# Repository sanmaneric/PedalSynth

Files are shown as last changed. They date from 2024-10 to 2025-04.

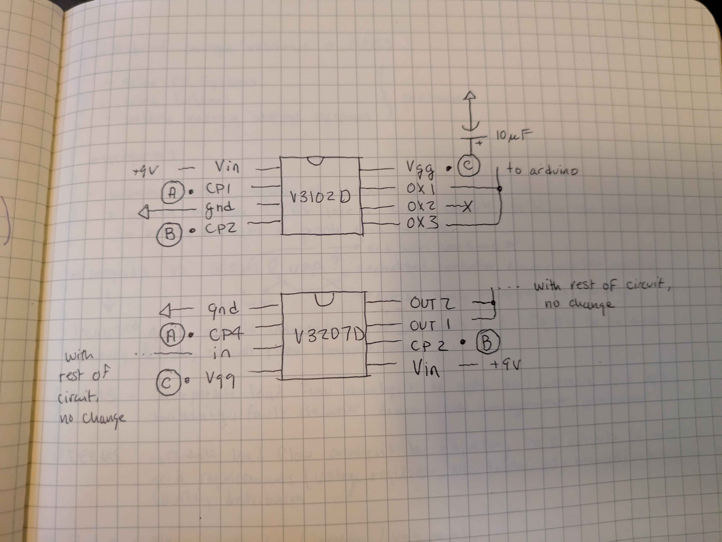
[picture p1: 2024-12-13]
Test Plan/chorus test plan.jpg

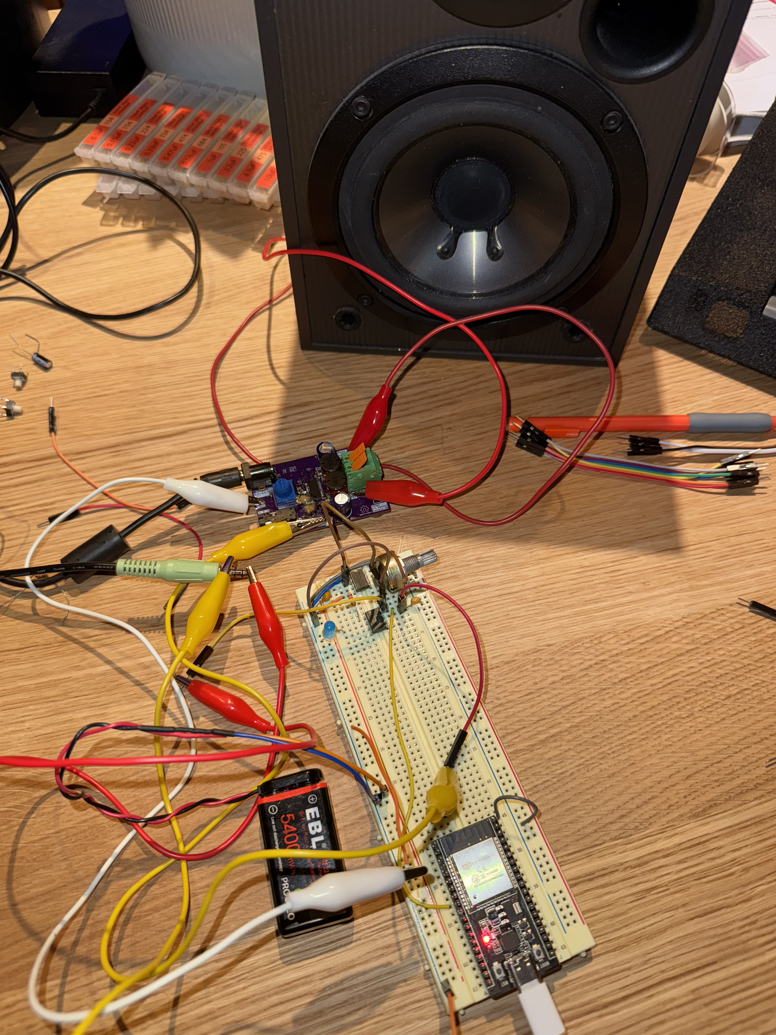
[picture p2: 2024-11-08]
Weekly Progress Reports/Progresss Photos/tremolo-mcu-amp-7Nov.jpg

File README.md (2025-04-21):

<h1 align="center">
  :notes: SynthBuddy :notes:
</h1>

<h2 align="center">
  A combination digital and analog synthesizer with integrated speaker amplifier.
</h2>

<div align="center">

  <a href="https://github.com/lifeparticle/Markdown-Cheatsheet/actions/workflows/readme-checker.yml">
    
  </a>

</div>

# PCB Designs
We have two KiCad projects in this repo. One for the Class-D Amp Dev Board (ordered week 2), and one for our project design. The naming of the KiCad project of the Dev Board is a misnomer.
 - [Amplifier Dev Board](https://github.com/sanmaneric/PedalSynth/tree/main/Electrical%20Design/PedalSynth)
 - [SynthBuddy Board](https://github.com/sanmaneric/PedalSynth/tree/main/Electrical%20Design/Modules/ECE%20411%20Project)

# Authors
PedalSynth is developed by Eric Sanman, Sierra Buckley, Chris Crider, and Chuong Vo as part of ECE411 at <a href="https://pdx.edu/engineering" style="color: green; text-decoration: underline;text-decoration-style: dotted;">Portland State University</a>
.

# License
SynthBuddy is licensed under a GNU/GPL v3 license.

# View Key Deliverables
Things Andrew would want to look at:
 - :white_check_mark: [View PDS](https://github.com/sanmaneric/PedalSynth/blob/main/Product%20Development/ProductDescriptionSpecification-Team8.rev1.2.pdf)
 - :date: [Browse Weekly Progress Reports](https://github.com/sanmaneric/PedalSynth/blob/main/Weekly%20Progress%20Reports/Weekly%20Progress%20Report.md)
  - :camera: [Progress Photos & Videos](https://github.com/sanmaneric/PedalSynth/tree/main/Weekly%20Progress%20Reports/Progresss%20Photos)
  - :date: [View Gantt Chart](https://github.com/sanmaneric/PedalSynth/blob/main/Gantt%20Chart/ECE%20411%20PWM%20Hybrid%20Synth%20Pedal.pdf)
 - :technologist: [View Code](https://github.com/sanmaneric/PedalSynth/tree/main/Programming)
 - :white_check_mark: [View KiCad PDF Exports](https://github.com/sanmaneric/PedalSynth/tree/main/Electrical%20Design/Docs)

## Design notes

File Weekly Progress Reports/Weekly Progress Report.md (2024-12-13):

# SynthBuddy Weekly Progress Report
## Report date: 2024-10-17

## Last Week (time in hours)
	- **Team Review**
		- We began to generate potential project ideas and discuss the best way to set up a collaboration site. A definitive project has already been chosen but generating additonal projects to "pick" is a bit more tricky then expected.
	- **Eric Sanman**
		- Began to set up collaboration site and look into using KiCad (3)
	- **Chuong Vo**
		- Began researching the best processor to use for the project and the differences between arduino microcontrollers and Atmel microcontrollers (2)
	- **Sierra Buckley **
		- watching kicad videos and becoming familiar with it (2)
		- researching effects pedals for our design (2)
	- **Chris Crider**
		- Began researching ideas for projects including effects for possible synth project (2)
		- learning kicad and git for use on the project (1)
	
##Next Week
	- **Team Plan**
		- Set up the collaboration site and finalize the proposal for three different projects and choose one.
		- Begin to brainstorm ideas and write the Product Design Specification
	- **Eric Sanman**
		- Become more familiar with Kicad and Markdown (3)
		- Begin to create a preliminary Class-D amplifier design in KiCad (4)
	- **Chuong Vo**
		- Finalize research of microcontrollers and report findings to team (2)
		- Choose a microcontrollers and begin research on potential libraries that could be used to for the synthesizer (2)
	- **Sierra Buckley**
		- choose filters to design, model in LTspice (4)
	- **Chris Crider**
		- Familiarized myself with the sites were using (.5)
		- began modeling effects circuits (2)
	
##Blocked
	- **Eric Sanman**
		- none
	- **Chuong Vo**
		- Nothing blocked
	- **Sierra Buckley**
		- none
	- **Chris Crider**

# PWM Hybrid Synth Weekly Progress Report
## Report date: 2024-10-24

## Last Week (time in hours)
	- **Team Review**
		- The collaboration site was officially launched and the three projects, pick one assignment was submitted
		- Work began on the Product Design Specification after a group meeting on 10-17-24 with good progress being made but it is still being written up.
	- **Eric Sanman**
		- Created collaboration site (1)
        - Gave team a basic introduction and overview of Git (1)
        - Continued to work on Class-D amplifier design in KiCad (finalize layout, ground stiching, etc.) (4)
        - Select and order parts for amplifier from DigiKey (2)
        - Ordered Class-D amplifier from OSH Park (.5)
	- **Chuong Vo**
		- Finalized microcontroller research and chose the best option to use for the Synth project (an ESP32 WRoom using Arduino) (2)
		- Began to looking into Arduino libaries for PWM and signal generation(1)
	- **Sierra Buckley**
		- chose filters to design, modeled in LTspice (4)
		- git tutorial from Eric :) (1)
		- also sick (?)
	- **Chris Crider**
		- Began designing schematics that would be put into final schematic (4)
		- researching libraries for esp32 to create pwm output (.5)
 		- worked on PDS (1)
	
##Next Week
	- **Team Plan**
		- Set up the collaboration site and finalize the proposal for three different projects and choose one.
		- Begin to brainstorm ideas and write the Product Design Specification
		- Begin assembling Breadboard Prototype
	- **Eric Sanman**
		- Receive board from OSH Park and parts from DigiKey (0)
        - Begin built & test of Class-D amplifier (4)
        - Work with the team on integrating other modules in KiCad (2)
	- **Chuong Vo**
		- Finalize research of Arduino libaries for PWM/Signal Generation (2)
		- Begin to watch tutorials to understand KiCad usage (2)
		- Begin making a basic schematic for the ESP32 (1)
	- **Sierra Buckley**
		- Redo work on PDS, block diagrams (2)
		- get healthy (?)
	- **Chris Crider**
		- Helped edit PDS (1)
		- began building prototype for tremolo and fuzz effects (3)
		- reviewing kicad to send over finalized effect schematics (2)
	
##Blocked
	- **Eric Sanman**
		- Wait for amplifier board to arrive
        - Wait for parts to arrive
	- **Chuong Vo**
		- Nothing blocked
	- **Sierra Buckley**
		- none
	- **Chris Crider**
		- none
	
# PWM Hybrid Synth Weekly Progress Report
## Report date: 2024-10-31

## Last Week (time in hours)
	- **Team Review**
		- The product design Specification was completed and added to both Canvas and Git
		- Work Began on a Design Matrix and AHP Methodologies to officially pick a project
		- Design work began on Kikad for the priliminary schematic of the synthesizer.
		- Began Testing individual circuit modules to ensure design works
		
	Eric Sanman
		- Received boards from OSH Park (0)
        - Received parts from DigiKey (0)
        - Try to build one amplifier (4)
        - Amplifier works great, but the input rolls-off low freq. too qucikly. Making adjustments to component values on board (1)
        - Update KiCad design based off of flaws (DC input, inductors wrong footprints), update schematic values (1)
		
	Chuong Vo
		- Finished watching Kikad tutorial Video (2)
		- Began to model seperate schematics on Kikad based on the chosen effects that the synthesizer can perform (1.5)
		- Began to write Arduino code for the PWM function (1)
		
	Sierra Buckley
		- redid PDS and block diagrams (2)
		- started breadboarding effects (2)
		- kicad adjustments (2)
		- team effort on BOM (2)
		
	Chris Crider
		- continued breadboard work on effects (3)
		- BOM (2)
		- Overall build rework (order of effects was off) (2)
	
##Next Week
	Team Plan
		- Finalize the Preliminary Schematic and have all team members check off schematic
		- Finalize Testing of individual modules and begin to combine into a singular circuit for testing
		- Begin to clean up Preliminary schematic and transition it into a Final Schematic
		- Begin creating a PCB layout based off of schematic
		
	Eric Sanman
		- Work with other team members on integrating parts into the schematic (2)
        - Clean up and add descriptions to modules in KiCad (.5)
        - Check titleblocks (.25)
        - Find footprints for all parts (3)
		
	Chuong Vo
		- Finish modeling the Effect schematics for the synthesizer and connect them all together before sending them over to Eric for quality assurance(2)
		- Continue to write Arduino code (1)
		- Create and fill out a Gantt Chart for the Project schedule (3)
		
	Sierra Buckley
		- continue kicad adjustments with new additions with team (2)
		- team effort on BOM (2)
		- continue breadboarding effects (2)
		
	Chris Crider
		- continued testing effects and refining schematics (2)
		- continued to take stock of parts needed (1)
	
##Blocked
	Team Blocks
		- Deciding how in fleshed out each of the effects for the Synth should be and the cost/return of doing more or less complex effects.
		
	Eric Sanman
		- Nothing
		
	Chuong Vo
		- Nothing blocked
		
	Sierra Buckley
		- effects are hard
		
	Chris Crider
		- nothing

# PWM Hybrid Synth Weekly Progress Report
#Report date: 2024-11-7

## Last Week (time in hours)
	Team Review
		- Finalized Schematic with Team Member sign off and added to both Git and Canvas
		- Combined all modules into one circuit and tested the combined circuit, uploading the Breadboard Prototype onto Git and Canvas 
		- Completed and signed off on ongoing project scheadule via Gantt Chart which was uploaded to both Git and Canvas
		- Began looking into surface mount components to be used on PCB
		
	Eric Sanman
        - Worked on adding fancier formatting to the schematics (1)
        - Generating priliminary board layout design for whole system (3)
        - Helped debug circuits (2)
	Chuong Vo
		- Create and fill out a Gantt Chart for the Project schedule (3)
		- Create ESP32 circuit and begin Testing Code (2)
	Sierra Buckley
		- circuit debugging and testing (8)
	Chris Crider
		- Helped with gannt chart layout (2)
		- matching kicad schematics to hand drawn and LTspice schematics locating errors and moving things where needed (3)

##Next Week
	Team Plan
		- Begin work on compiling together components onto a Bill of Materials
		- Finalize the circuit connections and compose a L0 and L1 Functional Decomposition
		- Begin to clean up CAD layout and add component traces
	Eric Sanman
        - Work on enhancing the layout in KiCad, adding (6):
            - Mounting holes
            - Cleaner amp routing
            - Add LEDs to board
            - Update schematic based on testing changes
            - Fix pin header, power jack, and inductor footprints
	Chuong Vo
		- Compile Bill of Materials and match components to Schmatic/PCB Layout (3)
		- Finalize and Test ESP32 Code (3)
		
	Sierra Buckley
		- functional decomposition (4)
		- continue debugging and testing (4)
		- finalize kicad changes (2)
	
	Chris Crider
		- began searching for needed parts for each effect, some are very specific to each tone (1)
		- refined button layout for final prototype to streamline usage (2)
	
##Blocked
	Team Blocks
		- Chorus module update for PCB
	Eric Sanman
		- Finaliztion of PCB depends on sucessful test of chorus module
	Chuong Vo
		- Finding components that are in stock and ship quickly
	Sierra Buckley
		- chorus is difficult to get working
		- components needed for testing (EPL)
	Chris Crider
		- helped debug chorus circuit (4)
	
# PWM Hybrid Synth Weekly Progress Report
#Report date: 2024-11-14 

## Last Week (time in hours)
	Team Review
		- The Functional Decomposition and Bill of Materials were finalized and added to both Canvas and Git.
		- The initial CAD was updated with components being put into place and traces were put into place. 
		
	Eric Sanman
        - Generated ESP32 pin tracking sheet for assisiting programming (1)
        - Tested and Debugged ESP32 Code and circuit (4)
        - Added bypass jumper/switch for the chrous module in case it ends up not working, updated PCB layout with change (2)
		
	Chuong Vo
		- Compile Bill of Materials and match components to Schmatic/PCB Layout (4)
		- Finalize and Test ESP32 Code with respective circuit (3)
	
	Sierra Buckley
		- functional decomposition complete (4)
		- tested and debugged code and circuit (4)
	Chris Crider
		- helped with functional decomp (1)
		- Debugging code for PWM (1)
		- Testing functionality (3)
	
##Next Week
	Team Plan
		- Finalize the CAD Schematic by adding finishing touches to the traces and ensure the correct components are used
		- Get Designed Reviewed by two other teams and review the designs of the two teams
		- Place PCB order at OSH Park
        - Place part order from DigiKey/Tayda Electronics
		- Wait in Anticipation

	Eric Sanman
        - Add mounting holes to PCB (1)
        - Optimize board layout to minimize board area (3)
        - Final footprint check, update (2)
        - Worked with Sierra to add test points to the board for debugging of the chorus module (1)
        - Finishing touches to PCB (2)
	Chuong Vo
		- Provide Design review comments for other groups and get Schematic and PCB design reviewed (2.5)
		- Verify Final Schematic and PCB design and sign off on completion (2)
	Sierra Buckley
		- test points with Eric (1)
		- finalize changes from debugging (2)
		- helping with week 8 assignments to turn in (2)
	Chris Crider
		- Design review for other groups (2)
		- continued debugging chorus (3)
		- opted for test points on final project because the debugging was complicated (1)

##Blocked
	Team Blocks
		- Waiting on parts for testing
	Eric Sanman
		- Nothing blocked
	Chuong Vo
		- Nothing blocked	
	Sierra Buckley
		- none
	Chris Crider
		- none

# PWM Hybrid Synth Weekly Progress Report
# Report date: 2024-11-21 

## Last Week (time in hours)
	Team Review
		- Finalized CAD Schematic and PCB Layout
		- Design Reviewed and got reviewed by Team 9 and Team 12
		- Sent Finzlized PCB over to OSH Park to be fabricated.
		
	Eric Sanman
		- Worked with the team to implement final circuit changes to the PCB (3)
		- Export files for fabrication (.25)
		- Order PCB!!! (.5)
	Chuong Vo
		- Design Reviewed Teams 9 and 12 (3)
		- Quality check and Finalized PCB (2)
	
	Sierra Buckley
		- design review with 2 teams (3)
		- PCB finalization with team (2)

	Chris Crider
		- worked through final amount of debugging and rearranging parts for effects (2)
		- began testing OLED and PWM functions in unison with effects (2)

##Next Week
	Team Plan
		- Coordinate and pick a time to do presentation
		- Begin to plan what to do/say in presentation.
		- Wait for PCB to arrive for build and test

	Eric Sanman
		- Wait for PCB to arrive (time n/a)
		- Wait for parts to arrive (time n/a)
		- (taking break from project for a mideterm & thanksgiving during this time)
	Chuong Vo
		- Sign up for Demo time (1)
		- Wait in anticipation for PCB and parts to arrive 
	Sierra Buckley
		- thanksgiving week, sign up for demo time (1)
	
	Chris Crider
		- Thanksgiving no meetings
	
##Blocked
	Team Blocks
		-Finding time that works for all times to coordinate design reviews.
	Eric Sanman
		- Wait for parts
	Chuong Vo
		- Nothing blocked
		
	Sierra Buckley
		- none

	Chris Crider

# PWM Hybrid Synth Weekly Progress Report
# Report date: 2024-11-28

## Last Week (time in hours)
	Team Review
		- Received PCB back from OSH Park and began to build
		- No real Progress or meetings due to thanksgiving
		
	Eric Sanman
		- No work on break (0)
		
	Chuong Vo
		- Thanksgiving break, the team did not meet
	
	Sierra Buckley
		- thanksgiving week!

	Chris Crider
		- Thanksgiving, didn't meet

##Next Week
	Team Plan
		- Begin to discuss and build PCB housing
		- Continue to assemble/Solder PCB
		- Begin Testing PCB to ensure that each component and module works as intended.

	Eric Sanman
		- Work with the team to come up with the test plan. (2)
		- Teach team how to SMD solder with spare amp boards, assemble and help team assemble the board (6)
	Chuong Vo
		- Create Test Plan for finalized project (3)
		- Began to solder surface mounted components onto PCB. (2)

	Sierra Buckley
		- test plan working with team (3)
	
	Chris Crider
		- Began soldering components such as potentiometers to attach to board (3)
		- began researching best method of housing (1)
		- overseeing IC placement on board (3)

##Blocked
	Team Blocks
		- Waiting on Components and PCB to arrive. 
	Eric Sanman
	
	Chuong Vo
		-Nothing Blocked
	
	Sierra Buckley
		- none

	Chris Crider

# PWM Hybrid Synth Weekly Progress Report
# Report date: 2024-12-05

## Last Week (time in hours)
	Team Review
		- Completed Test plan for when the board is fully assembled
		- Finalized the soldering of all the surface mounted components
		- Began doing quality checks and testing of surface mounted components
		
	Eric Sanman
		- Testing board in capstone lab with Chris, mostly worked the first time (4)
		- Placed second DigiKey order with part changes from bodging w/ two-day shipping (1)
		
	Chuong Vo
		- Creating a test plan that ensures the modules are properly tested for their intended effects (3)
		- Soldering components onto PCB (2)
		- Began to Test PCB by sending a function generated signal through and reading outputs using (2)
	
	Sierra Buckley
		- test plan working with team (3)

	Chris Crider
		- Began presentation editing (2) 
		- Testing working prototype in capstone lab (lots of noise) (3)
		- finalized ideas for button and pot layout (1)

##Next Week
	Team Plan
		-Complete the Assembly of the PCB
		-Complete all testing for the PCB
		-Create Case for PCB
		-Create Presentation Slideshow

	Eric Sanman
		- Swap parts with parts from second Digi-Key order (2)
		- Final assembly changes (1)
		- Pass board off to Sierra for debug (0)
		- Give dimensions to Sierra for plexiglass enclosure (.5)
	Chuong Vo
		- Finalize the assembly of the PCB (3)
		- Thouroughly Test every module of the project and debug where necessary (6)
		- Complete the Presentation Slides (4)
		- Complete Catme Survey (1) 
		
	Sierra Buckley
		- testing with everything (8)
		- build case (4)
		- debug (4)
		- complete presentation slides (8)
		- catme survey (1)
	
	Chris Crider
		- Final testing of unified design (3)
		- Survey (2)
		- Presentation (3)
		- Final build (2) 

##Blocked
	Team Blocks
		- none
		
	Eric Sanman
		- none
		
	Chuong Vo
		-Nothing Blocked
	
	Sierra Buckley
		- none

	Chris Crider
		- none
		
# PWM Hybrid Synth Weekly Progress Report
# Report date: 2024-12-12

## Last Week (time in hours)
	Team Review
	 - last progress report!
		- Completed the Assembly of the PCB
		- Completed all testing for the PCB
		- Created Case for PCB
		- Created and in the process of finalizing the Presentation Slideshow
		
	Eric Sanman
		- Final assembly of project (8)
		- Helping team with odds and ends of project (documentation, etc.) (4)
		
	Chuong Vo
		- Began to Test PCB by sending a function generated signal through and reading outputs using Oscilloscope (2)
		- Finalize PCB assembly (4)
		- Thouroughly Test every module of the project and debug where necessary (6)
		- Complete the Presentation Slides (4)
		- Complete Catme Survey (1)
	
	Sierra Buckley
		- testing with everything (8)
		- build case (4)
		- debug (4)
		- complete presentation slides (8)
		- catme survey (1)

	Chris Crider
		- More final assembly (1)
		- Soldering and testing (2)
		- Paperwork (1)
	
##Next Week
	Team Plan
		- Practice for Demo Presentation
		- Demo Presentation

	Eric Sanman
		- Practice part of presentation for Friday
		- Make sure everything is ready to go 
		
	Chuong Vo

	Sierra Buckley
		- practice presentation for Friday
		- end of term
	
	Chris Crider
		- Practice presentation

##Blocked
	Team Blocks
		- none
		
	Eric Sanman
		- none
		
	Chuong Vo
		- Nothing Blocked
		
	Sierra Buckley
		- none

	Chris Crider
		- none

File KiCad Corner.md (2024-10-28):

<h1 align="center">
  :sparkles: KiCad Corner :) :sparkles:
</h1>

<h2 align="center">
  Welcome to KiCad Corner! This document is full of KiCad tips and tricks! Add to this document as you find useful keyboard shortcuts, etc.
</h2>

<div align="center">

  <a href="https://github.com/lifeparticle/Markdown-Cheatsheet/actions/workflows/readme-checker.yml">
    
  </a>

</div>

# :round_pushpin: Start Here: Videos
## Watch these videos to learn how to use KiCad in this order:
 1. [PcbCupid - Beginner: Learn KiCad in 2 hours](https://www.youtube.com/watch?v=KgmsvopC9Qk)
 2. [Phil's Lab - A bit more advnanced: STM32 PCB Design Example](https://www.youtube.com/watch?v=aVUqaB0IMh4)
 
## Other Useful KiCad Videos:
-  [ElectrArc240 - Making Neat Schematics & Working with Multiple Sheets](https://www.youtube.com/watch?v=_iz7rFTQ4Ec)

# Schematic Editor
## Keyboard Shortcuts:
|Key| What Do |
|---|---|
|V  |Change part info|
|W  |Lay down wire|
|E  |Open properties panel where mouse is|
|Q  |Put no connect where mouse is|
|Insert|Keep filling no connects (or the last used thing) down a package|
</td></tr> </table>

# PCB Editor
## Keyboard Shortcuts:
|Key| What Do |
|---|---|
|D  |Moves tracks and vias around|
|U  |Select entire track|
|B  |Fill all copper zones|
|D  |(D)rag a trace or part|
|H  |Hide or darken the inavtice layer|

# General PCB Tips:
## Standard SMD Sizes (Hand Solder Doable)
 - 0402 (smallest)
 - 0602 (medium)

## Larger SMD Sizes (Use for larger values C/L, ferrite beads, etc.)
 - 0805
 
 ## Good Standard Via Size
  - Size: 0.7mm
  - Hole: 0.3mm

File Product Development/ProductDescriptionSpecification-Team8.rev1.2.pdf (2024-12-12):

Team 8 - Voltage Vanguard
14 November 2024
Sierra Buckley
Chuong Vo
Eric Sanman
Chris Crider

### Practicum Product Design Specification (PDS) Outline Rev 1.2

Short Descriptive Name: PWM Hybrid Analog/Digital Synthesizer & Audio Amplifier with Built-In Display

Executive Summary with Concept of Operations (2 pts)

The PWM synthesizer is a hybrid analog and digital audio processing device in the form factor of a guitar pedal. It functions as a synthesizer with one octave(11 manual inputs). These inputs modulate the synthesizer's analog and digital effects. This device will create the ability for a musician to interact with effects typically found in guitar pedals in a unique way. The synthesizer will connect to a standard 9V power supply that is standard on a pedal board.

An example of how this product would be used: One person can be manipulating the synth, pressing each button/switch to change the frequency that the microcontroller sends to the effects. Either with relays or switches, the microcontroller would be able to control none, one or a combination of effects that turn on, and this output goes to a speaker. The OLED display may show the effects that are turned on, the buttons that are switched on, or any other information that the user would find relevant.

Brief “Market” Analysis (2 pts)
The intended customer demographic for the PWM synth would be entry level music enthusiasts or those looking to get into music production. The competition is a multitude of audio effects companies. Our product is different because it’s locally designed and crafted, and creates a combination of effects that are typically uncommon and often do not come on a singular device. Market price for similar products can start at around $100 upwards. To market this product and stay competitive, we could start the price of the synthesizer at $75 for the base model and increase the price as more components are added.

Requirements (4 pts)
Must:
- Must be powered using 9V
- Must be in a nice-looking form factor
- Must have amplifiers to amplify input signals
- Must have adjustable potentiometers and buttons/switches to change effects
- Must have at least 2 analog effects
- Must have a audio output that a speaker can be connected to
- Must have digital control using a microcontroller, at least one waveform
- Must have a display, OLED or LED
Should:
- Should use a MIDI keyboard to control the synth
- Should have a high quality metal case
- Should have the microcontroller produce multiple waveforms or additional digital effects May:
- May be battery powered
- May have more than 2 analog effects
- May be cat themed
- May cost less than $75

System Architecture (4 pts)

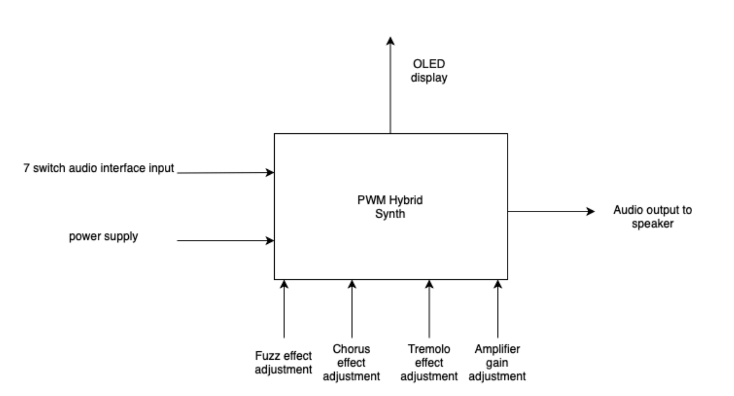
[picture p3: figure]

Figure 1: Level 0 block diagram

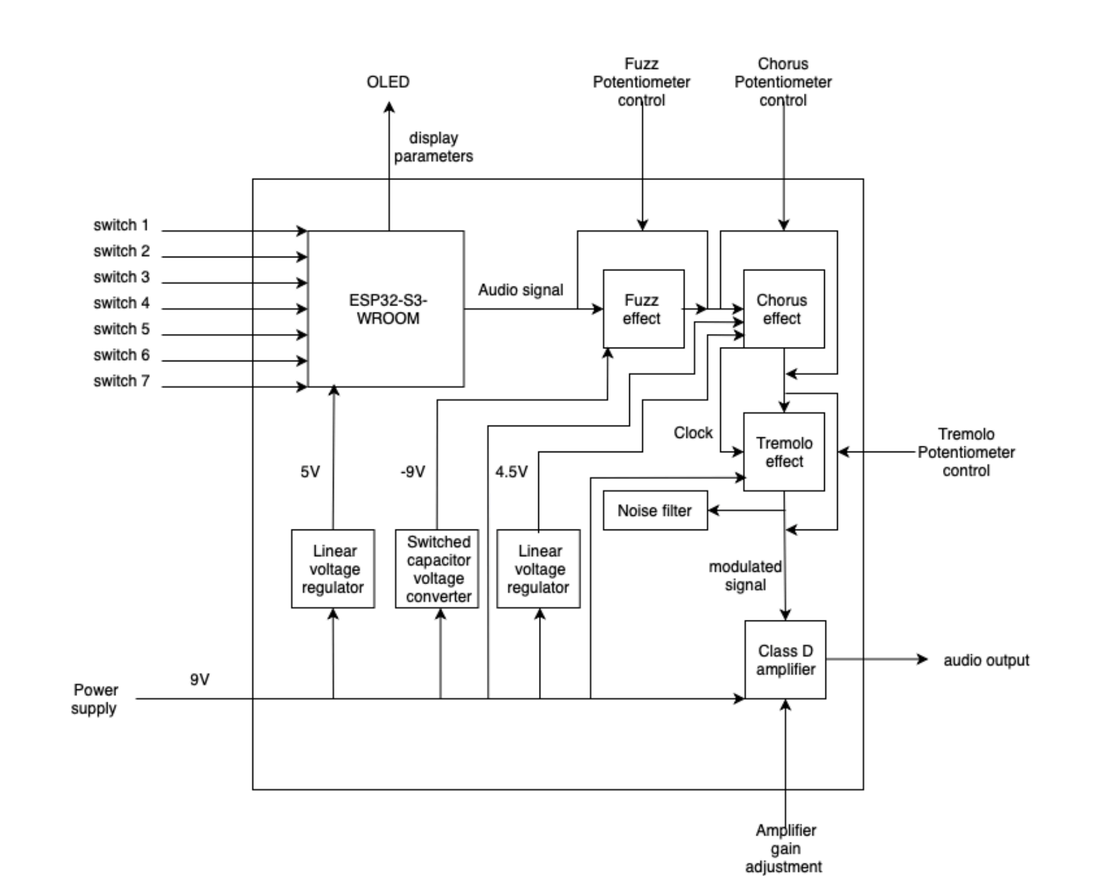
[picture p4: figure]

Figure 2: Level 1 block diagram

Design Specification (4 pts)
- Actuators
- Outputs (speaker amp and line-level audio)
- Displays
- OLED or LED (ex: 9x9 Matrix)
- Sensors
- Human input
- Potentiometer
- Buttons
- Toggle Switches
- Controllers
- ESP32-S3-WROOM (tentative)
- Analog discrete logic
- OP amps (filter, feedback, etc)

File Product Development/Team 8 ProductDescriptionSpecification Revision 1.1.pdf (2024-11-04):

Team 8 - Voltage Vanguard
31 October 2024
Sierra Buckley
Chuong Vo
Eric Sanman
Chris Crider

### Practicum Product Design Specification (PDS) Outline Rev 1.1

Short Descriptive Name: PWM Hybrid Analog/Digital Synthesizer with built in display

Executive Summary with Concept of Operations (2 pts)

The PWM synthesizer is a hybrid analog and digital audio processing device in the form factor of a guitar pedal. It functions as a synthesizer with one octave(11 manual inputs). These inputs modulate the synthesizer's analog and digital effects. This device will create the ability for a musician to interact with effects typically found in guitar pedals in a unique way. The synthesizer will connect to a standard 9V power supply that is standard on a pedal board.

An example of how this product would be used: One person can be manipulating the synth, pressing each button/switch to change the frequency that the microcontroller sends to the effects. Either with relays or switches, the microcontroller would be able to control none, one or a combination of effects that turn on, and this output goes to a speaker. The OLED display may show the effects that are turned on, the buttons that are switched on, or any other information that the user would find relevant.

Brief “Market” Analysis (2 pts)
The intended customer demographic for the PWM synth would be entry level music enthusiasts or those looking to get into music production. The competition is a multitude of audio effects companies. Our product is different because it’s locally designed and crafted, and creates a combination of effects that are typically uncommon and often do not come on a singular device. Market price for similar products can start at around $100 upwards. To market this product and stay competitive, we could start the price of the synthesizer at $75 for the base model and increase the price as more components are added.

Requirements (4 pts)
Must:
- Must be powered using 9V
- Must have a Guitar pedal form factor
- Must have amplifiers to amplify input signals
- Must have adjustable potentiometers and buttons/switches to change effects
- Must have at least 2 analog effects
- Must have a audio output that a speaker can be connected to
- Must have digital control using a microcontroller, at least one waveform
- Must have a display, OLED or LED
Should:
- Should use a MIDI keyboard to control the synth
- Should have a high quality metal case
- Should have the microcontroller produce multiple waveforms or additional digital effects May:
- May be battery powered
- May have more than 2 analog effects
- May be cat themed
- May cost less than $75

System Architecture (4 pts)

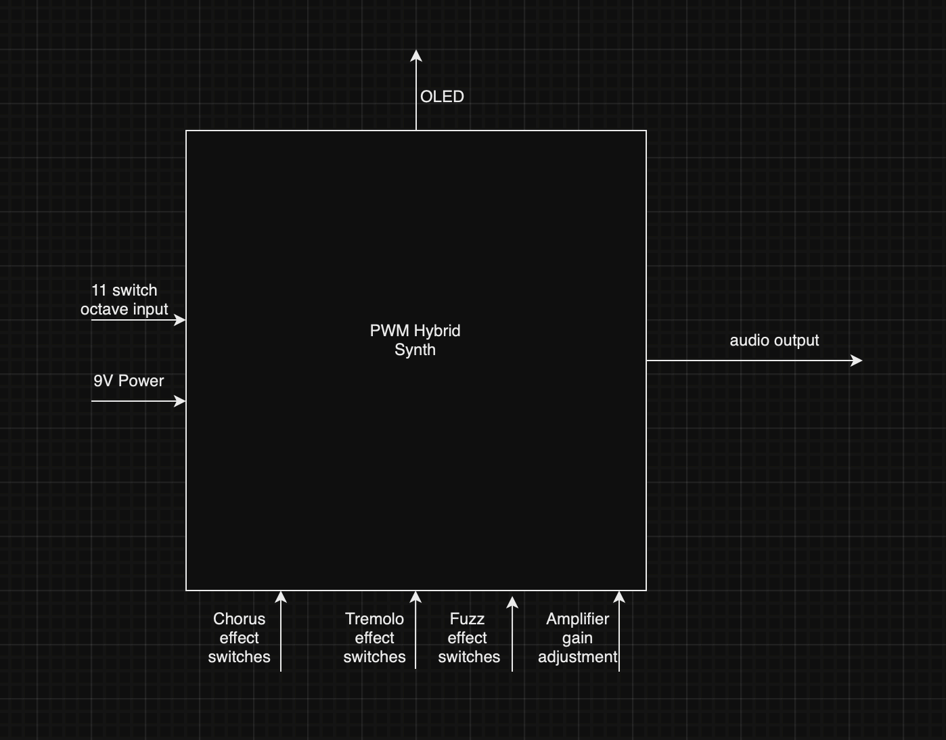
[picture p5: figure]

Figure 1: Level 0 block diagram

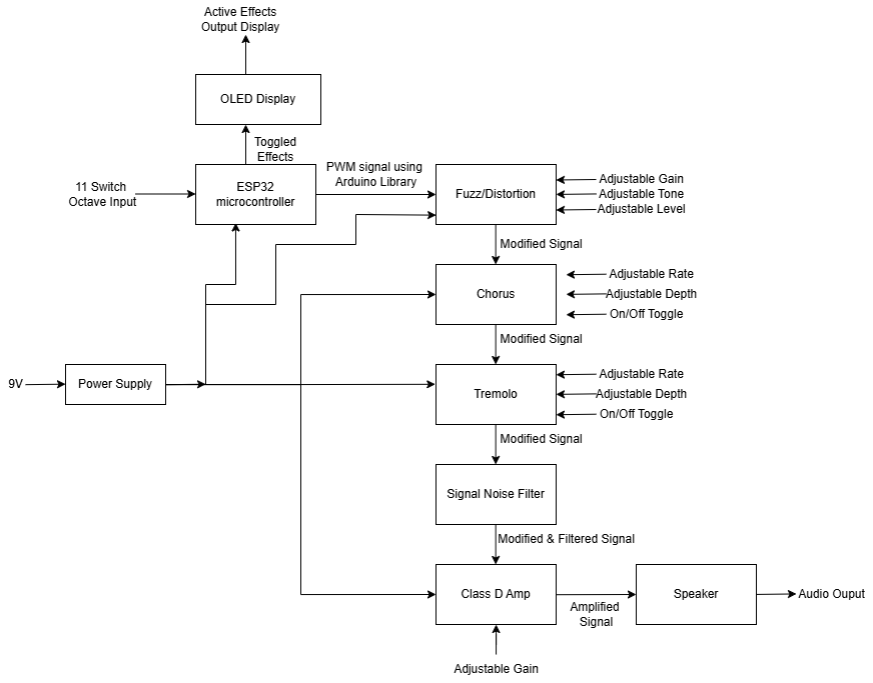
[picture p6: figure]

Figure 2: Level 1 block diagram

Design Specification (4 pts)
- Actuators
- Outputs (speaker amp and line-level audio)
- Displays
- OLED or LED (ex: 9x9 Matrix)
- Sensors
- Human input
- Potentiometer
- Buttons
- Toggle Switches
- Controllers
- ESP32-S3-WROOM (tentative)
- Analog discrete logic
- OP amps (filter, feedback, etc)

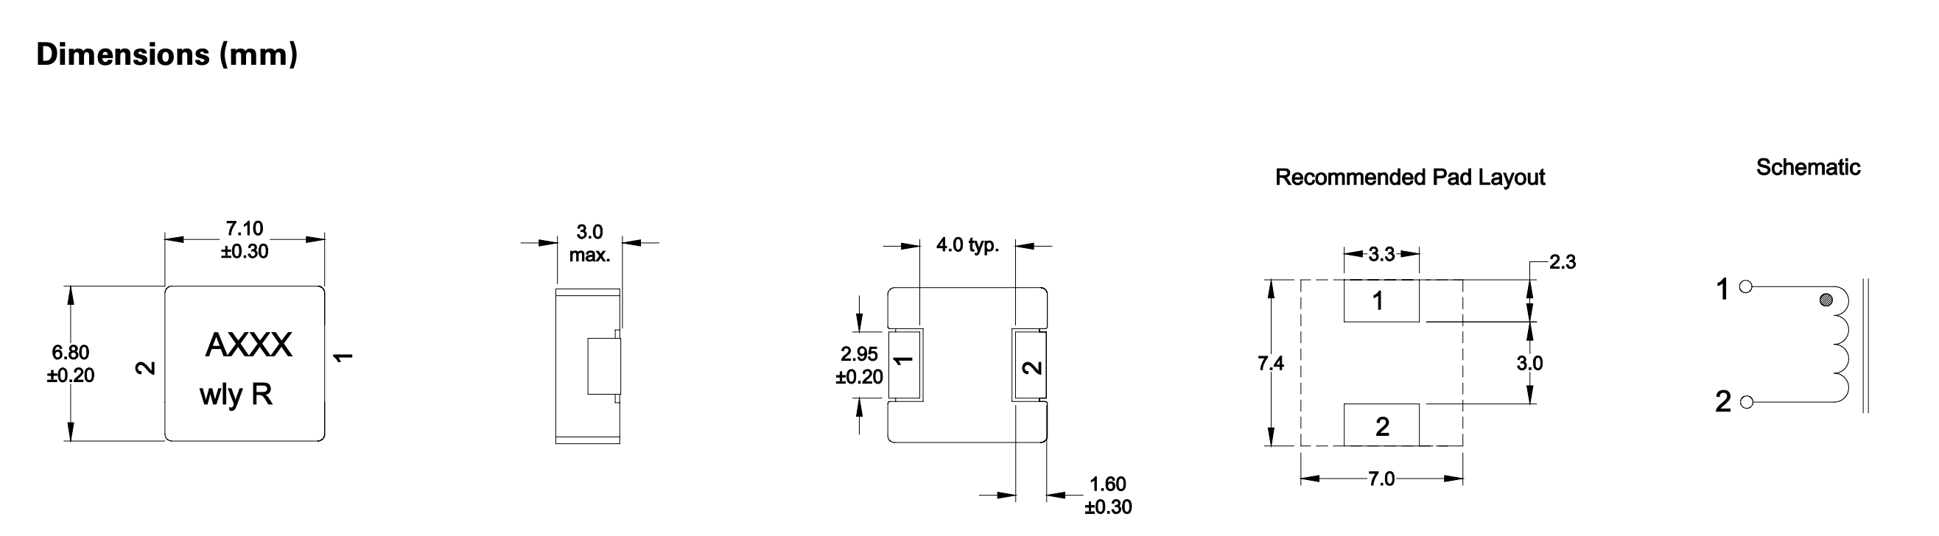
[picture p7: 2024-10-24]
Electrical Design/Datasheets/hc9-330-r.png

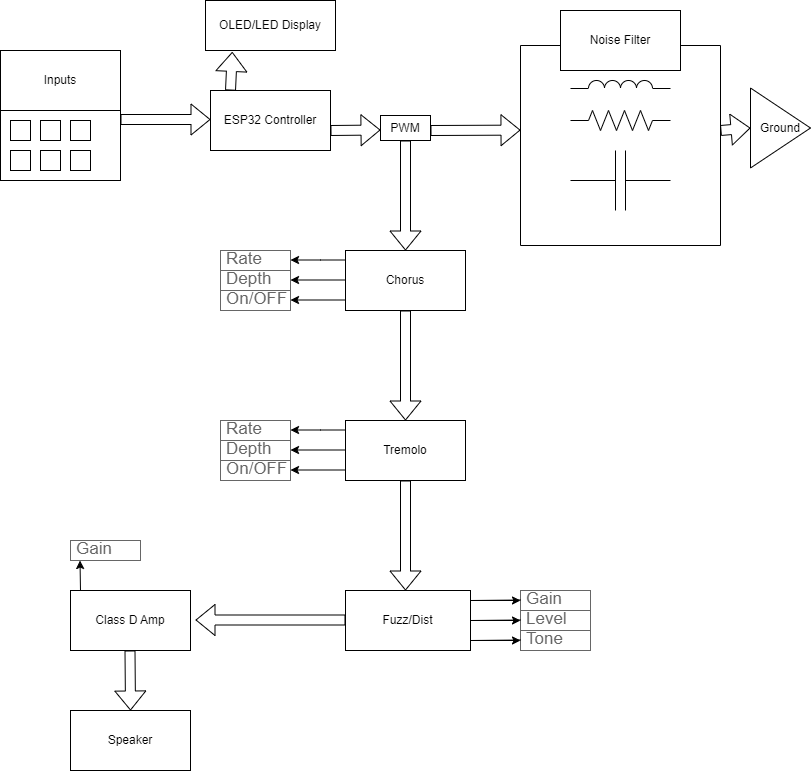
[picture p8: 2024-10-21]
Diagrams/Level 1 Decomp.png

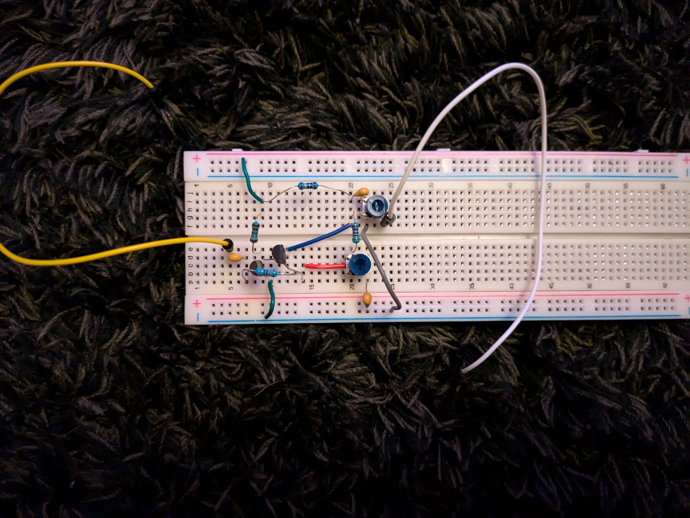
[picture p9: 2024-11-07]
Diagrams/fuzzbreadboard.rev0.jpg

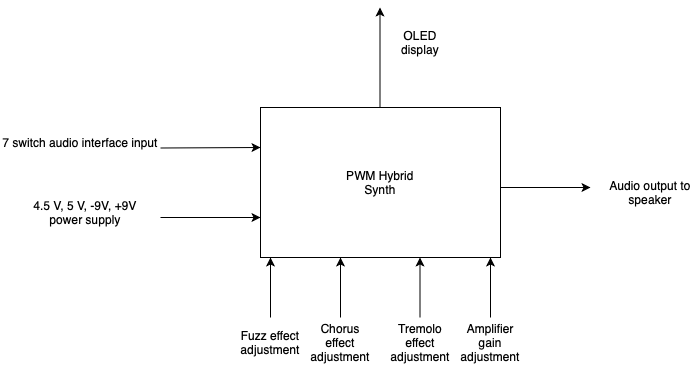
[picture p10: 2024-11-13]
Diagrams/Level 0 Diagram - Rev 2.drawio.png

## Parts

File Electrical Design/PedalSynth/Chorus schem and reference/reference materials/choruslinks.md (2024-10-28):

https://modwiggler.com/forum/viewtopic.php?t=135819
(BDD schematic)
https://anasounds.com/working-analog-chorus-effect-boss-ce2/
(How a chorus effect works)
https://www.electrosmash.com/mn3007-bucket-brigade-devices
(How a BDD works)

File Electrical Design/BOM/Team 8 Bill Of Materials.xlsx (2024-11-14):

Bill Of Materials for: Team 8 (Voltage Vanguards)
Last modified: 13 November 2024
PCB version: 2
BOM revision: 2 |  | P/NP | = Place/Not Place (components marked NP are not stuffed on the board)
Cnt | Part References | P/NP | Mfg | Mfg PN | Description | Dist | Dist Part Number | Cost Ea. | Cost Total
2 | C8, C22 | P | Nichicon | UVR2C100MPD | 10 µF 160 V Aluminum Electrolytic Capacitors Radial, Can 2000 Hrs @ 85°C | Digi-Key | 493-1161-ND | $0.33 | $0.66
1 | C5 | P | Nichicon | UVK2A470MPD | 47 µF 100 V Aluminum Electrolytic Capacitors Radial, Can 2000 Hrs @ 85°C | Digi-Key | 493-6068-ND | $0.32 | $0.32
1 | C11 | P | KYOCERA AVX | KGM21NR71H683KT | 0.068 µF ±10% 50V Ceramic Capacitor X7R 0805 (2012 Metric) | Digi-Key | 478-KGM21NR71H683KTCT-ND | $0.10 | $0.10
1 | C2 | P | Samsung Electro-Mechanics | CL31B475KAHNNNE | 4.7 µF ±10% 25V Ceramic Capacitor X7R 1206 (3216 Metric) | Digi-Key | 1276-1055-2-ND | $0.17 | $0.17
2 | C4,C6 | P | Samsung Electro-Mechanics | CL21B106KOQNNNG | 10 µF ±10% 25V Ceramic Capacitor X7R 1206 (3216 Metric) | Digi-Key | 1276-1055-1-ND | $0.17 | $0.34
2 | C1, C10 | P | Samsung Electro-Mechanics | CL21B473KBCNNNC | 0.047 µF ±10% 50V Ceramic Capacitor X7R 0805 (2012 Metric) | Digi-Key | 1276-1250-2-ND | $0.10 | $0.20
1 | C12 | P | Samsung Electro-Mechanics | CL21B334KBFNNNE | 0.33 µF ±10% 50V Ceramic Capacitor X7R 0805 (2012 Metric) | Digi-Key | 1276-1250-1-ND | $0.10 | $0.10
3 | C7,C26,C27 | P | Samsung Electro-Mechanics | CL21B104KCFNNNE | 0.1 µF ±10% 100V Ceramic Capacitor X7R 0805 (2012 Metric) | Digikey | 1276-6840-1-ND | $0.10 | $0.30
1 | C20 | P | KEMET | C0805C682J1GEC7210 | 6800 pF ±5% 100V Ceramic Capacitor C0G, NP0 0805 (2012 Metric) | Digi-Key | 399-C0805C682J1GEC7210CT-ND | $0.27 | $0.27
2 | C15,C18 | P | KEMET | C0805C471K5RAC7800 | 470 pF ±10% 50V Ceramic Capacitor X7R 0805 (2012 Metric) | Digi-Key | 399-C0805C471K5RAC7800TR-ND | $0.10 | $0.20
2 | C16,C19 | P | KEMET | C0805C333K1RECAUTO | 0.033 µF ±10% 100V Ceramic Capacitor X7R 0805 (2012 Metric) | Digi-Key | 399-C0805C471K5RAC7800CT-ND | $0.10 | $0.20
2 | C13,C41 | P | KEMET | C0805C332K1RECAUTO | 3300 pF ±10% 100V Ceramic Capacitor X7R 0805 (2012 Metric) | Digi-Key | 399-C0805C332K1RECAUTOCT-ND | $0.26 | $0.52
2 | C14,C17 | P | KEMET | C0402C822K1RACAUTO | 8200 pF ±10% 100V Ceramic Capacitor X7R 0402 (1005 Metric) | Digi-Key | 399-C0402C822K1RACAUTOCT-ND | $0.21 | $0.42
2 | C34,C35 | P | Samsung Electro-Mechanics | CL21B474KAFNNNE | 0.47 µF ±10% 25V Ceramic Capacitor X7R 0805 (2012 Metric) | Digi-Key | 1276-1074-2-ND | $0.10 | $0.20
7 | C21,C23,C28,C32,C36,C37,C43 | P | Samsung Electro-Mechanics | CL21B105KAFNNNE | 1 µF ±10% 25V Ceramic Capacitor X7R 0805 (2012 Metric) | Digi-Key | 1276-1066-1-ND | $0.10 | $0.70
3 | C42,C24,C25 | P | Nichicon | UVR1H101MPD1TD | 100 µF 50 V Aluminum Electrolytic Capacitors Radial, Can 2000 Hrs @ 85°C | Digi-Key | 493-5916-1-ND | $0.34 | $1.02
1 | C40 | P | Cal-Chip Electronics, Inc. | GMC31X7R226M10NT | CAP1206 X7R 22UF 20% 10V | Digi-Key | 4713-GMC31X7R226M10NTCT-ND | $0.27 | $0.27
1 | C39 | P | KEMET | C0805C103K5RACTU | 10000 pF ±10% 50V Ceramic Capacitor X7R 0805 (2012 Metric) | Digi-Key | 399-C0805C103K5RACTUCT-ND | $0.10 | $0.10
1 | C38 | P | Samsung Electro-Mechanics | CL21B225KPFNNNE | 2.2 µF ±10% 10V Ceramic Capacitor X7R 0805 (2012 Metric) | Digi-Key | 1276-1188-1-ND | $0.10 | $0.10
2 | C33,C31 | P | YAGEO | CC0805KRX7R9BB104 | 0.1 µF ±10% 50V Ceramic Capacitor X7R 0805 (2012 Metric) | Digi-Key | 311-1140-1-ND | $0.10 | $0.20
2 | C29,C30 | P | Samsung Electro-Mechanics | CL21B102KCANNNC | 1000 pF ±10% 100V Ceramic Capacitor X7R 0805 (2012 Metric) | Digi-Key | 1276-1169-1-ND | $0.10 | $0.20
3 | V3207D1,V3207D2,U3 | P | Coolaudio | V3207D - BBD IC | V3207D - BBD IC | stompboxparts | IC-400-1033 | $3.70 | $11.10
1 | U11 | P | Espressif | ESP32-WROOM | ESP-WROOM-32 ESP32 ESP-32S Development Board 2.4GHz Dual-Mode WiFi + Bluetooth Dual Cores Microcontroller Processor Integrated with Antenna RF AMP Filter AP STA Compatible with Arduino IDE | Amazon | Amazon | $3.00 | $3.00
1 | U9 | P | TI | TPA3136D2PWPR | IC AMP CLASS D STER 10W 28HTSSOP | Digi-Key | 296-44601-1-ND | $1.31 | $1.31
1 | U5 | P | Lite-on Inc. | LTV-827 | OPTOISOLATOR 5KV 2CH TRANS 8-DIP | Digi-Key | 160-1368-5-ND | $0.64 | $0.64
1 | U4 | P | TI | NE555D | 555 Type, Timer/Oscillator (Single) IC 100kHz 8-SOIC | Digi-Key | 296-16792-ND | $0.89 | $0.89
1 | U2 | P | TI | LT1054IDW | Charge Pump Switching Regulator IC Positive or Negative Adjustable (Fixed) 3.5V (-Vin, 2Vin) 1 Output 100mA 16-SOIC (0.295", 7.50mm Width) | Digi-Key | 296-9592-5-ND | $2.81 | $2.81
1 | U1 | P | UMW | HT7333-A | Linear Voltage Regulator IC Positive Fixed 1 Output 150mA SOT-89-3 | Digi-Key | 4518-HT7333-ACT-ND | $0.65 | $0.65
9 | SW1,SW2,SW3,SW4,SW5,SW6,SW7,SW8, J2 | P | Adam Tech | PH1-02-UA | CONN HEADER VERT 2POS 2.54MM | Digi-Key | 2057-PH1-02-UA-ND | $0.10 | $0.90
6 | RV1,RV2,RV3,RV4,RV5,RV6 | P | Adam Tech | PH1-03-UA | CONN HEADER VERT 3POS 2.54MM | Digi-Key | 2057-PH1-03-UA-ND | $0.10 | $0.60
1 | R47 | P | YAGEO | RC0805JR-078K2L | 8.2 kOhms ±5% 0.125W, 1/8W Chip Resistor 0805 (2012 Metric) Moisture Resistant Thick Film | Digi-Key | 311-8.2KARCT-ND | $0.10 | $0.10
1 | R45 | P | Stackpole Electronics Inc | RMCF0805JT33K0 | 33 kOhms ±5% 0.125W, 1/8W Chip Resistor 0805 (2012 Metric) Automotive AEC-Q200 Thick Film | Digi-Key | RMCF0805JT33K0CT-ND | $0.10 | $0.10
1 | R39 | P | YAGEO | RC0805FR-071KL | 1 kOhms ±1% 0.125W, 1/8W Chip Resistor 0805 (2012 Metric) Moisture Resistant Thick Film | Digi-Key | 311-1.00KCRCT-ND | $0.10 | $0.10
2 | R36,R48 | P | TE Connectivity Passive Product | CRGCQ0805J470R | 470 Ohms ±5% 0.125W, 1/8W Chip Resistor 0805 (2012 Metric) Automotive AEC-Q200, Moisture Resistant Thick Film | Digi-Key | A130132CT-ND | $0.10 | $0.20
1 | R28 | P | Panasonic Electronic Components | ERJ-6GEYJ334V | 330 kOhms ±5% 0.125W, 1/8W Chip Resistor 0805 (2012 Metric) Automotive AEC-Q200 Thick Film | Digi-Key | P330KACT-ND | $0.10 | $0.10
1 | R27 | P | Vishay Dale | CRCW08054K70FKEAC | 4.7 kOhms ±1% 0.125W, 1/8W Chip Resistor 0805 (2012 Metric) Thick Film | Digi-Key | 541-4131-1-ND | $0.10 | $0.10
5 | R22,R37,R40,R43,R46 | P | YAGEO | RC0805FR-07100KL | 100 kOhms ±1% 0.125W, 1/8W Chip Resistor 0805 (2012 Metric) Moisture Resistant Thick Film | Digi-Key | 311-100KCRCT-ND | $0.10 | $0.50
1 | R16 | P | YAGEO | RC0805JR-071ML | 1 MOhms ±5% 0.125W, 1/8W Chip Resistor 0805 (2012 Metric) Moisture Resistant Thick Film | Digi-Key | 311-1.0MARCT-ND | $0.10 | $0.10
1 | R8 | P | KOA Speer Electronics, Inc. | RK73B2ATTD563J | 56 kOhms ±5% 0.25W, 1/4W Chip Resistor 0805 (2012 Metric) Automotive AEC-Q200 Thick Film | Digi-Key | 2019-RK73B2ATTD563JCT-ND | $0.10 | $0.10
15 | R4,R5,R6,R10,R17,R19,R20,R23,R24,R25,R26,R30,R31,R32,R35 | P | Stackpole Electronics Inc | RMCF0805FT10K0 | 10 kOhms ±1% 0.125W, 1/8W Chip Resistor 0805 (2012 Metric) Automotive AEC-Q200 Thick Film | Digi-Key | RMCF0805FT10K0CT-ND | $0.10 | $1.50
5 | R3,R7,R18,R21,R34 | P | Stackpole Electronics Inc | RMCF0805JT47K0 | 47 kOhms ±5% 0.125W, 1/8W Chip Resistor 0805 (2012 Metric) Automotive AEC-Q200 Thick Film | Digi-Key | RMCF0805JT47K0CT-ND | $0.10 | $0.50
2 | R1,R2 | P | TE Connectivity Passive Product | CRG0805F1K2 | 1.2 kOhms ±1% 0.125W, 1/8W Chip Resistor 0805 (2012 Metric) Thick Film | Digi-Key | A126346CT-ND | $0.10 | $0.20
1 | Q5,Q6 | P | PMMCON | AC128 | Pcs of 2 New, AC128 PNP Transistor | Amazon | Amazon | $12.15 | $12.15
3 | Q2,Q3,Q4 | P | Diotec Semiconductor | 2N3904 | Bipolar (BJT) Transistor NPN 40 V 200 mA 300MHz 625 mW Through Hole TO-92 | Digi-Key | 4878-2N3904CT-ND | $0.10 | $0.30
1 | OLED-Header | P | Adam Tech | PH1-04-UA | CONN HEADER VERT 4POS 2.54MM | Digi-Key | 2057-PH1-04-UA-ND | $0.10 | $0.10
1 | OLED1 | NP | iPistBit | SSD1306 | 5 Pcs 0.96 Inch OLED Display Module, 128x64 Pixel I2C SSD1306 Luminous OLED Screen Board Compatible with Arduino Raspberry Pi ESP32(Blue and Yellow) | Amazon | Amazon | $11.99 | $11.99
2 | L1,L2 | P | Bourns Inc. | RL110-330K-RC | 33 µH Unshielded Drum Core, Wirewound Inductor 2.9 A 55mOhm Max Radial, Vertical Cylinder, 4 Leads (Open) | Digi-Key | RL110-330K-RC-ND | $1.70 | $3.40
1 | J3 | P | Phoenix Contact | 1190297 | 2 Position Wire to Board Terminal Block Horizontal with Board 0.197" (5.00mm) Through Hole | Digi-Key | 277-1190297-ND | $1.41 | $1.41
1 | J1 | P | Würth Elektronik | 694106301002 | Power Barrel Connector Jack 2.10mm ID (0.083"), 5.50mm OD (0.217") Through Hole, Right Angle | Digi-Key | 732-5930-ND | $1.02 | $1.02
8 | GND1,SPK+,SPK-,CHO-TRE,FUZ-CHO,GND,OUT_{LINE},V+ | NP | Keystone Electronics | 5021 | PC Test Point, Low Profile Phosphor Bronze Silver Plating Through Hole Mounting Type | Digi-Key | 36-5021-ND | $0.27 | $2.16
1 | D3 | P | MCIGICM | 5mm LED Light Diodes | MCIGICM 5mm LED Light Diodes, LED Circuit Assorted Kit for Science Project Experiment | Amazon | Amazon | $0.05 | $0.05
1 | D2 | P | onsemi | 1N4744A | Zener Diode 15 V 1 W ±5% Through Hole DO-41 | Digi-Key | 1N4744A-ND | $0.24 | $0.24
1 | D1 | P | STMicroelectronics | 1N5817 | Diode 20 V 1A Through Hole DO-41 | Digi-Key | 497-4547-1-ND | $0.35 | $0.35
 |  |  |  |  |  |  |  | TOTAL: | $65.26
VERSION INFO
Rev | Date | Notes
1 | 2024-11-13 | Initial Compiliation of the BOM
2 | 2024-11-13 | Modifications based on QA

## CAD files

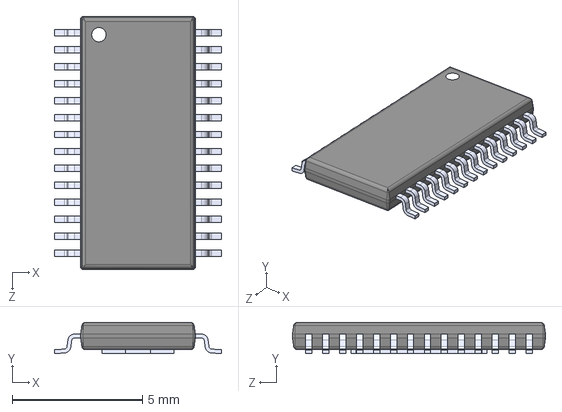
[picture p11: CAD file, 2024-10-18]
Electrical Design/PedalSynth/SymbolFootprint/TPA3136D2PWPR/TPA3136D2PWPR.step
6.40 x 1.20 x 9.70 mm

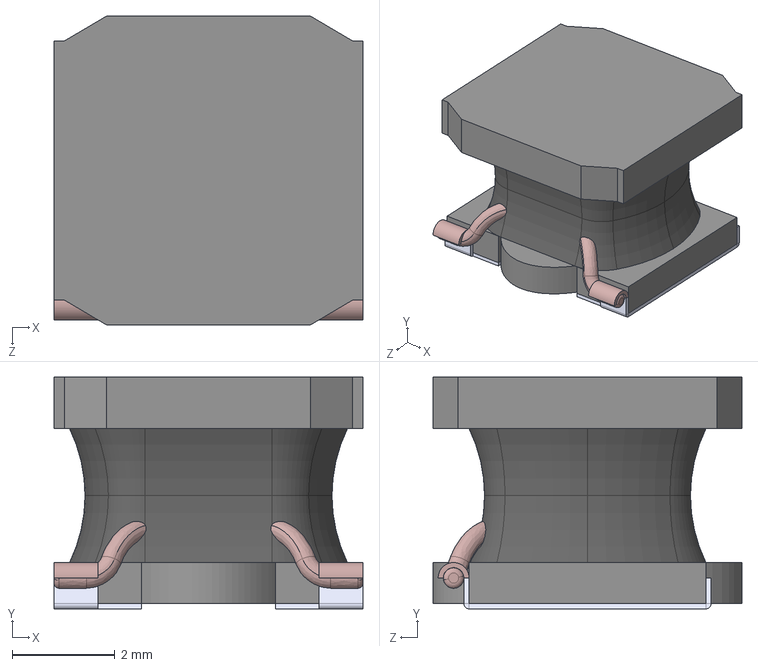
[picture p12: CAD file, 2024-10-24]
Electrical Design/PedalSynth/SymbolFootprint/VLS6045AF_330M/VLS6045AF-330M.step
6.00 x 4.50 x 6.00 mm

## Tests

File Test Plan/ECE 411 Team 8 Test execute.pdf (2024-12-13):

Team 8
ECE 411
12/5/2024
SynthBuddy Test Plan
Part 1
Unit Test
- Test power supply to verify it provides both -9V, 9V, and 4.5V (probe (VGND, V9, V4.5, pin 5 of U2 for -9V or negative leg of C22)
- Test 5V regulator circuit to ensure 5V output to OLED (probe OLED1 pin 2)
- Test buttons to verify a signal is sent to ESP32 (check serial output)
- Test ESP32 to verify a data signal is sent to OLED display (probe at pin header)
- Test ESP32 to verify PWM Signal is sent to Fuzz (probe TP GENOUT1)
- Test to see signal goes from Fuzz to Chorus (probe TP FUZ-CHO1)
- Test to see signal goes from chorus to Tremolo (probe TP CHO-TRE1)
- Test to see signal goes from Tremolo to amplifier (probe TP LINEOUT1)
- Test to see signal goes from amplifier to output speaker (probe TP SPK+/SPK-)
- Test output signal after amplifier to see if the amplitude is in an acceptable range Verification Test
- Input buttons select a predesignated signal frequency
- PWM synth signal dry
- Does the output signal produce sound
- Is the pitch the note specified
- Does the frequency change when input changes
- Is the dry signal a sin wave clear of any distortion or other artefacts
- Signal with Fuzz
- Does the signal route through the fuzz effect and produce output
- Does the bypass potentiometer completely cut off the effect without adding distortion
- Does setting the potentiometer to different values produce unique sounds

- Signal with Chorus
- Does the signal route through the chorus effect and produce output
- Is the chorus able to be bypassed with bypass switch
- Does the chorus need additional hardware added to the test point to produce output
- Signal with Tremolo (“Tre-Mellow” ™)
- Does the signal route through the tremolo effect and produce output
- Does the bypass potentiometer completely cut off the effect
- Is the rate potentiometer able to affect the rate of cut off of the signal with the tremolo
- Signal with all effects
- Text is written out to the OLED display
- Buttons activate different frequency output from the ESP32 function generator
Validation Tests
- Speaker outputs an amplified sound
- Effect Potentiometers/buttons impact the sound/quality of sound generated.
- OLED displays selected signal frequency based on selected input button
- Selecting an input button generates a sound from the speaker.

Test Case
Test Author: Team 8
Test Case Name: | PWM Signal Generation Test | Test ID #: | 1
Description: | Checks the response of the esp32 to the input buttons as well as testing the output of the signal for integrity and proper tuning | Type: | □ white box ☑ black box □ ________

Tester Information
| Name of Tester: | Team 8 The Voltage Vanguard | Date: | 12/04/24
| HW/SW Version: | Synth Buddy r1.6 | Time: | 12:00 pm
| Setup: | The circuit should be powered attached to a wall outlet, the output should be attached to a speaker and monitored by an oscilloscope, a guitar tuner app can be placed near the speaker to determine the note being played, buttons connected to the GPIO pins will float freely for now,
S T E P | Action | Expected Result | P A S S | F A I L | N / A | Comments
1 | Connect synth buddy to power | Relevant LEDs, OLED, and microcontroller are all powered on | X | | | All components receiving power, and acting as intended, rate and waveform LED show as planned
2 | Connect synth buddy to speaker | No connection issues, dry signal able to be heard. | X | | | Amp works well, input through aux outputs with no issues
3 | Connect synth buddy to oscilloscope | Sine wave output from dry signal | X | | | Scope reads almost exactly the same as input sine wave from ipad
4 | Press each input button | Guitar tuner app will indicate correct frequency (note) being pressed | X | | | All notes exactly where intended, some minor tweaks needed to be made, presumably an issue with the original PWM library

5
| Overall test result: | | | | | Amp and ESP32 work flawlessly

Matrix Test (for varying parameters)

Test Author: Team 8

Test Case Name: | Tremolo Integration Test | Test ID #: | 2
Description: | Checks that the tremolo effect causes a varying scale of change on the generated PWM signal based on the tuning of the potentiometer. | Type: | ☑ white box □ black box □ _____________

Tester Information

| Name of Tester: | Team 8 | Date: | 12/04/2024
| HW/SW Version: | Synth Buddy r1.6 | Time: | 12:00 pm
| Setup: | With the generated PWM signal turned on, the tremolo effect will be tested with the rate potentiometer starting at 0% (off) as a bypass, slowly incrementing to 100%. The tremolo effect will be tested at each point of input testing.
T E S T | INPUTS | EXPECTED OUTPUTS | P A S S | F A I L | N / A | Comments
1 | Rate Potentiometer turned/set to 0. | Output should be plain and steady sine wave, signal is unaffected | X | | | Some minor artifacts from the effect remain but the signal is mostly dry
2 | Rate Potentiometer turned/set to 20%. | The tremolo effect will be subtly applied to the signal as it should oscillate at ±20% of its original amplitude. | X | | | A very slow pulsing signal achieved, as intended

3 | Rate Potentiometer turned/set to 40% | The tremolo effect will be more noticeable as the signal should oscillate at ±40% of its original amplitude. | X | Seemed to accelerate rather quickly at this point compared to the 20% but still working well
4 | Rate Potentiometer turned/set to 60% | The tremolo effect will cause noticeable volume changes as the signal should oscillate at ±60% of its original amplitude. | X | Picked up some more speed, led still in sync, sound is clear
5 | Rate Potentiometer turned/set to 80% | The tremolo effect causes the sound to wildly vary with moments of high highs and near silence as the signal should oscillate at ±80% of its original amplitude | X | Quick stutter, almost unnoticeable at this speed but affects the sound in an interesting way
6 | Rate Potentiometer turned/set to 100% | Tremolo rate should be at its fastest setting, the signal should oscillate at ±100% of its original amplitude | ? | This one is a bit unclear as it oscillates so quickly that it almost sounds like distortion but seems to be working as intended
| Overall test result: | | X | Very few issues after assembly, most aspects worked on initial effort, some minor tweaks were needed on a few values

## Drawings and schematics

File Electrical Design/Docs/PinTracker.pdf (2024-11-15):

SynthBuddy Pin Tracker | | IO (Input/Output)

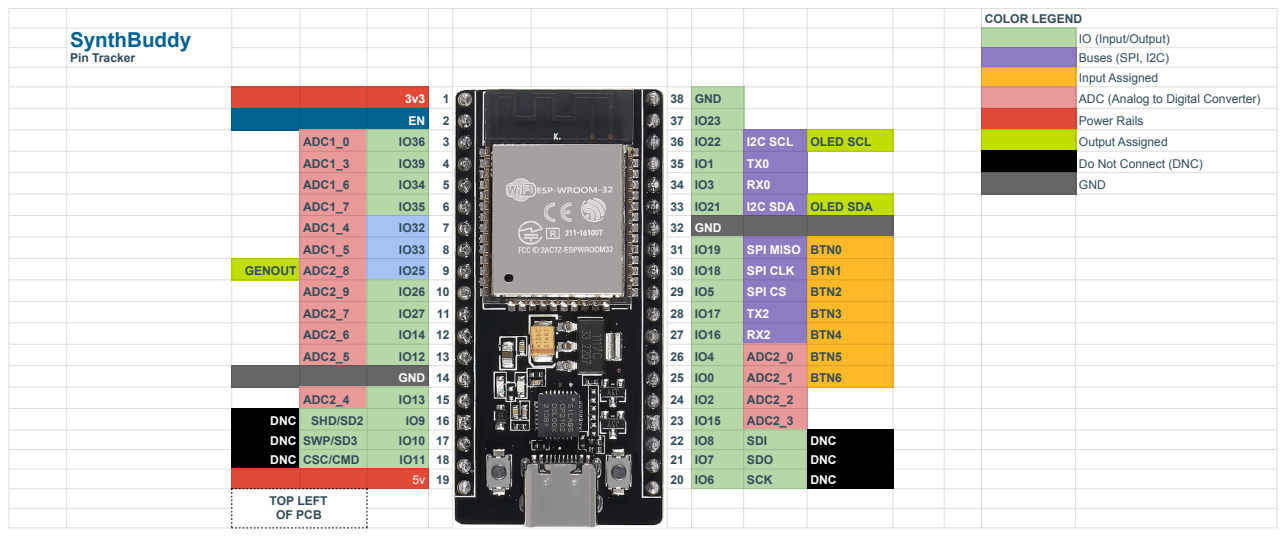
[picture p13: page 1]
COLOR LEGEND; ADC1_0; I2C SCL; OLED SCL; Output Assigned; ADC1_7; I2C SDA; OLED SDA

Buses (SPI, I2C)
Input Assigned

3v3 | 1 38 | GND | | | ADC (Analog to Digital Converter)

EN | 2 37 | IO23 | | | Power Rails

ADC1_3 ADC1_6 ADC1_4 ADC1_5 | IO39 IO34 | 4 35 5 34 | IO1 IO3 | TX0 RX0

Do Not Connect (DNC)

GND

IO32 IO33 | 7 32 8 31 | GND

IO19 | SPI MISO | BTN0

GENOUT | ADC2_8 | IO25 | 9 30 | IO18 | SPI CLK | BTN1

ADC2_9 ADC2_7 ADC2_6 ADC2_5 | IO26 IO27 IO14 IO12 | 10 29 11 28 12 27 13 26 | IO5 IO17 IO16 IO4 | SPI CS TX2 RX2 | BTN2 BTN3 BTN4

ADC2_0 | BTN5

GND | | | 14 25 | IO0 | ADC2_1 | BTN6

ADC2_4 | IO13 | 15 24 | IO2 | ADC2_2

DNC DNC DNC | SHD/SD2 IO9 SWP/SD3 IO10 CSC/CMD IO11 | | 16 23 17 22 18 21 | IO15 IO8 IO7 | ADC2_3
SDI SDO | DNC

5v | | | 19 20 | IO6 SCK | | DNC

TOP LEFT OF PCB

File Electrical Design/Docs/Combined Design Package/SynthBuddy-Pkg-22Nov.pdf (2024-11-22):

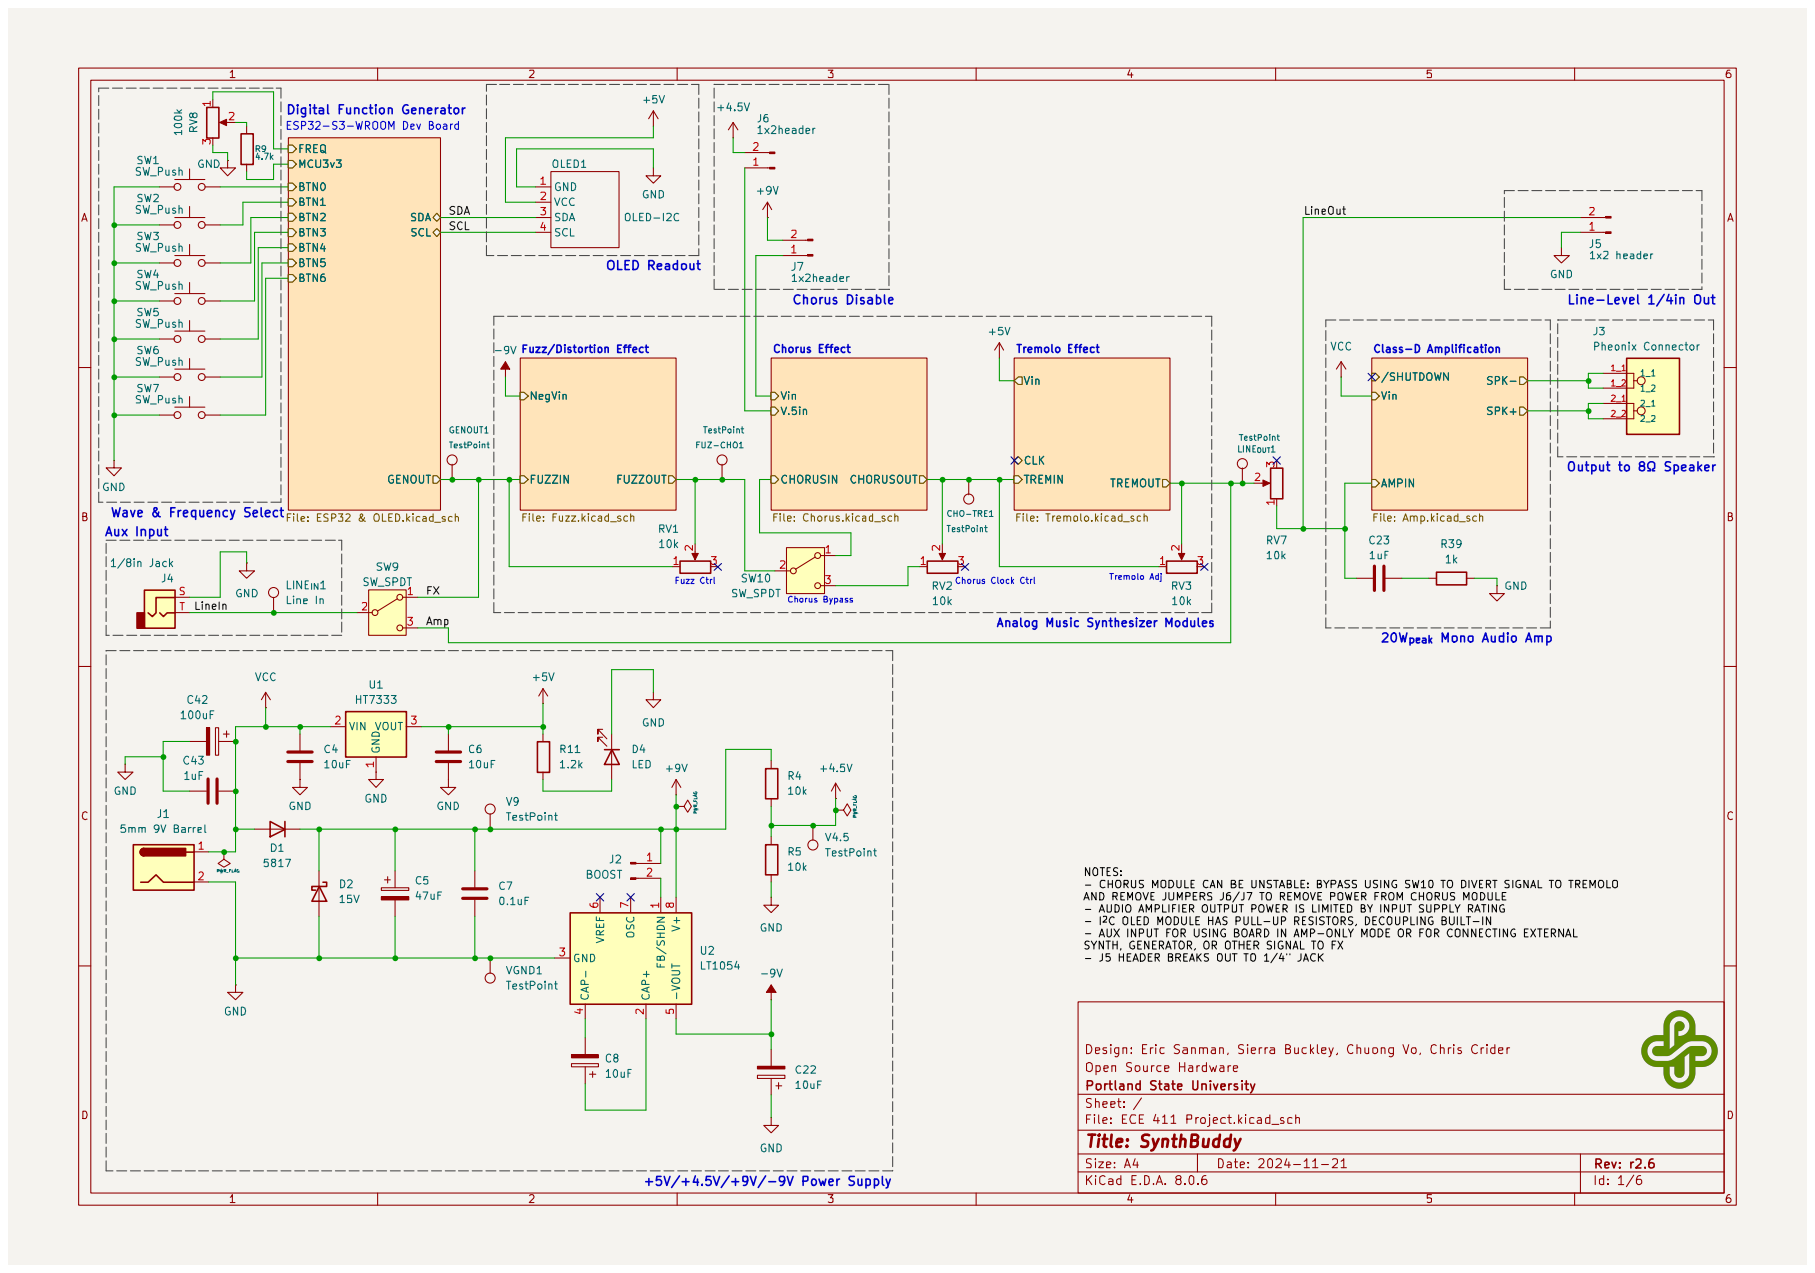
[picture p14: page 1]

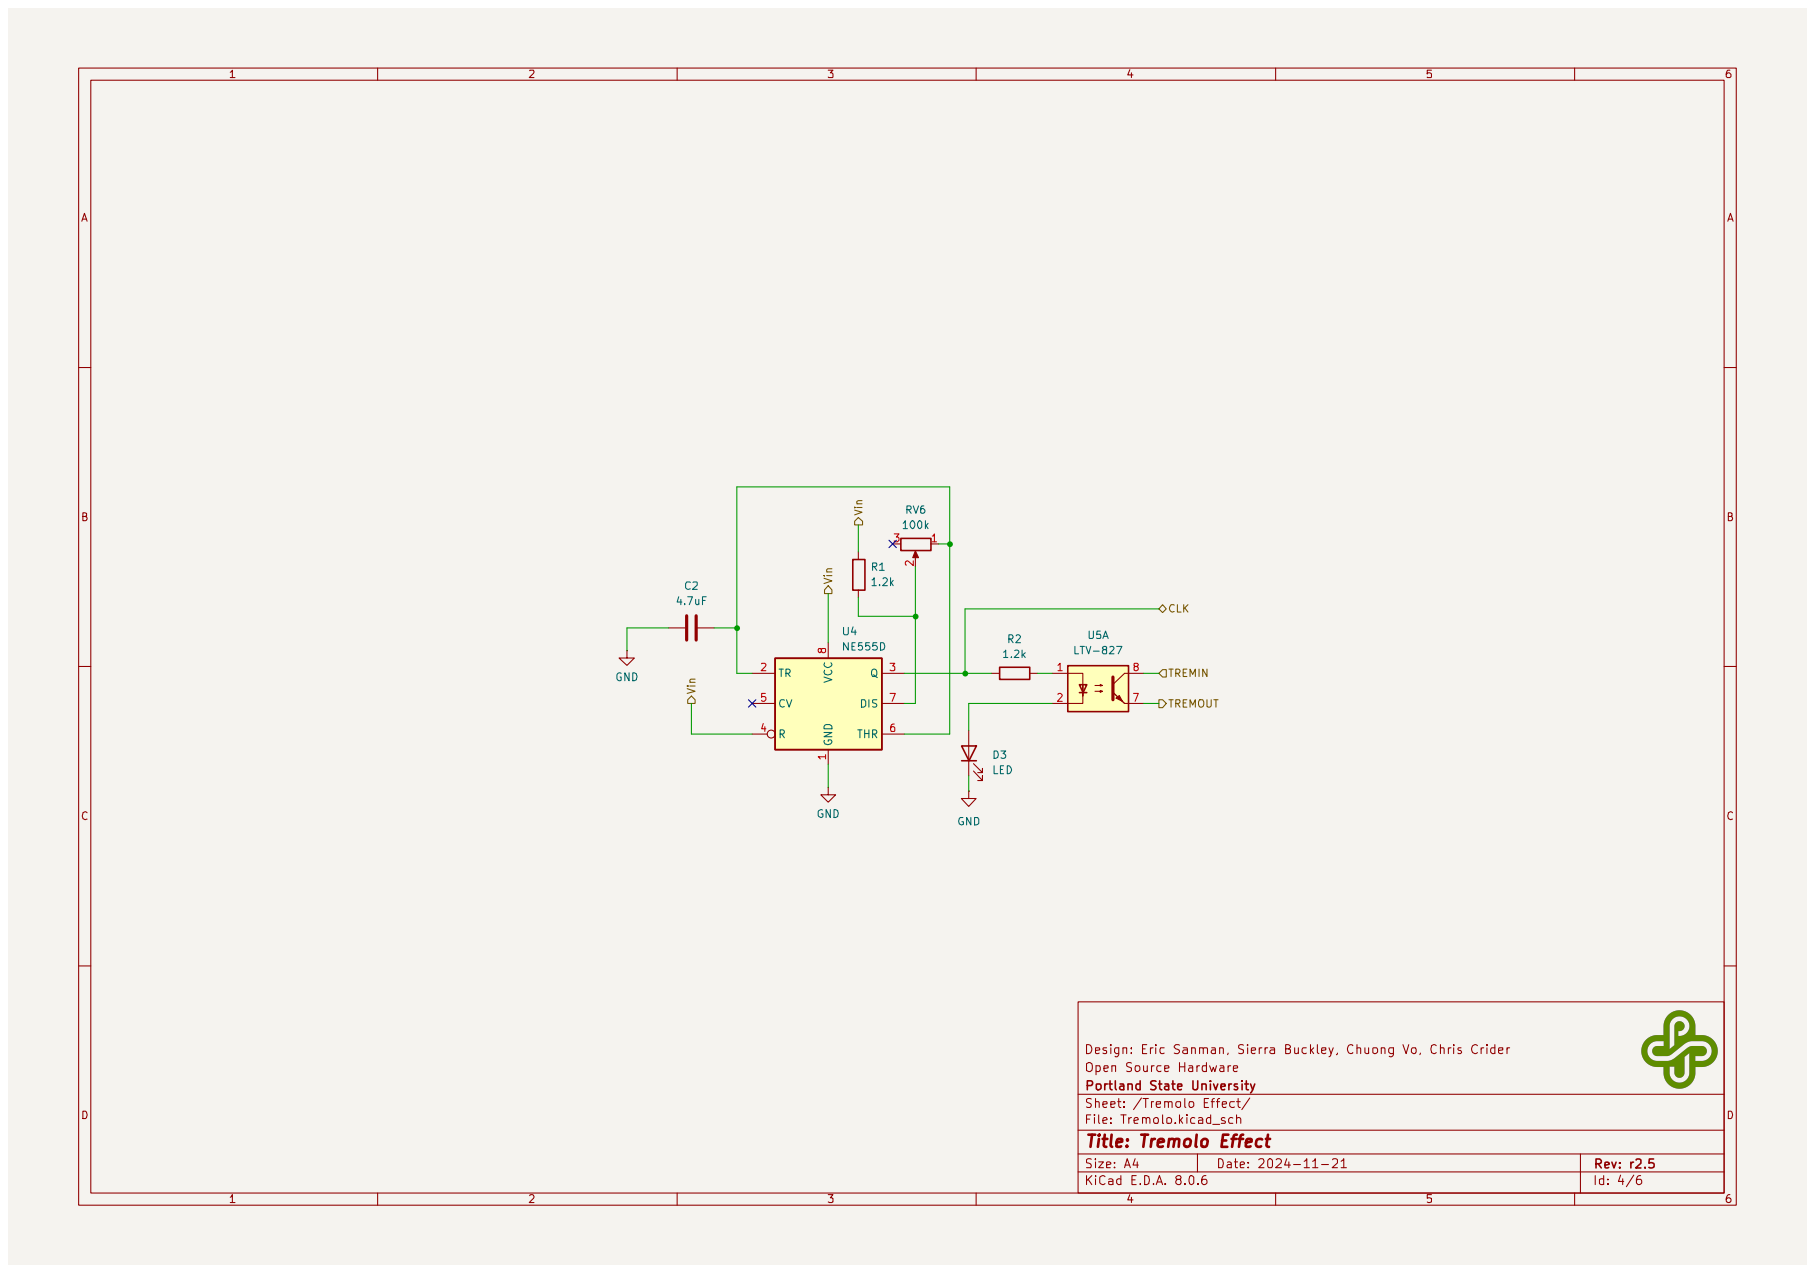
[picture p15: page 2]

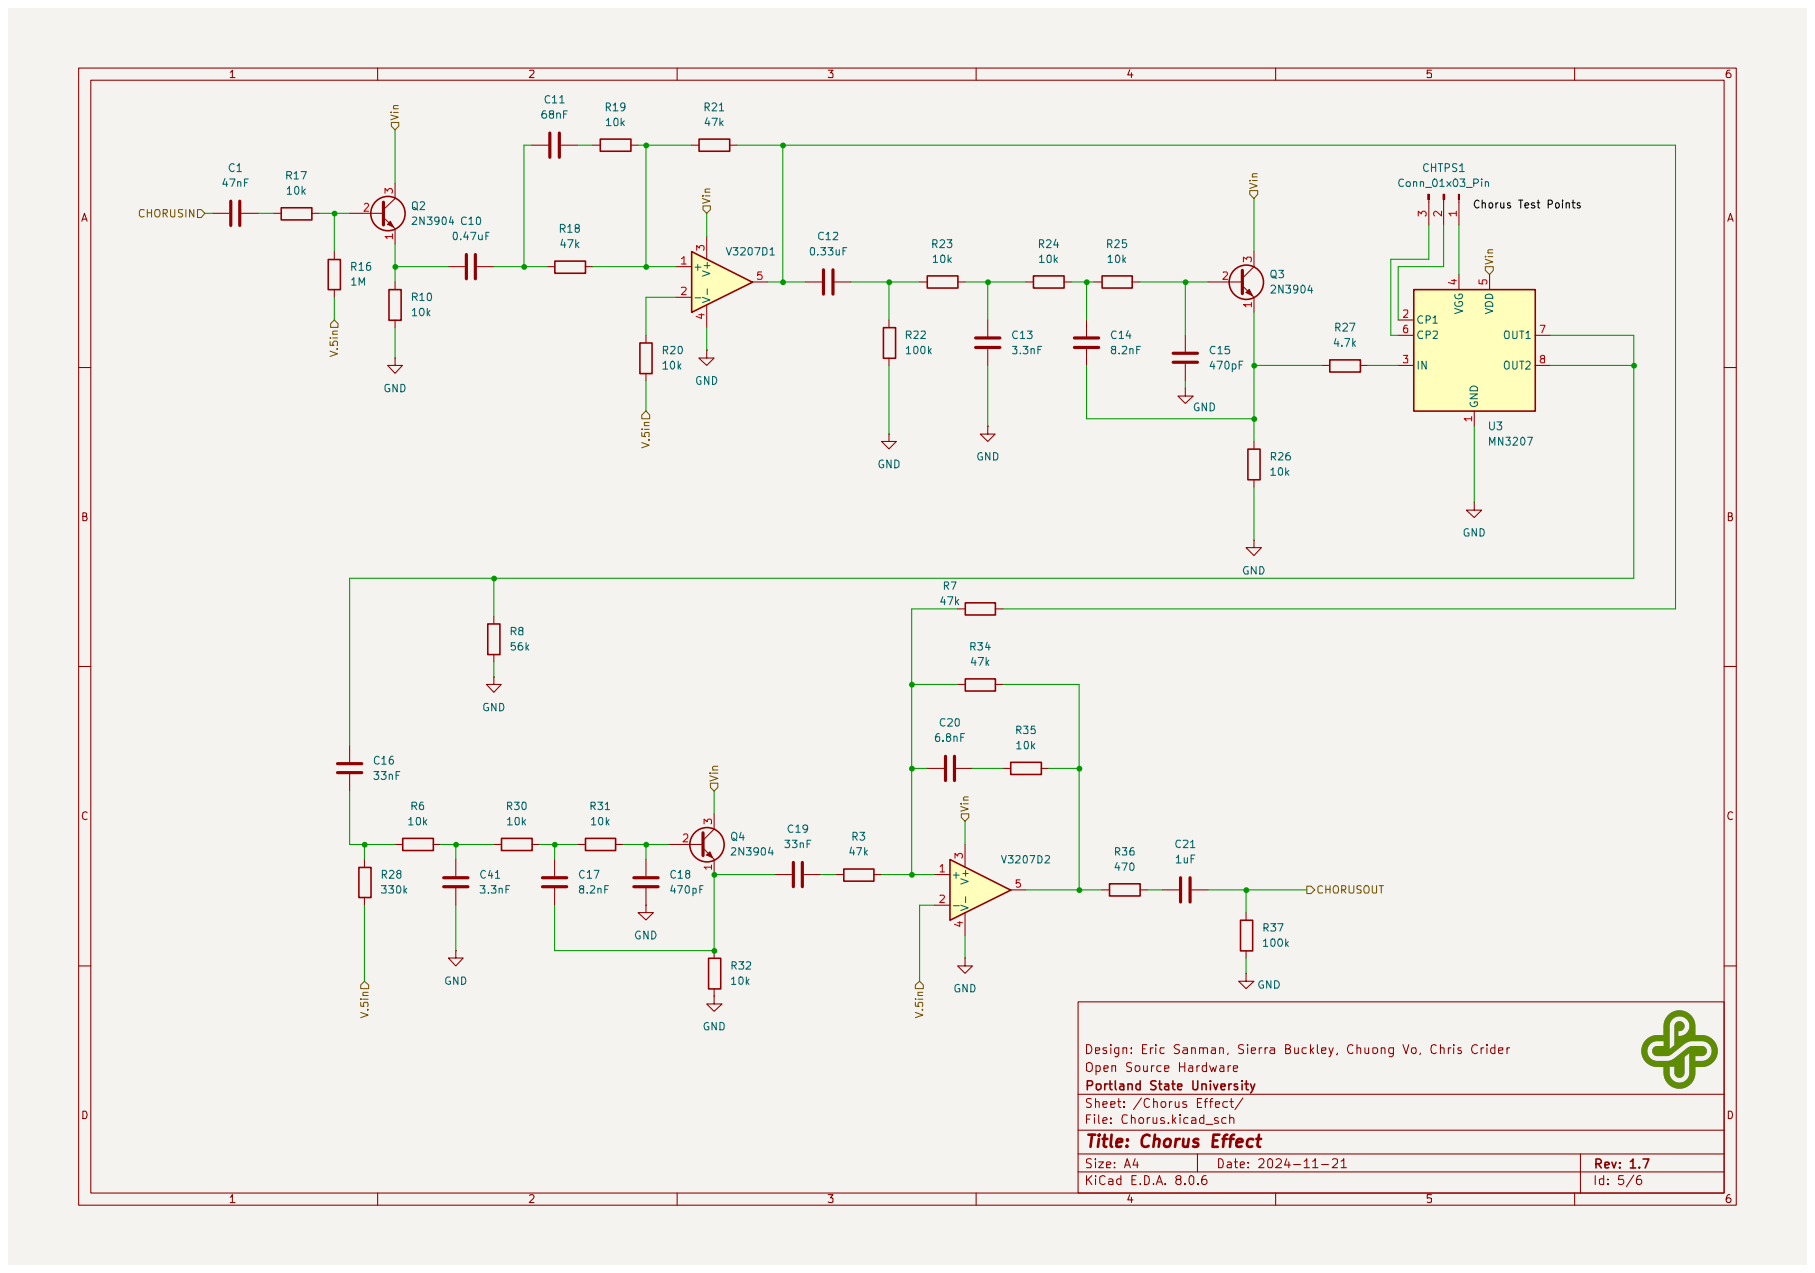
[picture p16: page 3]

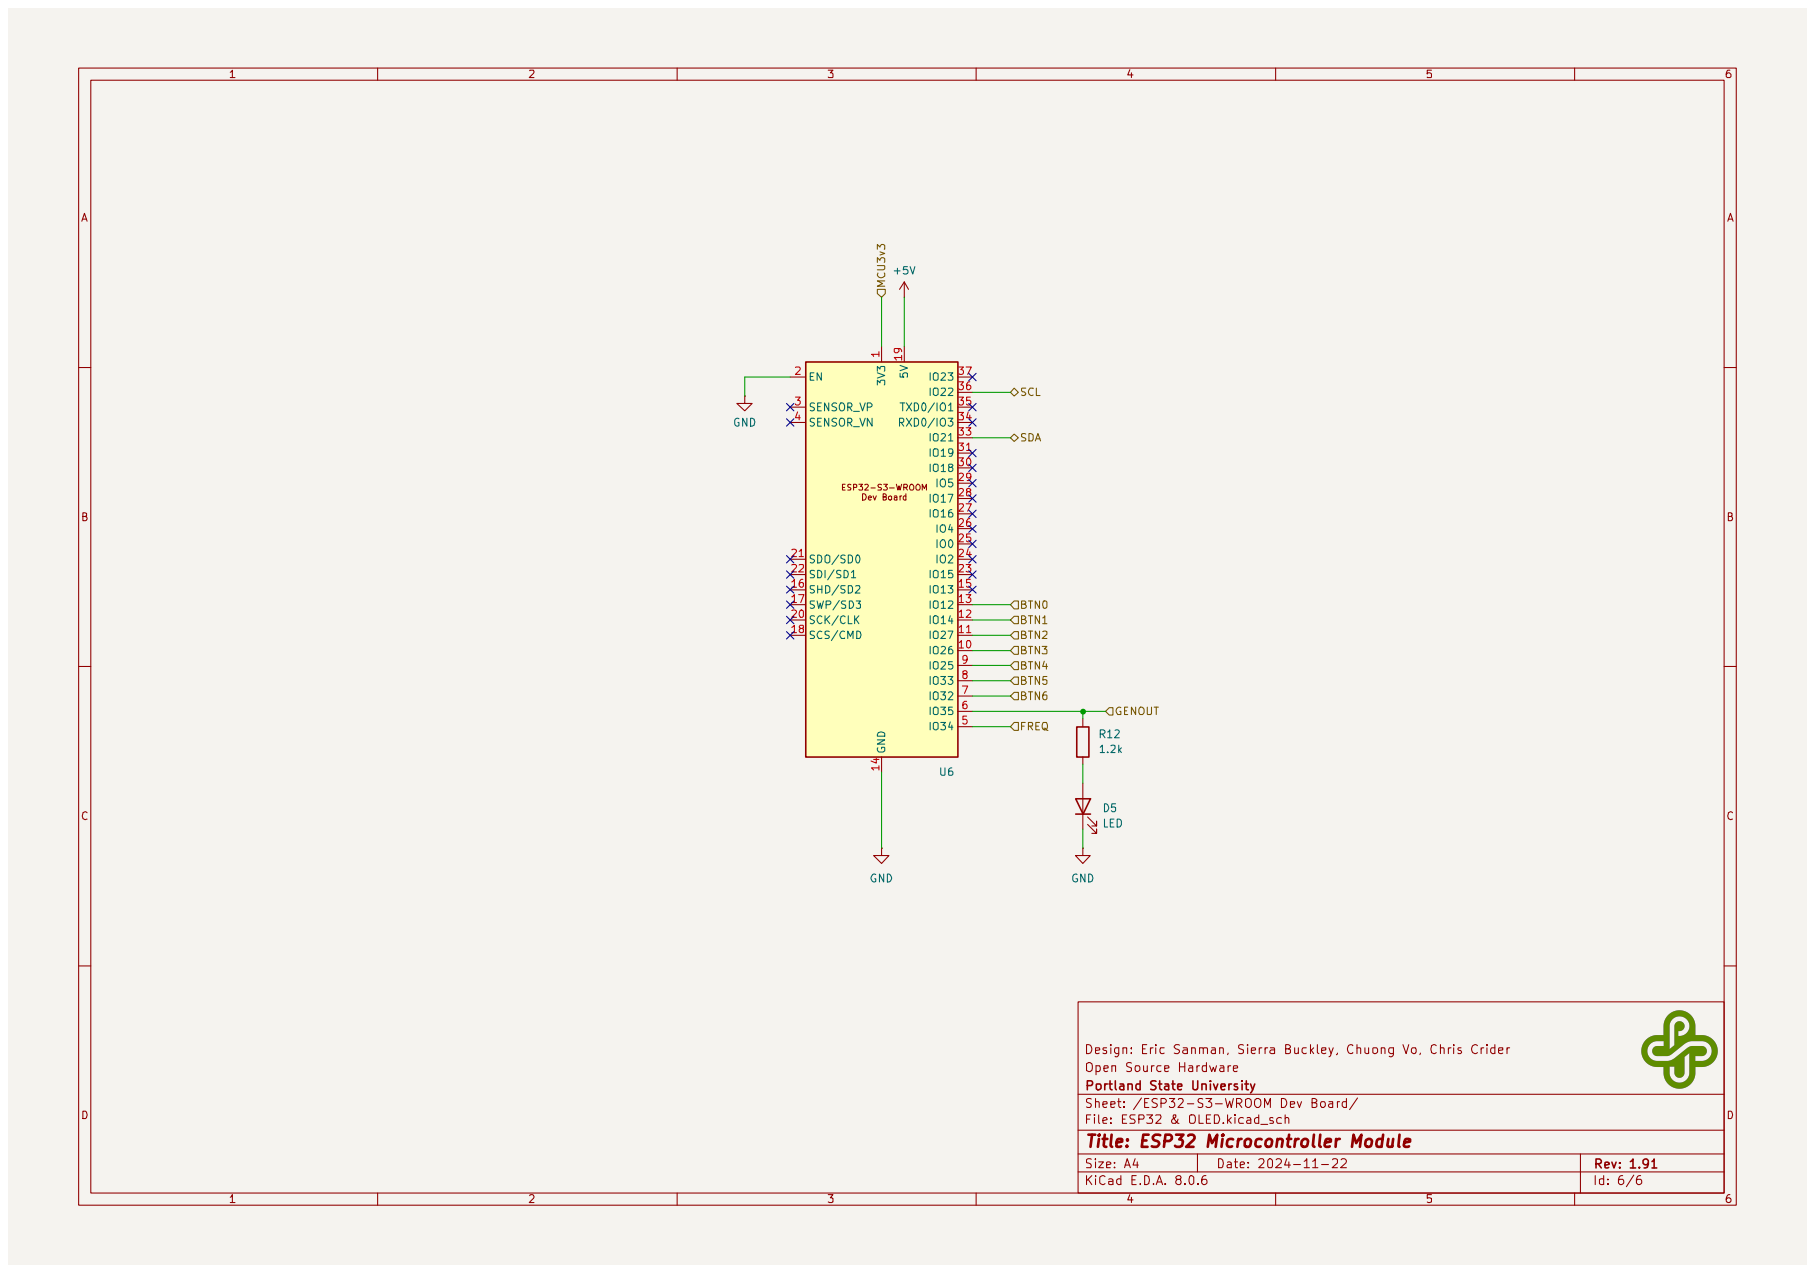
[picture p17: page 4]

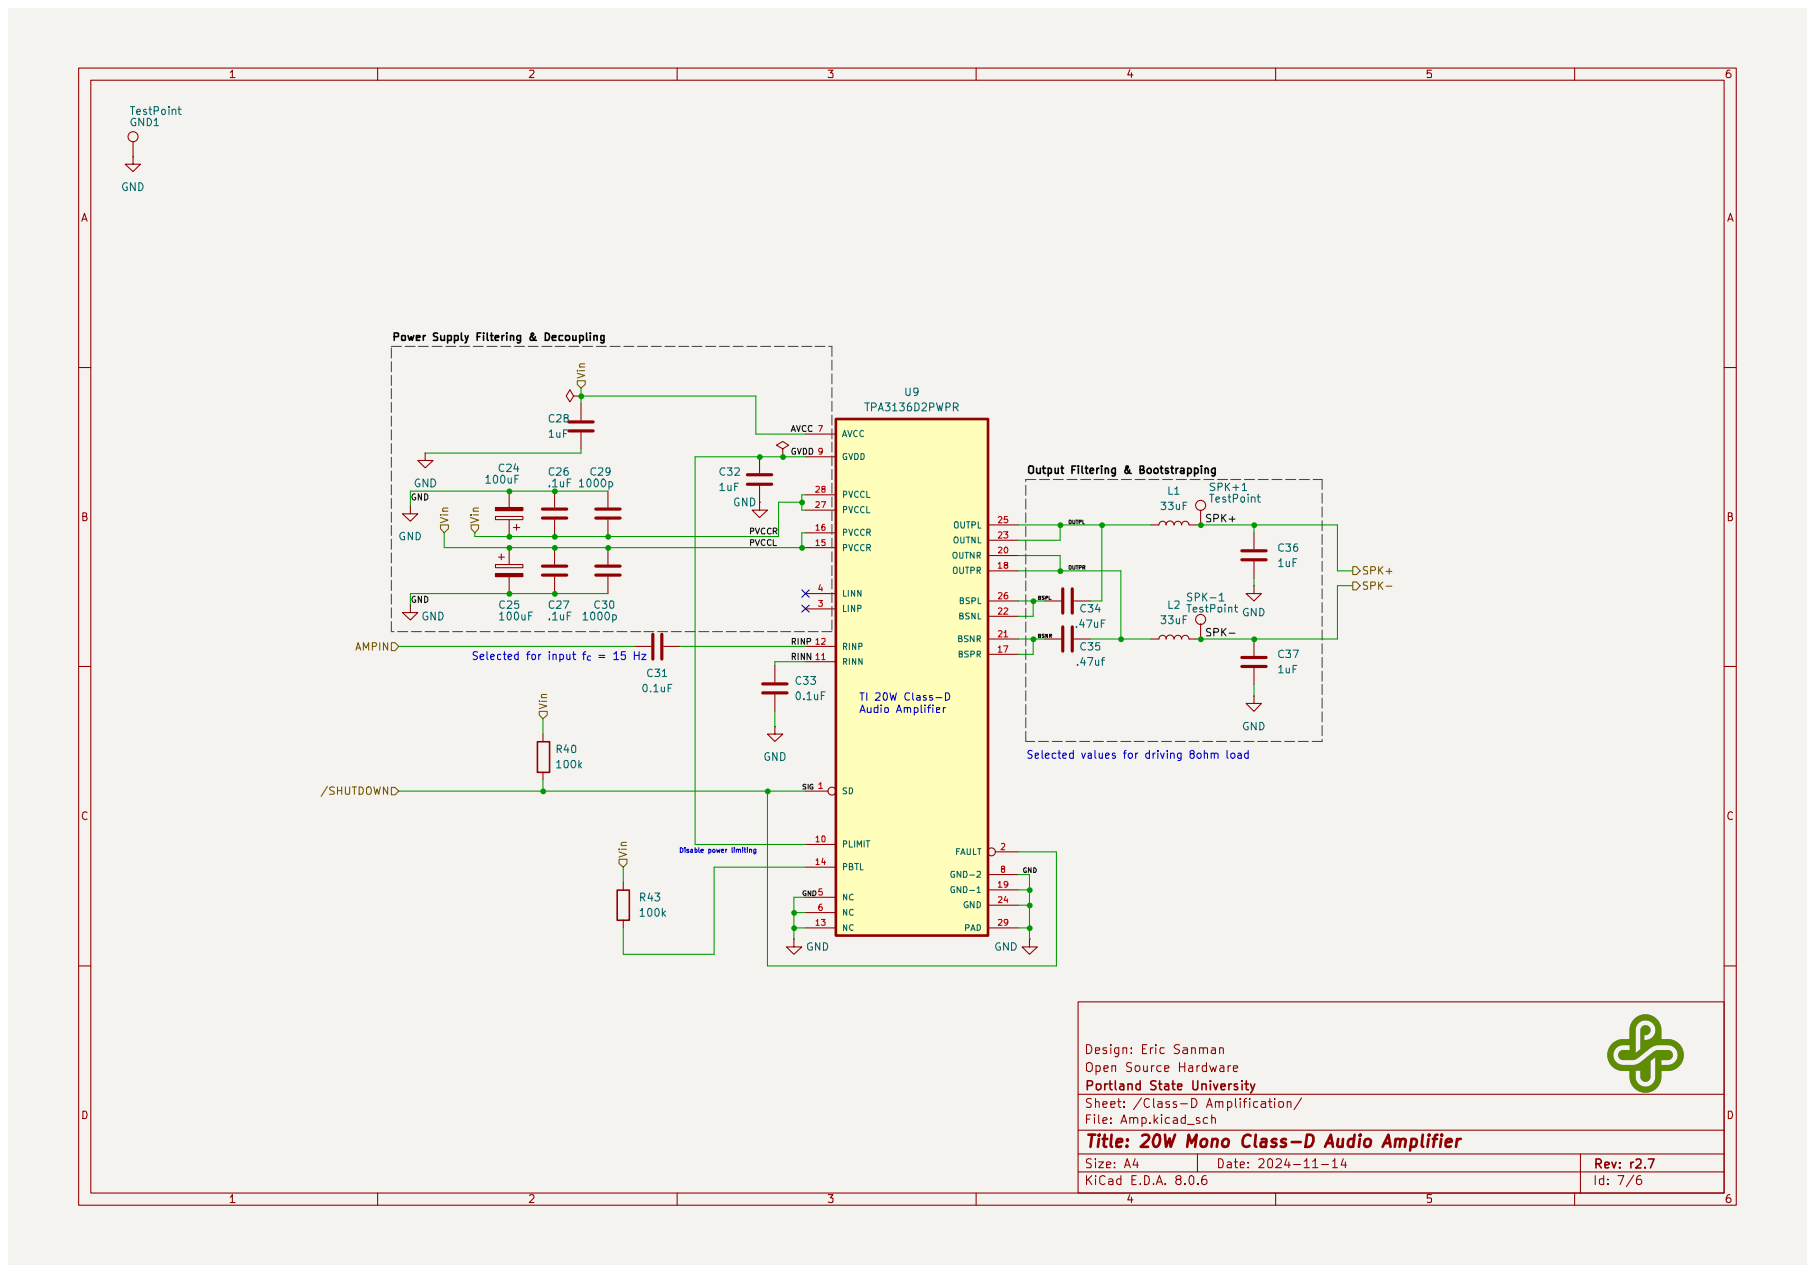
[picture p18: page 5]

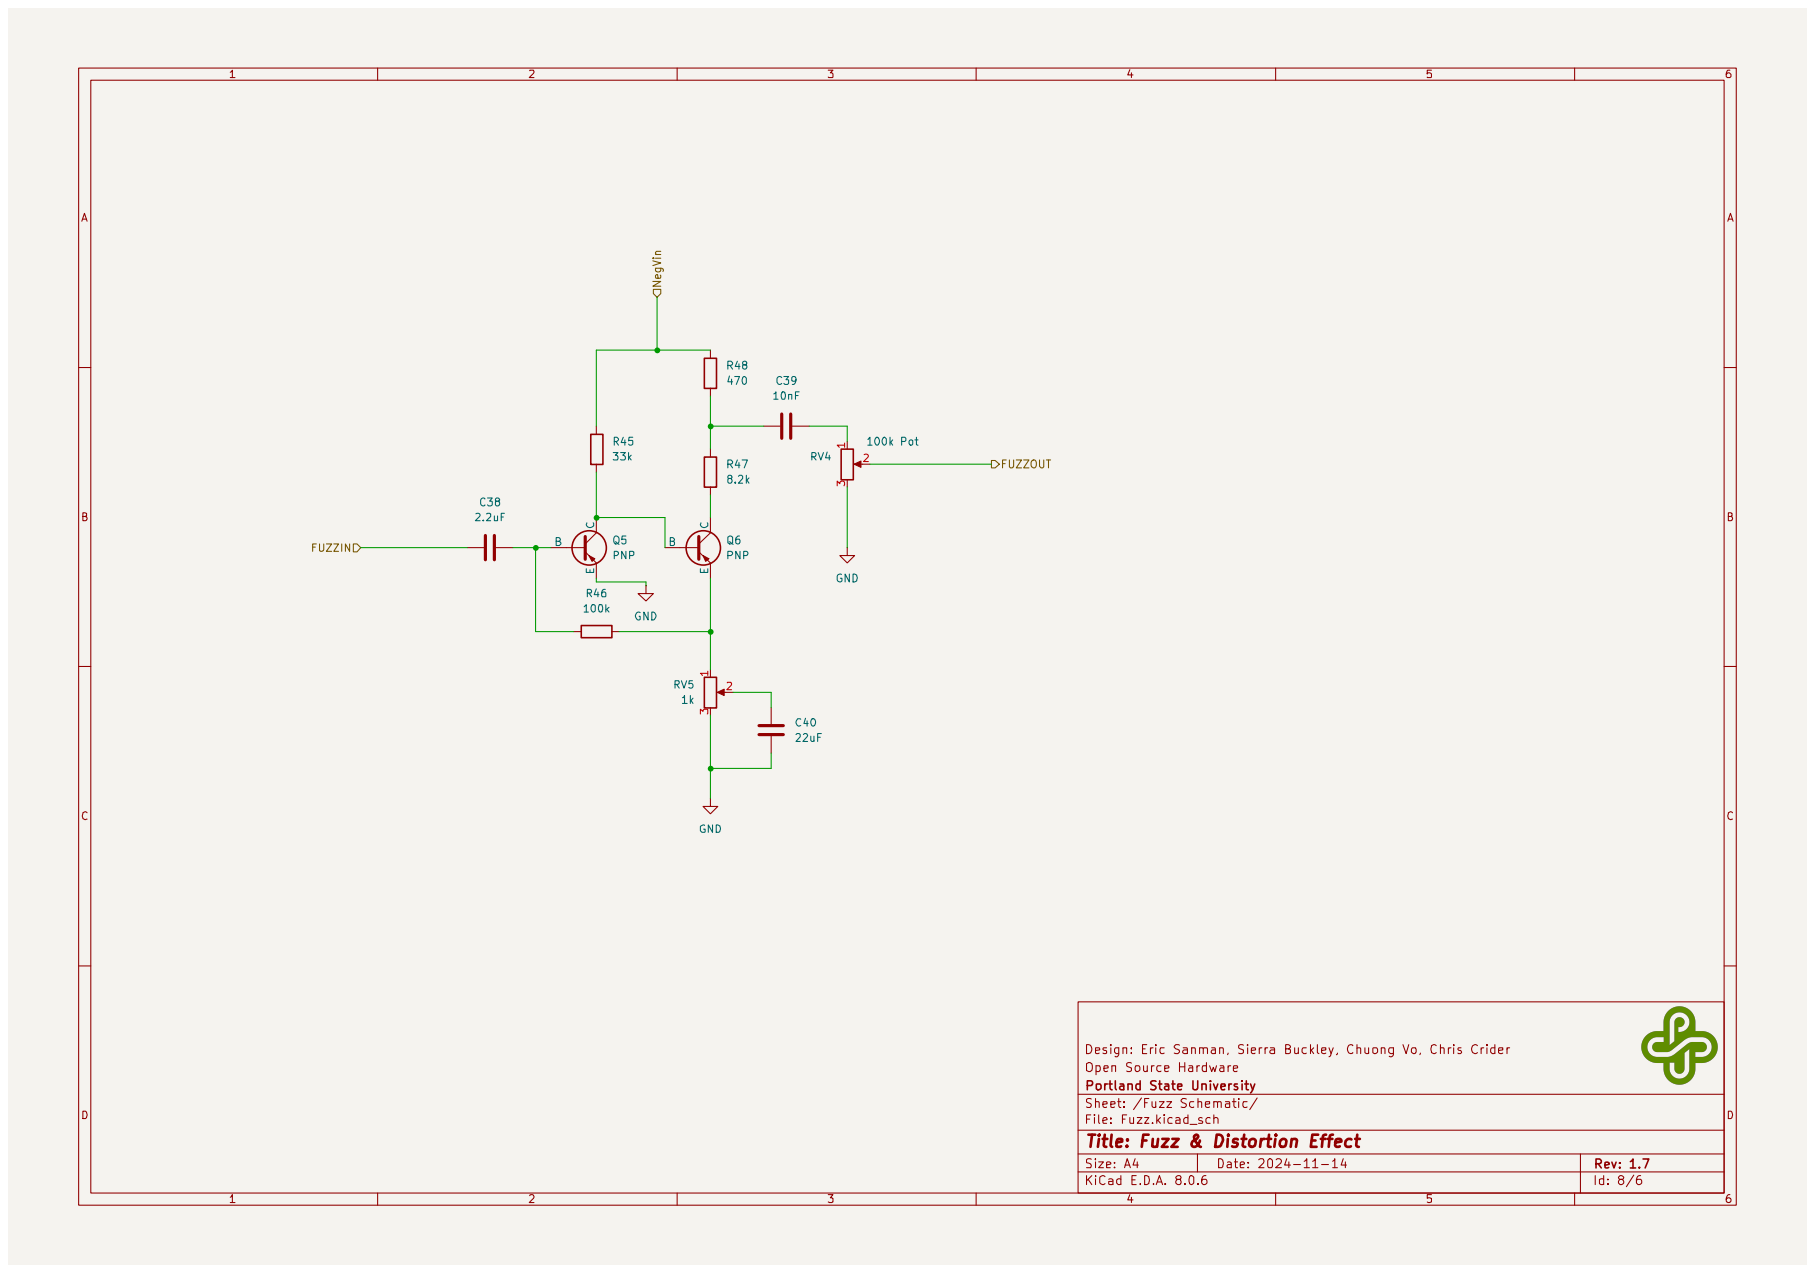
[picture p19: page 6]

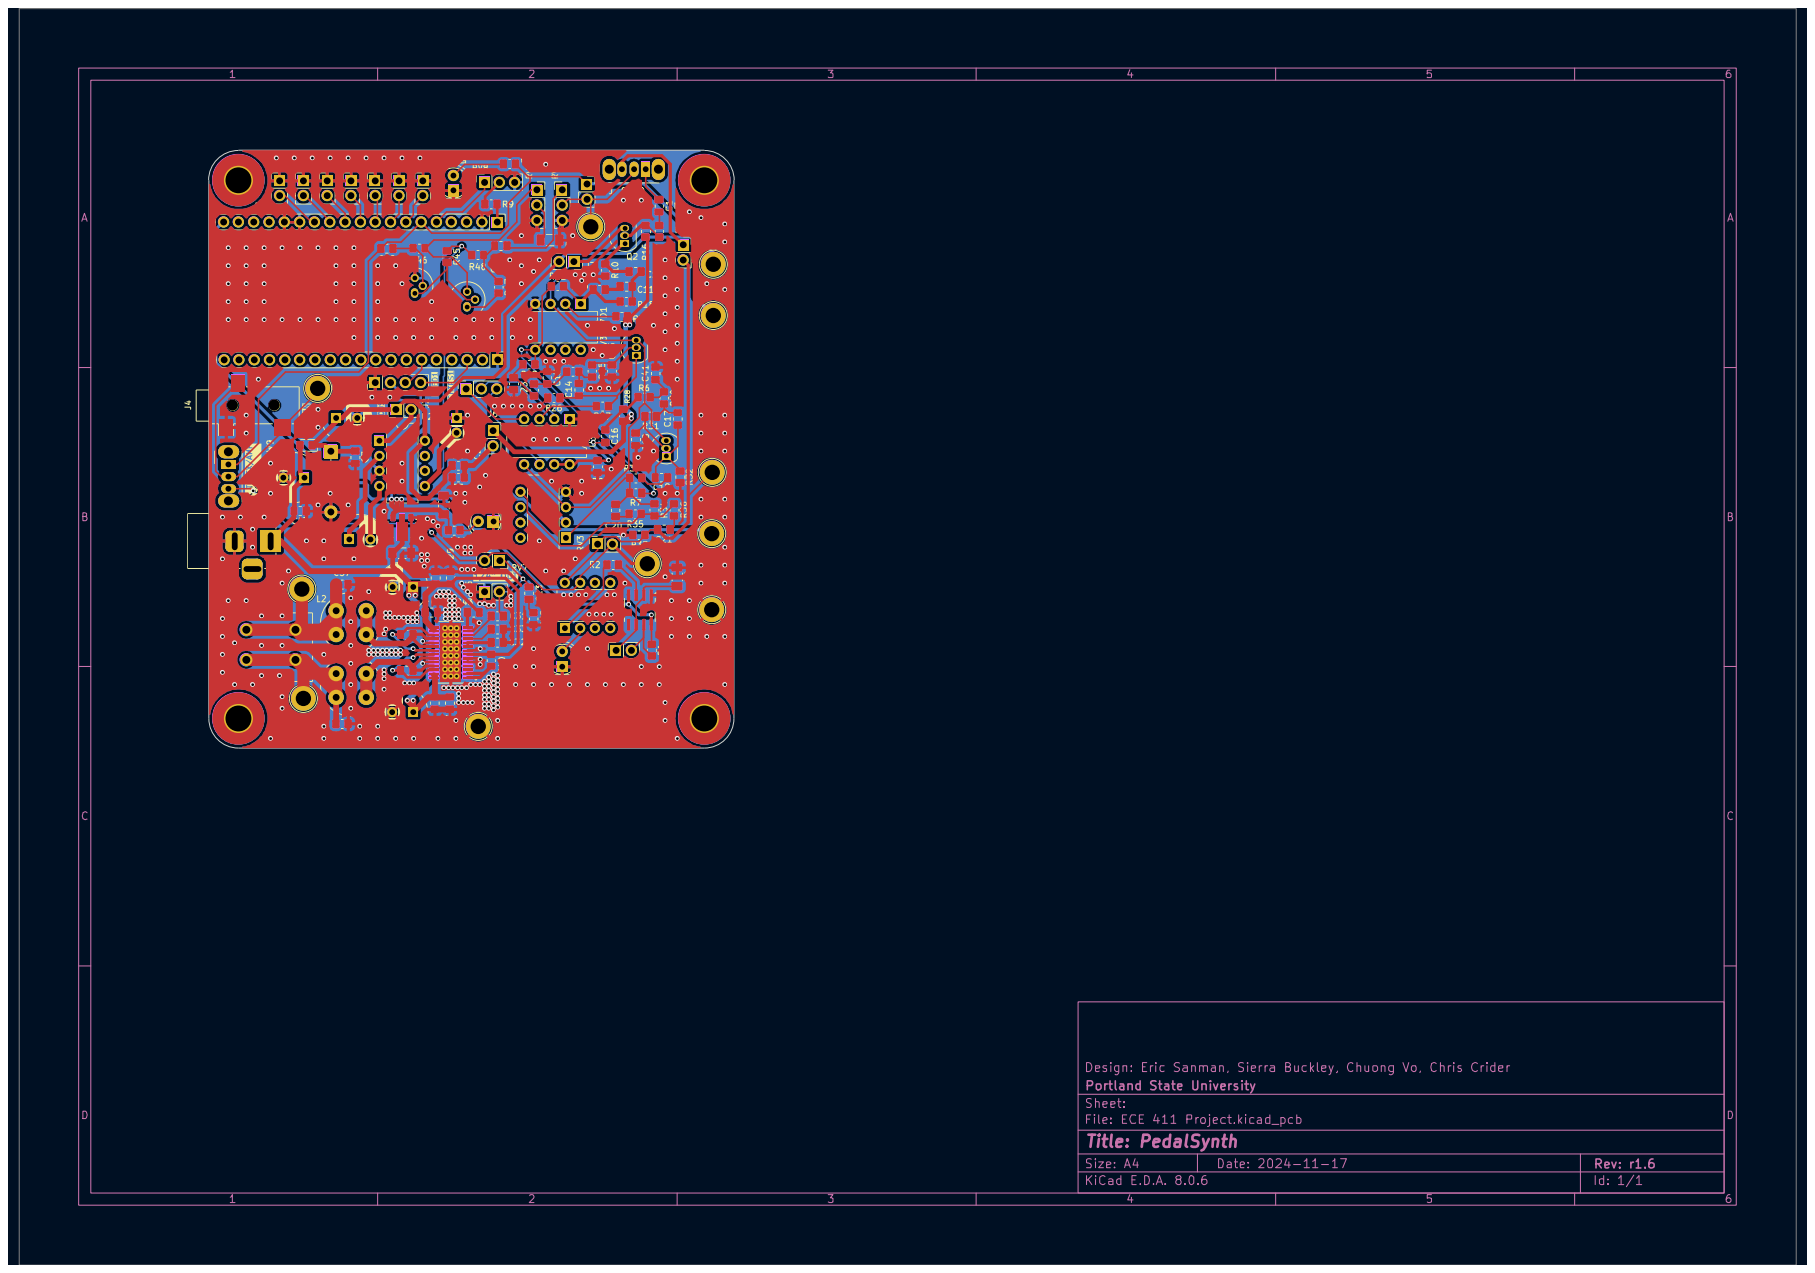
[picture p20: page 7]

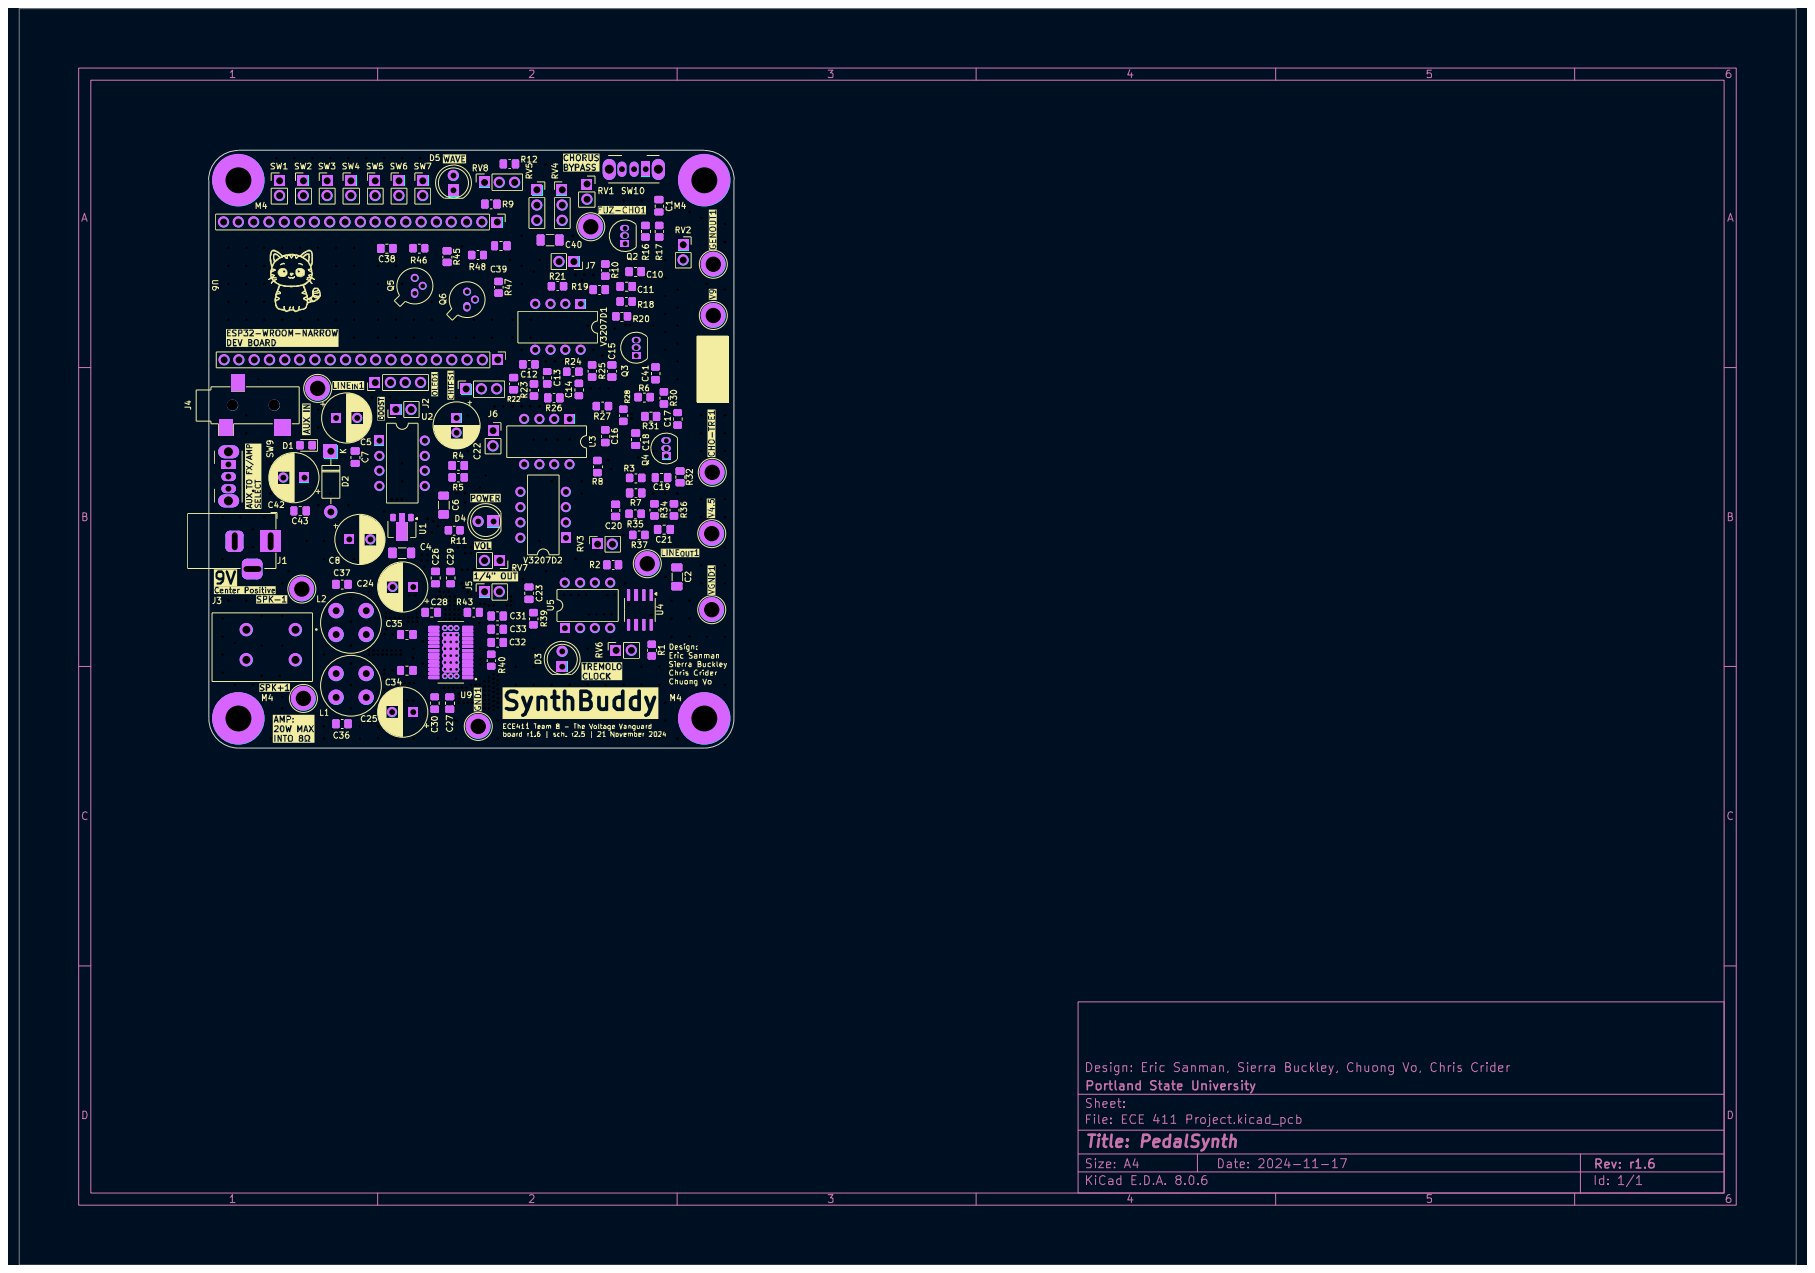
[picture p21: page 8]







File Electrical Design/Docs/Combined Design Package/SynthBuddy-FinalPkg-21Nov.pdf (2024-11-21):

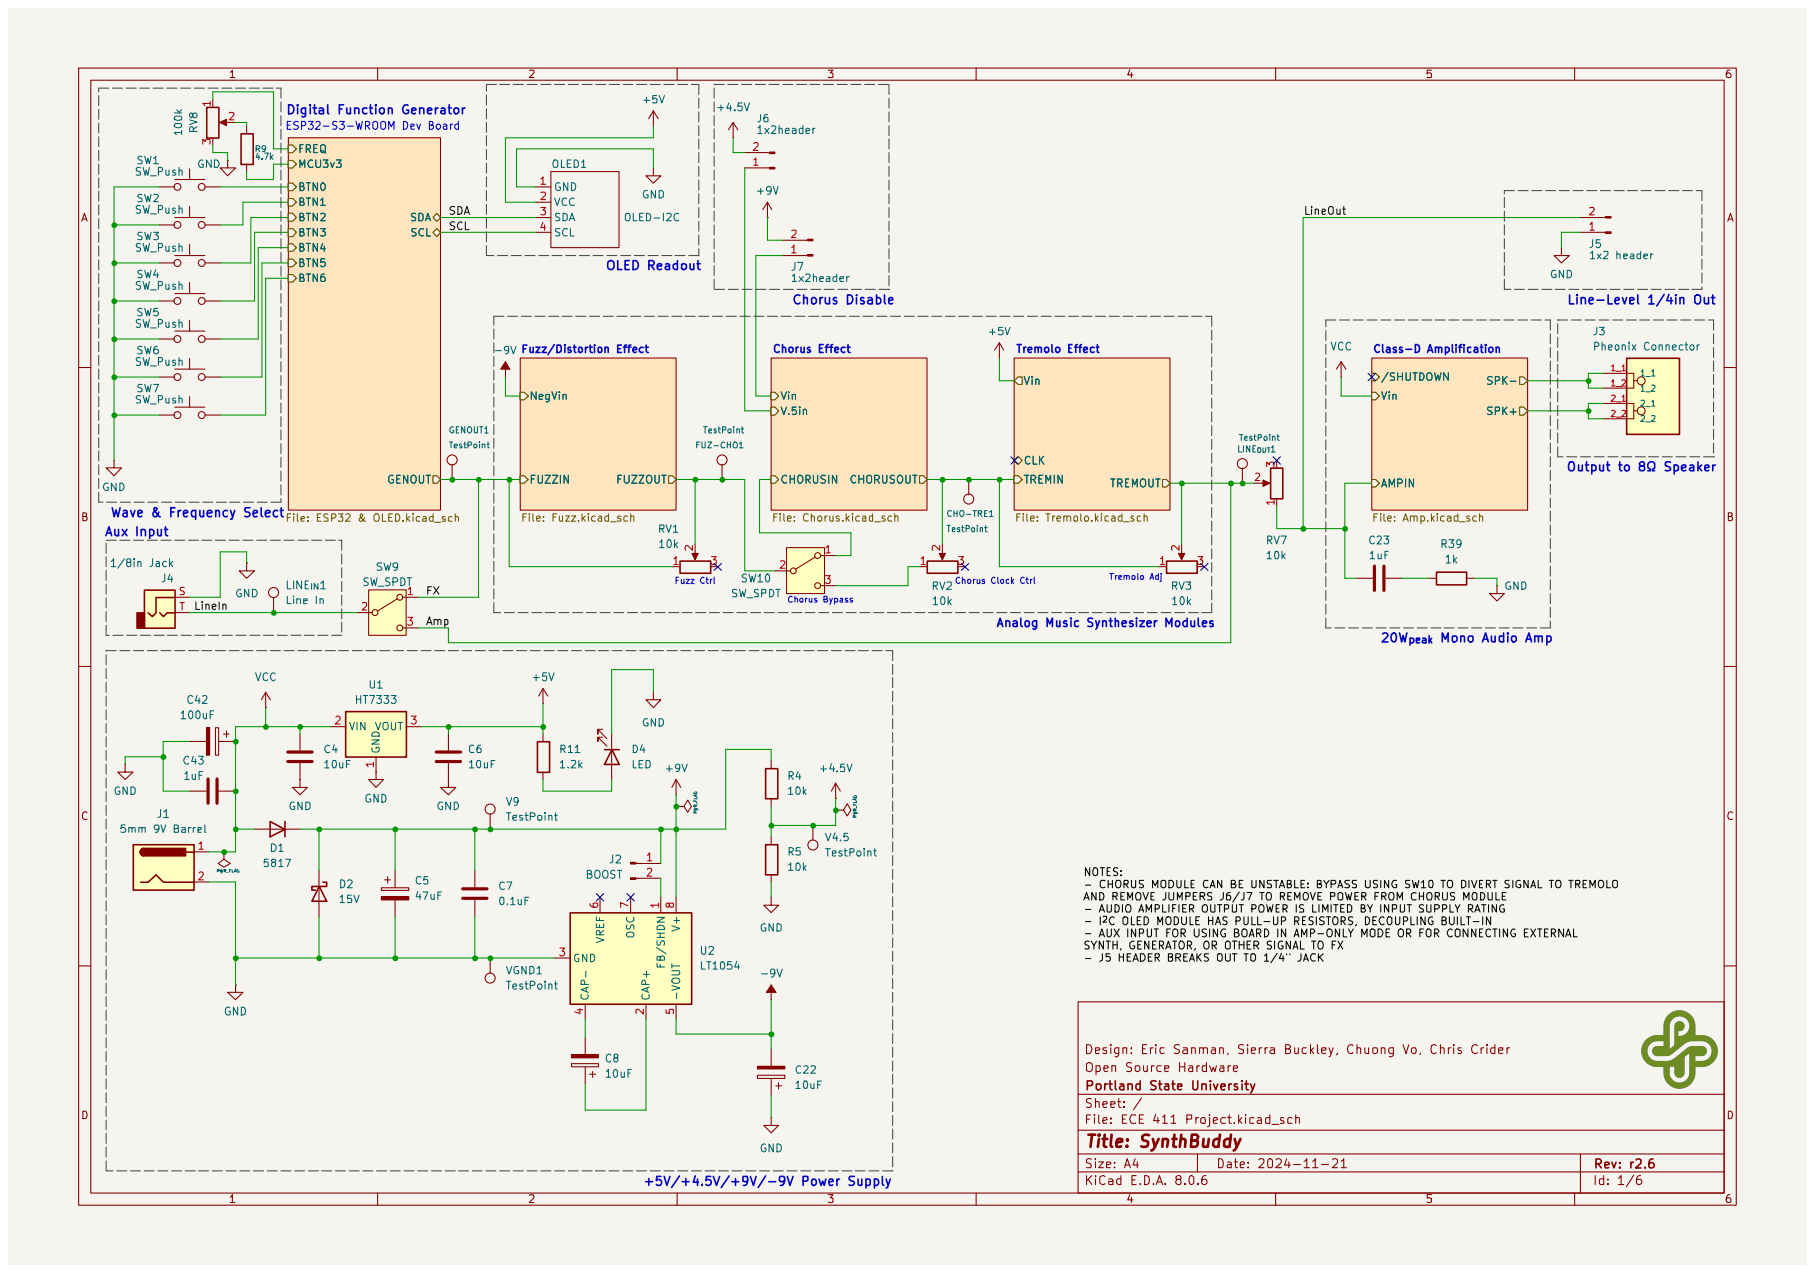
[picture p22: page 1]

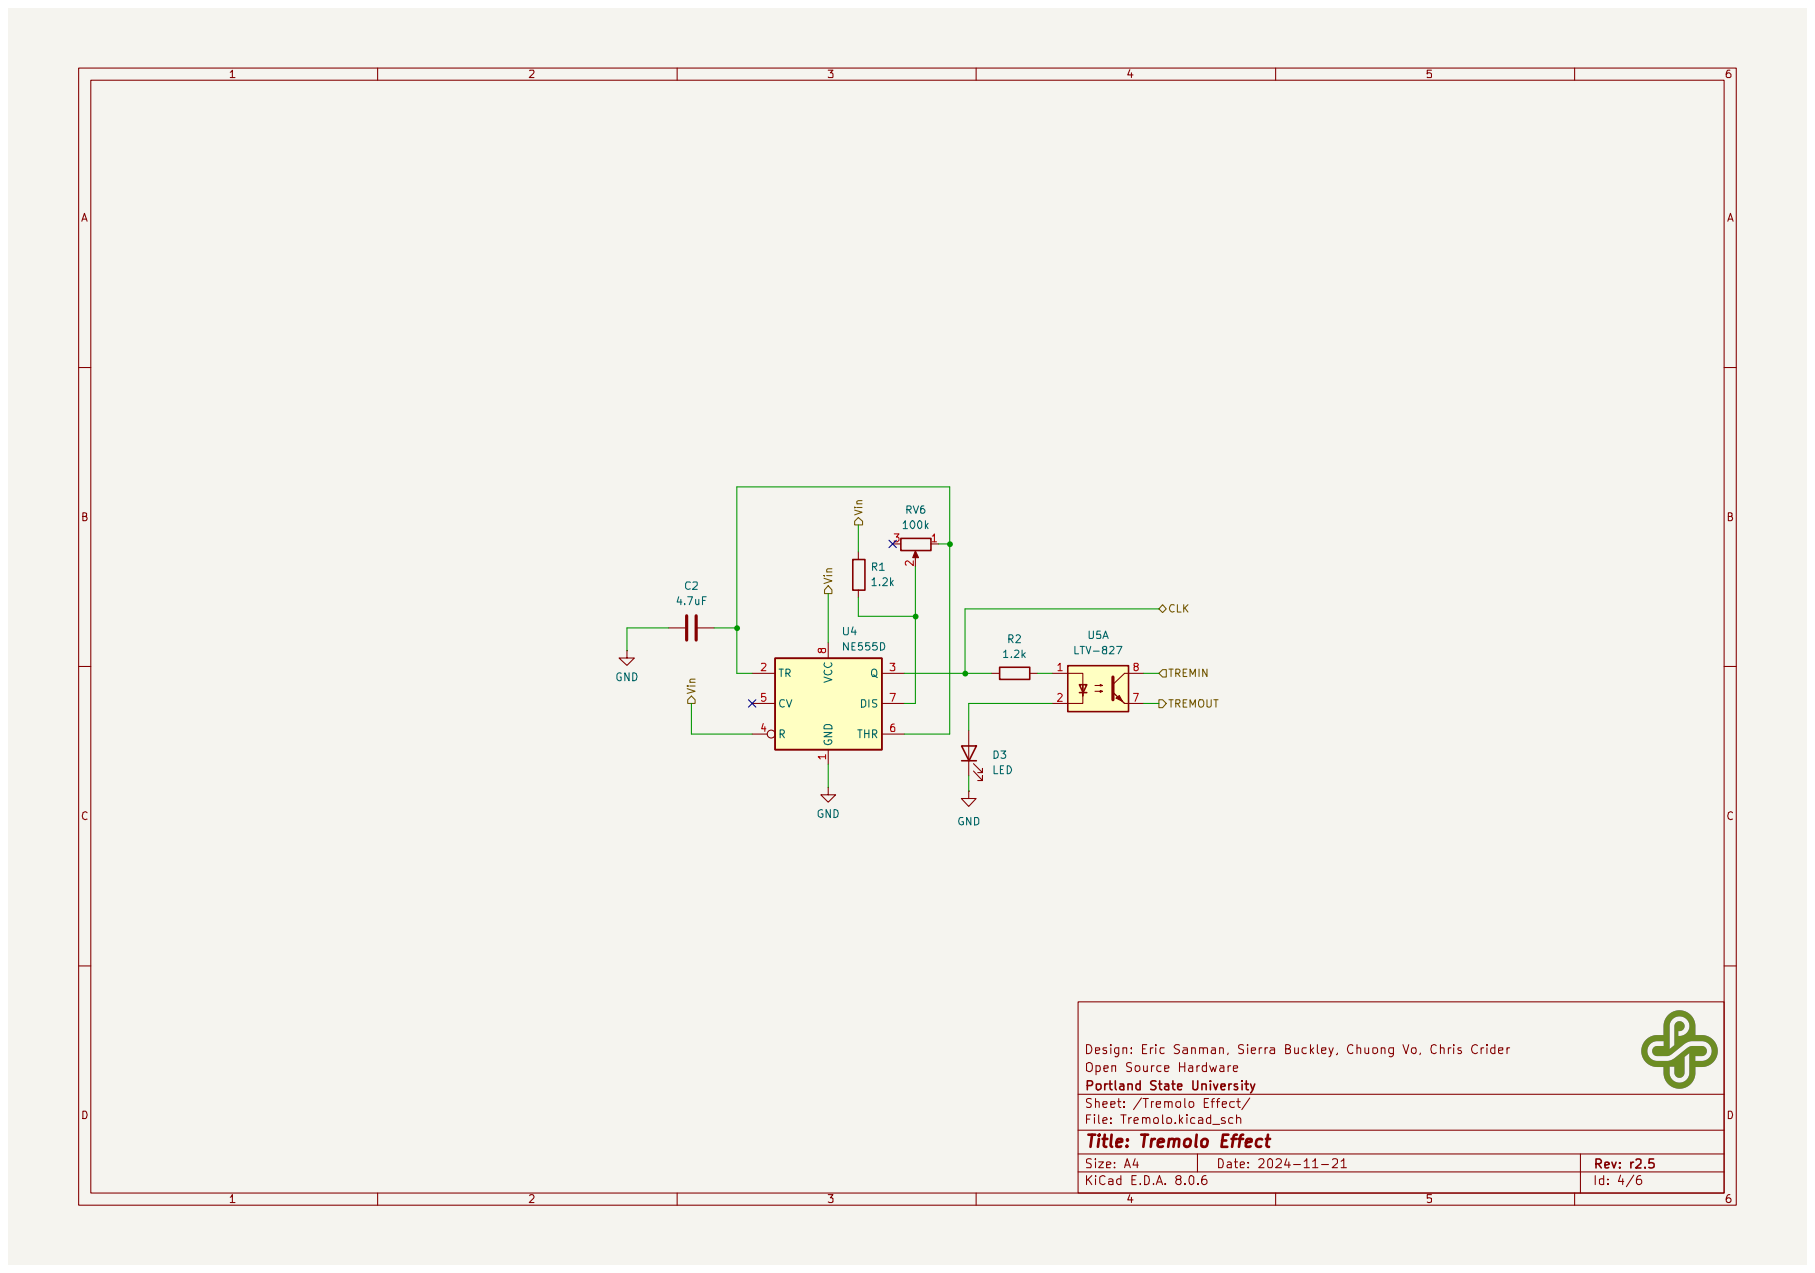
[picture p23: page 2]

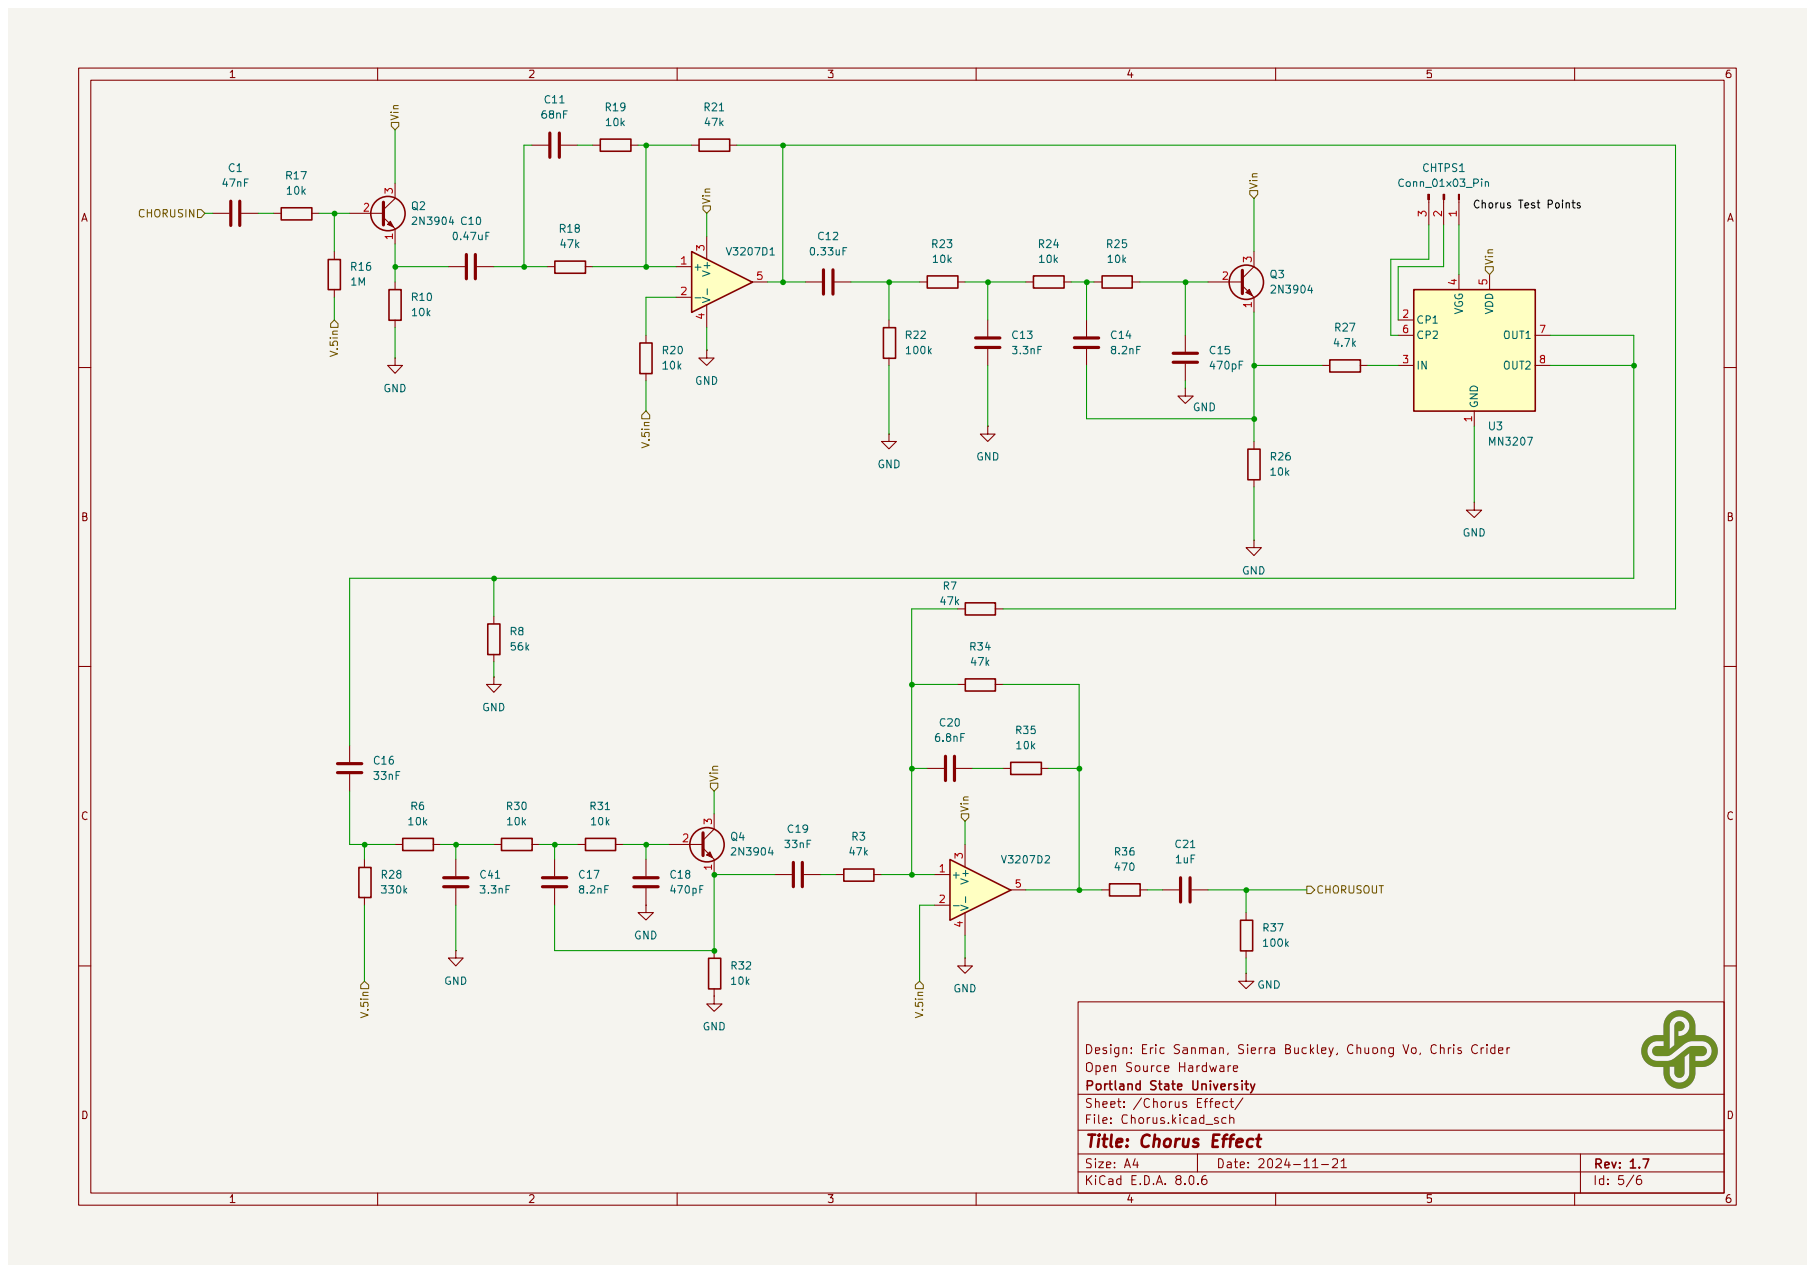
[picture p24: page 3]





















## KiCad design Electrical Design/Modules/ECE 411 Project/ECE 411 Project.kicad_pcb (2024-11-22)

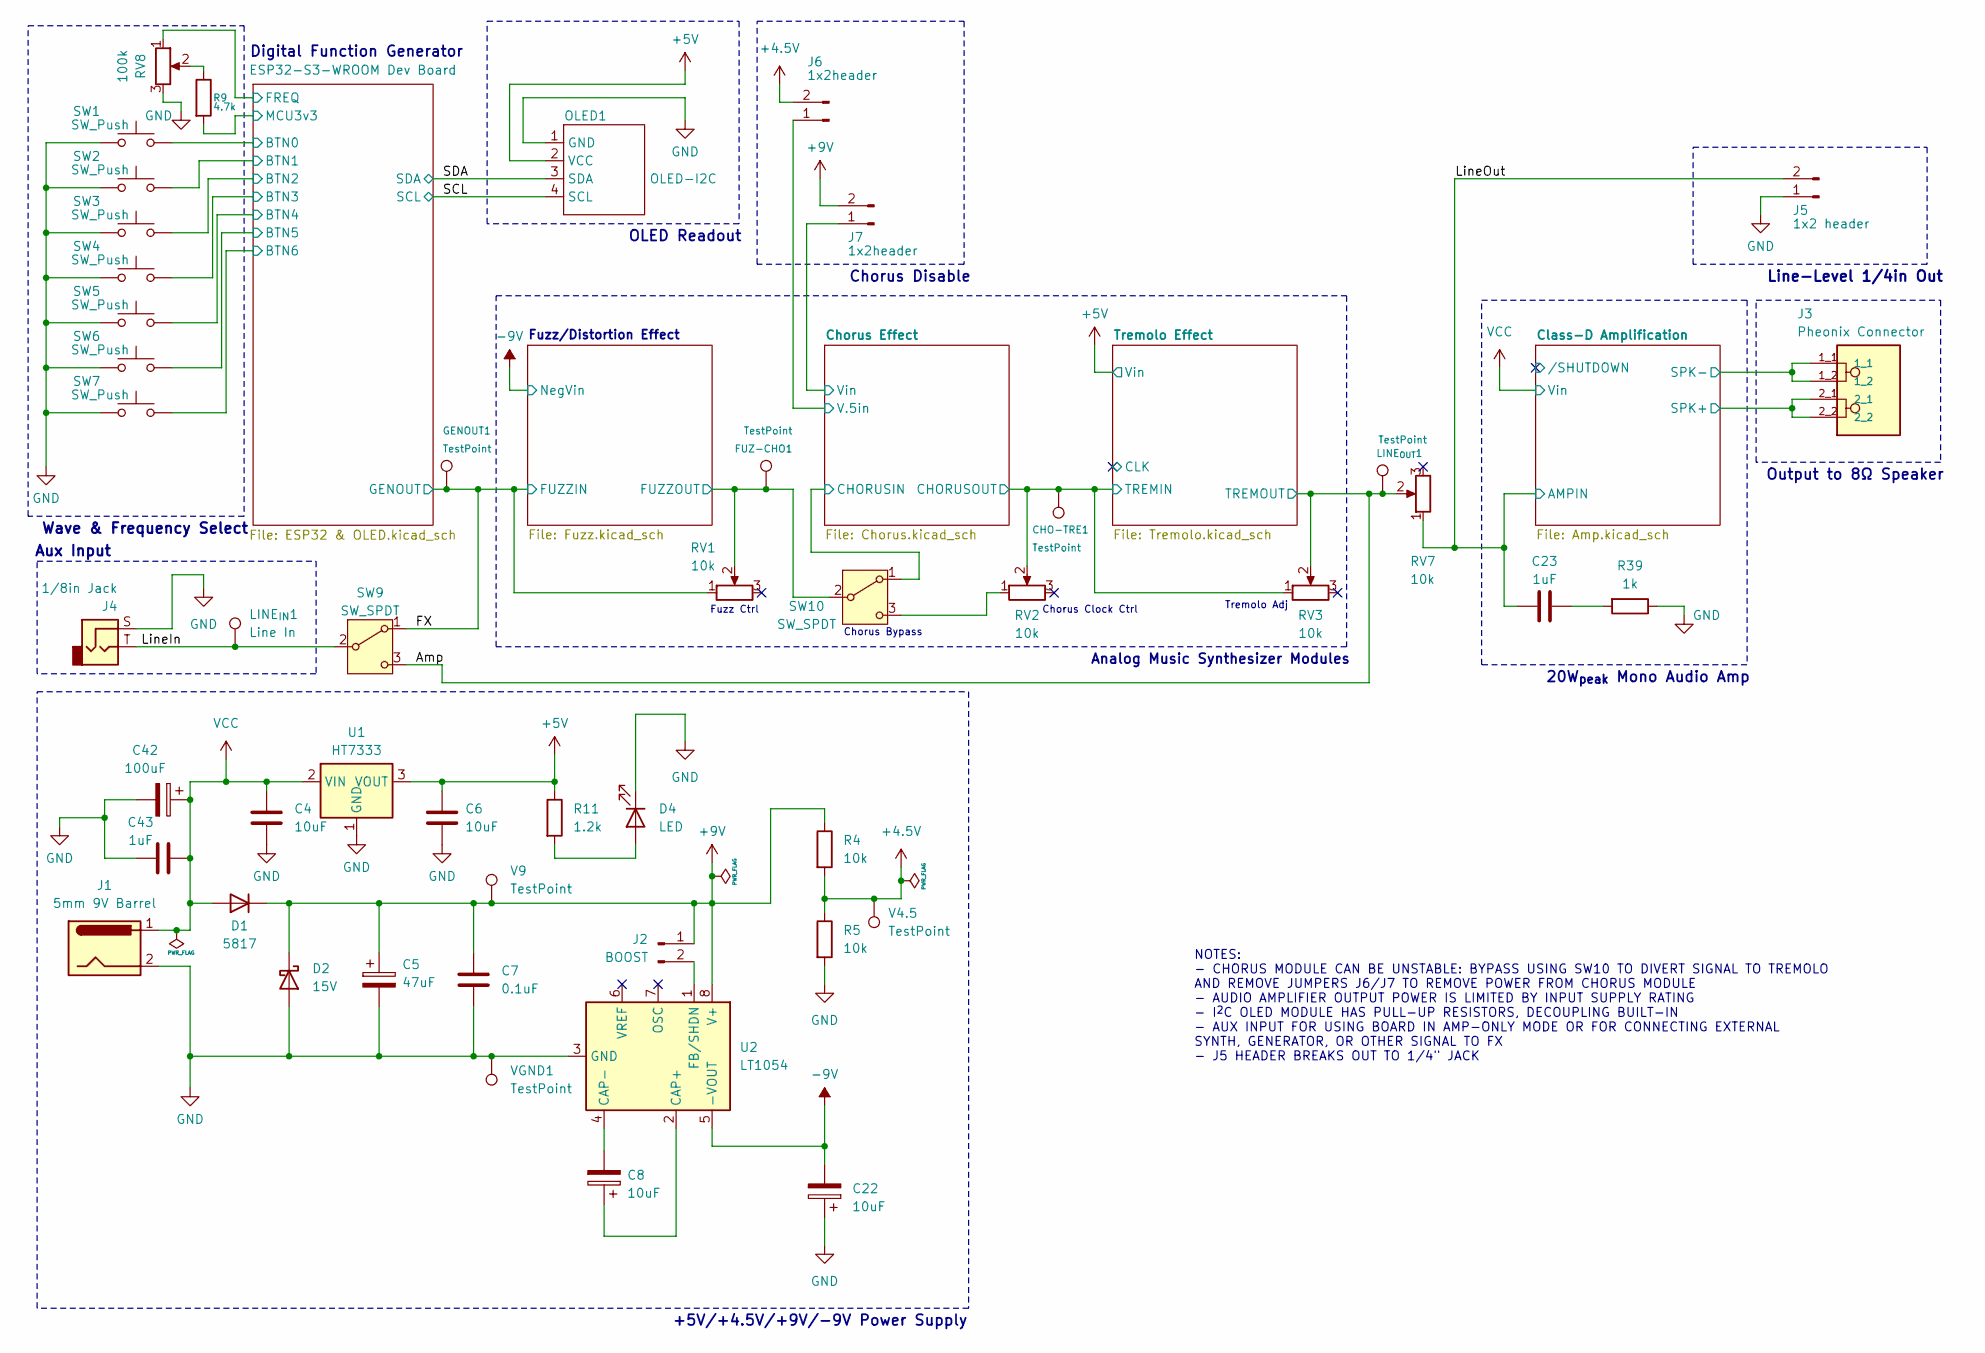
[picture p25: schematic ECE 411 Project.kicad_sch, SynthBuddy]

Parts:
C4, C6: 10uF; C_1206_3216Metric_Pad1.33x1.80mm_HandSolder; Part_Number CL31B106KAHNFNE
C5: 47uF; CP_Radial_D8.0mm_P3.50mm; Part_Number UVK2A470MPD
C7: 0.1uF; C_0805_2012Metric_Pad1.18x1.45mm_HandSolder; Part_Number CL21B104KCFNNNE
C8: 10uF; CP_Radial_D8.0mm_P3.50mm; Part_Number UVR2C100MPD
C22: 10uF; CP_Radial_D7.5mm_P2.50mm; Part_Number UVR2C100MPD
C23: 1uF; C_0805_2012Metric_Pad1.18x1.45mm_HandSolder; Part_Origin DK
C42: 100uF; CP_Radial_D8.0mm_P3.50mm; Part_Origin DK
C43: 1uF; C_0805_2012Metric_Pad1.18x1.45mm_HandSolder; Part_Number CL21B104KBCNNNC
CHO-TRE1: TestPoint; TestPoint_Loop_D3.80mm_Drill2.5mm
D1: 5817; D_0805_2012Metric_Pad1.15x1.40mm_HandSolder; Part_Origin DK
D2: 15V; D_DO-41_SOD81_P10.16mm_Horizontal; Part_Origin DK
D4: LED; LED_D5.0mm
FUZ-CHO1: TestPoint; TestPoint_Loop_D3.80mm_Drill2.5mm
GENOUT1: TestPoint; TestPoint_Loop_D3.80mm_Drill2.5mm
J1: 5mm 9V Barrel; BarrelJack_Horizontal
J2: BOOST; PinHeader_1x02_P2.54mm_Vertical
J3: Pheonix Connector; PHOENIX_1190297; PARTREV 03.11.2020
J4: 1/8in Jack; Jack_3.5mm_CUI_SJ-3523-SMT_Horizontal
J5: 1x2 header; PinSocket_1x02_P2.54mm_Vertical
J6, J7: 1x2header; PinSocket_1x02_P2.54mm_Vertical
LINE_{IN}1: Line In; TestPoint_Loop_D3.80mm_Drill2.5mm
LINE_{OUT}1: TestPoint; TestPoint_Loop_D3.80mm_Drill2.5mm
OLED1: OLED-I2C; PinHeader_1x04_P2.54mm_Vertical
R4, R5: 10k; R_0805_2012Metric_Pad1.20x1.40mm_HandSolder; Part_Origin DK
R9: 4.7k; R_0805_2012Metric_Pad1.20x1.40mm_HandSolder
R11: 1.2k; R_0805_2012Metric_Pad1.20x1.40mm_HandSolder
R39: 1k; R_0805_2012Metric_Pad1.20x1.40mm_HandSolder; Part_Origin DK
RV1, RV2, RV3: 10k; PinSocket_1x02_P2.54mm_Vertical; Part_Origin AMZ
RV7: 10k; PinSocket_1x02_P2.54mm_Vertical; Part_Origin DK
RV8: 100k; PinSocket_1x03_P2.54mm_Vertical; Part_Origin AMZ
SW1, SW2, SW3, SW4, SW5, SW6, SW7: SW_Push; PinHeader_1x02_P2.54mm_Vertical; Part_Origin TAYDA
SW9, SW10: SW_SPDT; SW_Slide_SPDT_Angled_CK_OS102011MA1Q
U1: HT7333; SOT-89-3; Part_Origin SBP
U2: LT1054; CERDIP-8_W7.62mm_SideBrazed; Part_Origin SBP
V4.5, V9: TestPoint; TestPoint_Loop_D3.80mm_Drill2.5mm
VGND1: TestPoint; TestPoint_Loop_D3.80mm_Drill2.5mm

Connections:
+4.5V: J6.2, R4.2, R5.1, V4.5.1
+5V: C6.1, OLED1.2 (VCC), R11.1, U1.3 (VOUT); also elsewhere on the board
+9V: C5.1, C7.1, D1.1 (K), D2.1 (K), J2.1, J7.2, R4.1, U2.8 (V+), V9.1
-9V: C22.2, U2.5 (-VOUT); also elsewhere on the board
/Amp: LINE_{OUT}1.1, RV3.2, RV7.2, SW9.3 (C); also elsewhere on the board
/Chorus Effect/CHORUSIN: SW10.1 (A); also elsewhere on the board
/Chorus Effect/CHORUSOUT: CHO-TRE1.1, RV2.2, RV3.1; also elsewhere on the board
/Chorus Effect/V.5in: J6.1; also elsewhere on the board
/Chorus Effect/Vin: J7.1; also elsewhere on the board
/Class-D Amplification/SPK+: J3.2_1, J3.2_2; also elsewhere on the board
/Class-D Amplification/SPK-: J3.1_1, J3.1_2; also elsewhere on the board
/ESP32-S3-WROOM Dev Board/BTN0: SW1.2; also elsewhere on the board
/ESP32-S3-WROOM Dev Board/BTN1: SW2.2; also elsewhere on the board
/ESP32-S3-WROOM Dev Board/BTN2: SW3.2; also elsewhere on the board
/ESP32-S3-WROOM Dev Board/BTN3: SW4.2; also elsewhere on the board
/ESP32-S3-WROOM Dev Board/BTN4: SW5.2; also elsewhere on the board
/ESP32-S3-WROOM Dev Board/BTN5: SW6.2; also elsewhere on the board
/ESP32-S3-WROOM Dev Board/BTN6: SW7.2; also elsewhere on the board
/ESP32-S3-WROOM Dev Board/FREQ: RV8.1; also elsewhere on the board
/ESP32-S3-WROOM Dev Board/MCU3v3: R9.2; also elsewhere on the board
/FX: GENOUT1.1, RV1.1, SW9.1 (A); also elsewhere on the board
/Fuzz Schematic/FUZZOUT: FUZ-CHO1.1, RV1.2, SW10.2 (B); also elsewhere on the board
/LineIn: J4.T, LINE_{IN}1.1, SW9.2 (B)
/LineOut: C23.1, J5.2, RV7.1; also elsewhere on the board
/SCL: OLED1.4 (SCL); also elsewhere on the board
/SDA: OLED1.3 (SDA); also elsewhere on the board
GND: C4.2, C5.2, C6.2, C7.2, C22.1, C42.2, C43.1, D2.2 (A), D4.1 (K), J1.2, J4.S, J5.1, OLED1.1 (GND), R5.2, R39.1, RV8.3, SW1.1, SW2.1, SW3.1, SW4.1, SW5.1, SW6.1, SW7.1, U1.1 (GND), U2.3 (GND), VGND1.1; also elsewhere on the board
unnamed: C23.2, R39.2
unnamed: D4.2 (A), R11.2
unnamed: J2.2, U2.1 (FB/SHDN)
unnamed: R9.1, RV8.2
unnamed: RV2.1, SW10.3 (C)
unnamed: C8.1, U2.2 (CAP+)
unnamed: C8.2, U2.4 (CAP-)
Vin: C4.1, C42.1, C43.2, D1.2 (A), J1.1, U1.2 (VIN); also elsewhere on the board

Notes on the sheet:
Output to 8Ω Speaker
20W_{peak} Mono Audio Amp
Chorus Disable
Analog Music Synthesizer Modules
Fuzz Ctrl
Line-Level 1/4in Out
+5V/+4.5V/+9V/-9V Power Supply
Digital Function Generator
Chorus Clock Ctrl
OLED Readout
Tremolo Adj
Wave & Frequency Select
Aux Input
Chorus Bypass
Fuzz/Distortion Effect
NOTES: - CHORUS MODULE CAN BE UNSTABLE: BYPASS USING SW10 TO DIVERT SIGNAL TO TREMOLO AND REMOVE JUMPERS J6/J7 TO REMOVE POWER FROM CHORUS MODULE - AUDIO AMPLIFIER OUTPUT POWER IS LIMITED BY INPUT SUPPLY RATING - I^{2}C OLED MODULE HAS PULL-UP RESISTORS, DECOUPLING BUILT-IN - AUX INPUT FOR USING BO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

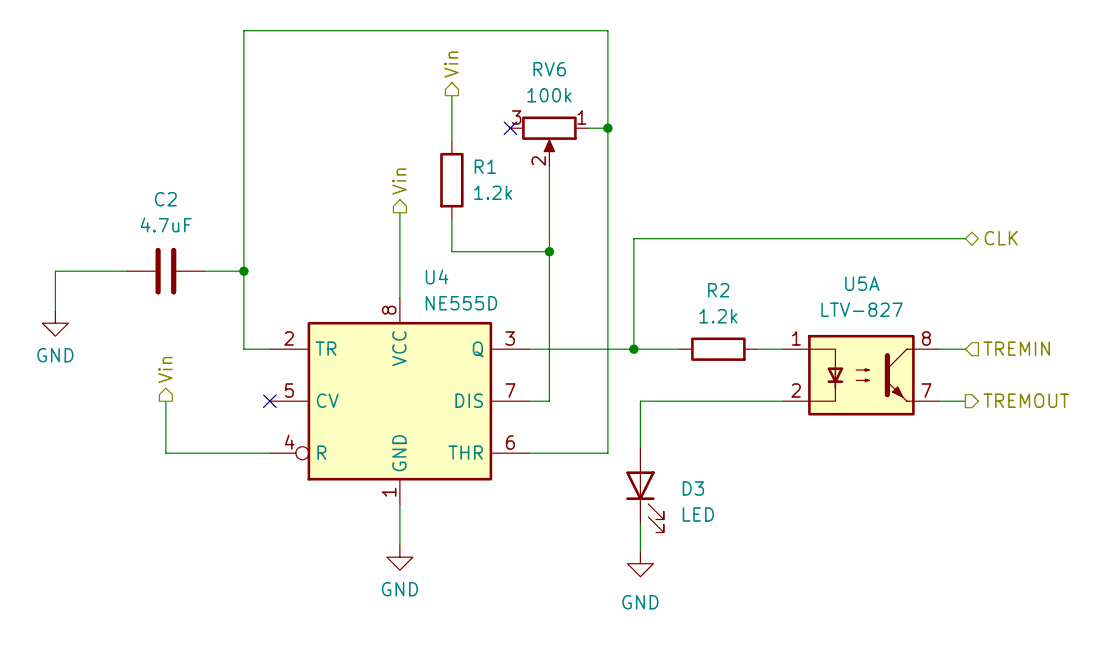
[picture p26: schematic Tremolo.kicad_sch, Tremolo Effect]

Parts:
C2: 4.7uF; C_1206_3216Metric_Pad1.33x1.80mm_HandSolder; Part_Number CL31B475KAHNNNE
D3: LED; LED_D5.0mm; Part_Origin DK
R1, R2: 1.2k; R_0805_2012Metric_Pad1.20x1.40mm_HandSolder; Part_Origin DK
RV6: 100k; PinSocket_1x02_P2.54mm_Vertical; Part_Origin DK
U4: NE555D; SOIC-8_3.9x4.9mm_P1.27mm; Part_Origin DK
U5: LTV-827; DIP-8_W7.62mm; Part_Origin SBP

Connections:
+5V: R1.1, U4.4 (R), U4.8 (VCC); also elsewhere on the board
/Amp: U5.7; also elsewhere on the board
/Chorus Effect/CHORUSOUT: U5.8; also elsewhere on the board
/Tremolo Effect/CLK: R2.1, U4.3 (Q)
GND: C2.1, D3.1 (K), U4.1 (GND); also elsewhere on the board
unnamed: D3.2 (A), U5.2
unnamed: R2.2, U5.1
unnamed: R1.2, RV6.2, U4.7 (DIS)
unnamed: C2.2, RV6.1, U4.2 (TR), U4.6 (THR)

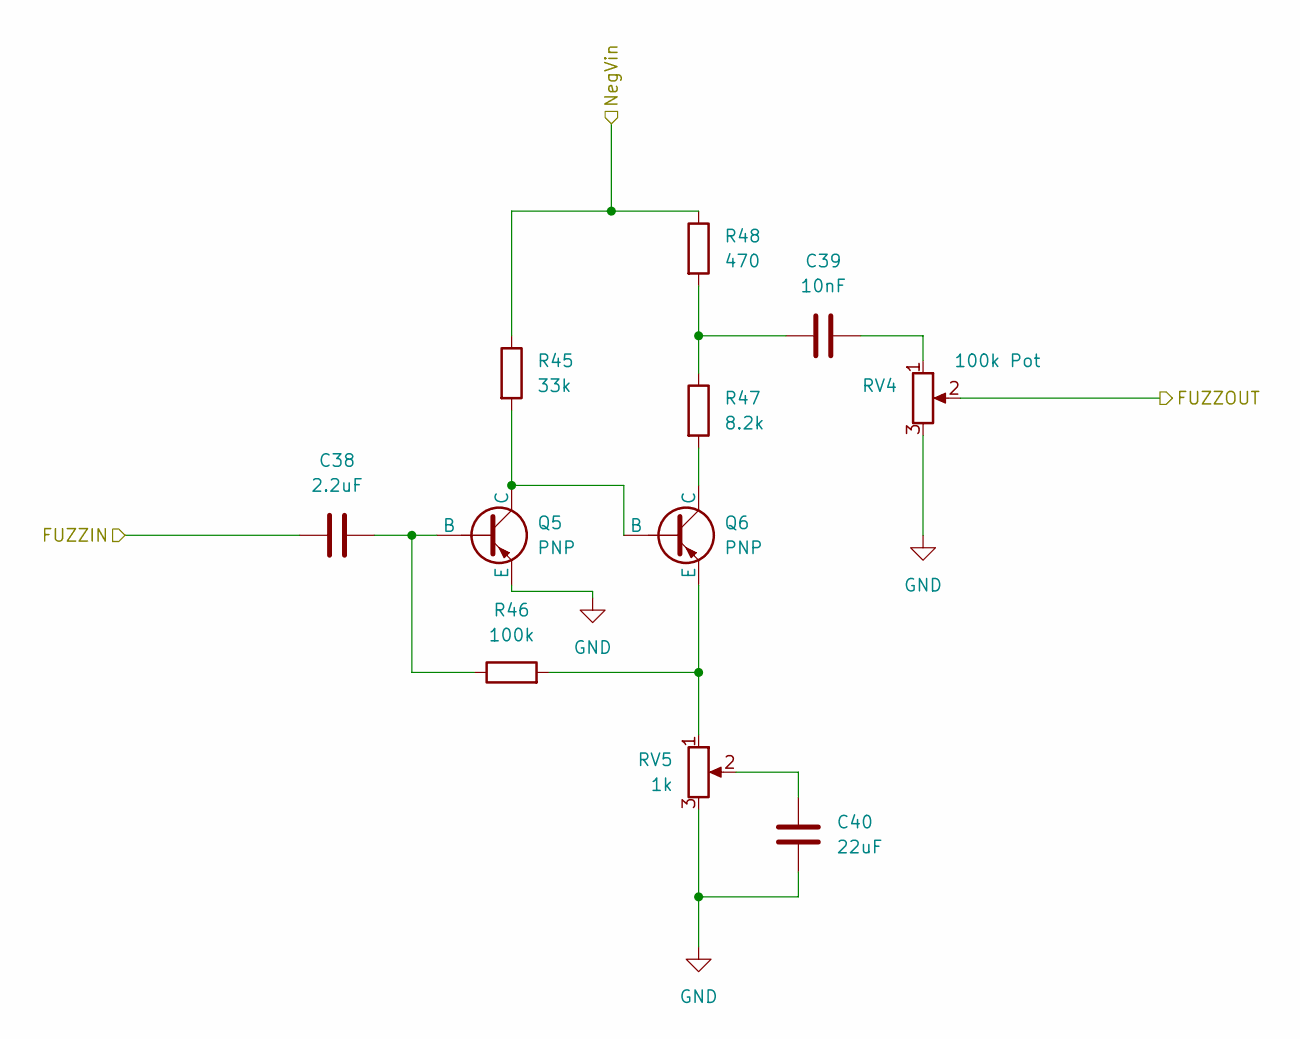
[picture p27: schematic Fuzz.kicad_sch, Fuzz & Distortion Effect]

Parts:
C38: 2.2uF; C_0805_2012Metric_Pad1.18x1.45mm_HandSolder; Part_Origin DK
C39: 10nF; C_0805_2012Metric_Pad1.18x1.45mm_HandSolder; Part_Origin DK
C40: 22uF; C_1206_3216Metric_Pad1.33x1.80mm_HandSolder; Part_Origin DK
Q5, Q6: PNP; TO-52-3
R45: 33k; R_0805_2012Metric_Pad1.20x1.40mm_HandSolder; Part_Origin DK
R46: 100k; R_0805_2012Metric_Pad1.20x1.40mm_HandSolder; Part_Origin DK
R47: 8.2k; R_0805_2012Metric_Pad1.20x1.40mm_HandSolder; Part_Origin DK
R48: 470; R_0805_2012Metric_Pad1.20x1.40mm_HandSolder; Part_Origin DK
RV4: 100k Pot; PinHeader_1x03_P2.54mm_Vertical; Part_Origin AMZ
RV5: 1k; PinSocket_1x03_P2.54mm_Vertical; Part_Origin AMZ

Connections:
-9V: R45.1, R48.1; also elsewhere on the board
/FX: C38.1; also elsewhere on the board
/Fuzz Schematic/FUZZOUT: RV4.2; also elsewhere on the board
GND: C40.1, Q5.3 (E), RV4.3, RV5.3; also elsewhere on the board
unnamed: C39.1, R47.1, R48.2
unnamed: C39.2, RV4.1
unnamed: C40.2, RV5.2
unnamed: C38.2, Q5.2 (B), R46.1
unnamed: Q5.1 (C), Q6.2 (B), R45.2
unnamed: Q6.1 (C), R47.2
unnamed: Q6.3 (E), R46.2, RV5.1

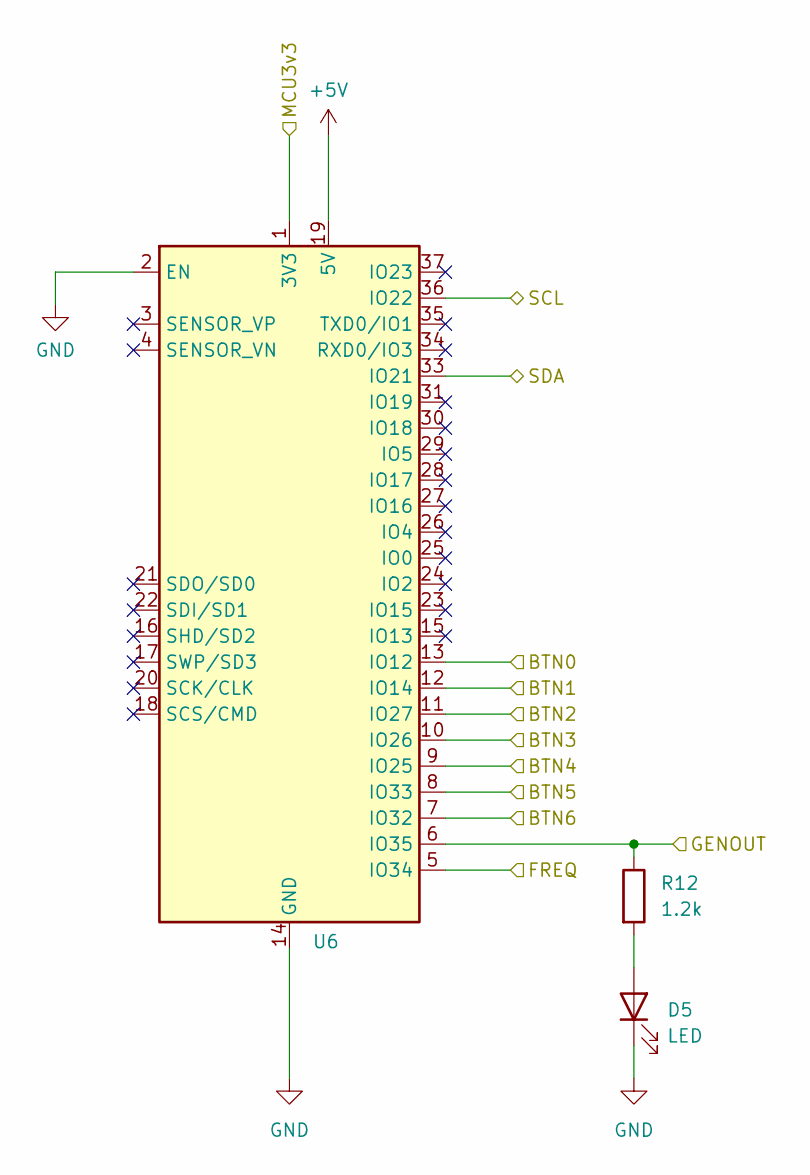
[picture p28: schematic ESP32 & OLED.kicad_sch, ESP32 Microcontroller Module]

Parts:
D5: LED; LED_D5.0mm
R12: 1.2k; R_0805_2012Metric_Pad1.20x1.40mm_HandSolder
U6: PinHeader_ESP32_WROOM_Narrow

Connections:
+5V: U6.19 (5V); also elsewhere on the board
/ESP32-S3-WROOM Dev Board/BTN0: U6.13 (IO12); also elsewhere on the board
/ESP32-S3-WROOM Dev Board/BTN1: U6.12 (IO14); also elsewhere on the board
/ESP32-S3-WROOM Dev Board/BTN2: U6.11 (IO27); also elsewhere on the board
/ESP32-S3-WROOM Dev Board/BTN3: U6.10 (IO26); also elsewhere on the board
/ESP32-S3-WROOM Dev Board/BTN4: U6.9 (IO25); also elsewhere on the board
/ESP32-S3-WROOM Dev Board/BTN5: U6.8 (IO33); also elsewhere on the board
/ESP32-S3-WROOM Dev Board/BTN6: U6.7 (IO32); also elsewhere on the board
/ESP32-S3-WROOM Dev Board/FREQ: U6.5 (IO34); also elsewhere on the board
/ESP32-S3-WROOM Dev Board/MCU3v3: U6.1 (3V3); also elsewhere on the board
/FX: R12.1, U6.6 (IO35); also elsewhere on the board
/SCL: U6.36 (IO22); also elsewhere on the board
/SDA: U6.33 (IO21); also elsewhere on the board
GND: D5.1 (K), U6.2 (EN), U6.14 (GND), U6.15 (GND), U6.38 (GND), U6.39 (GND); also elsewhere on the board
unnamed: D5.2 (A), R12.2

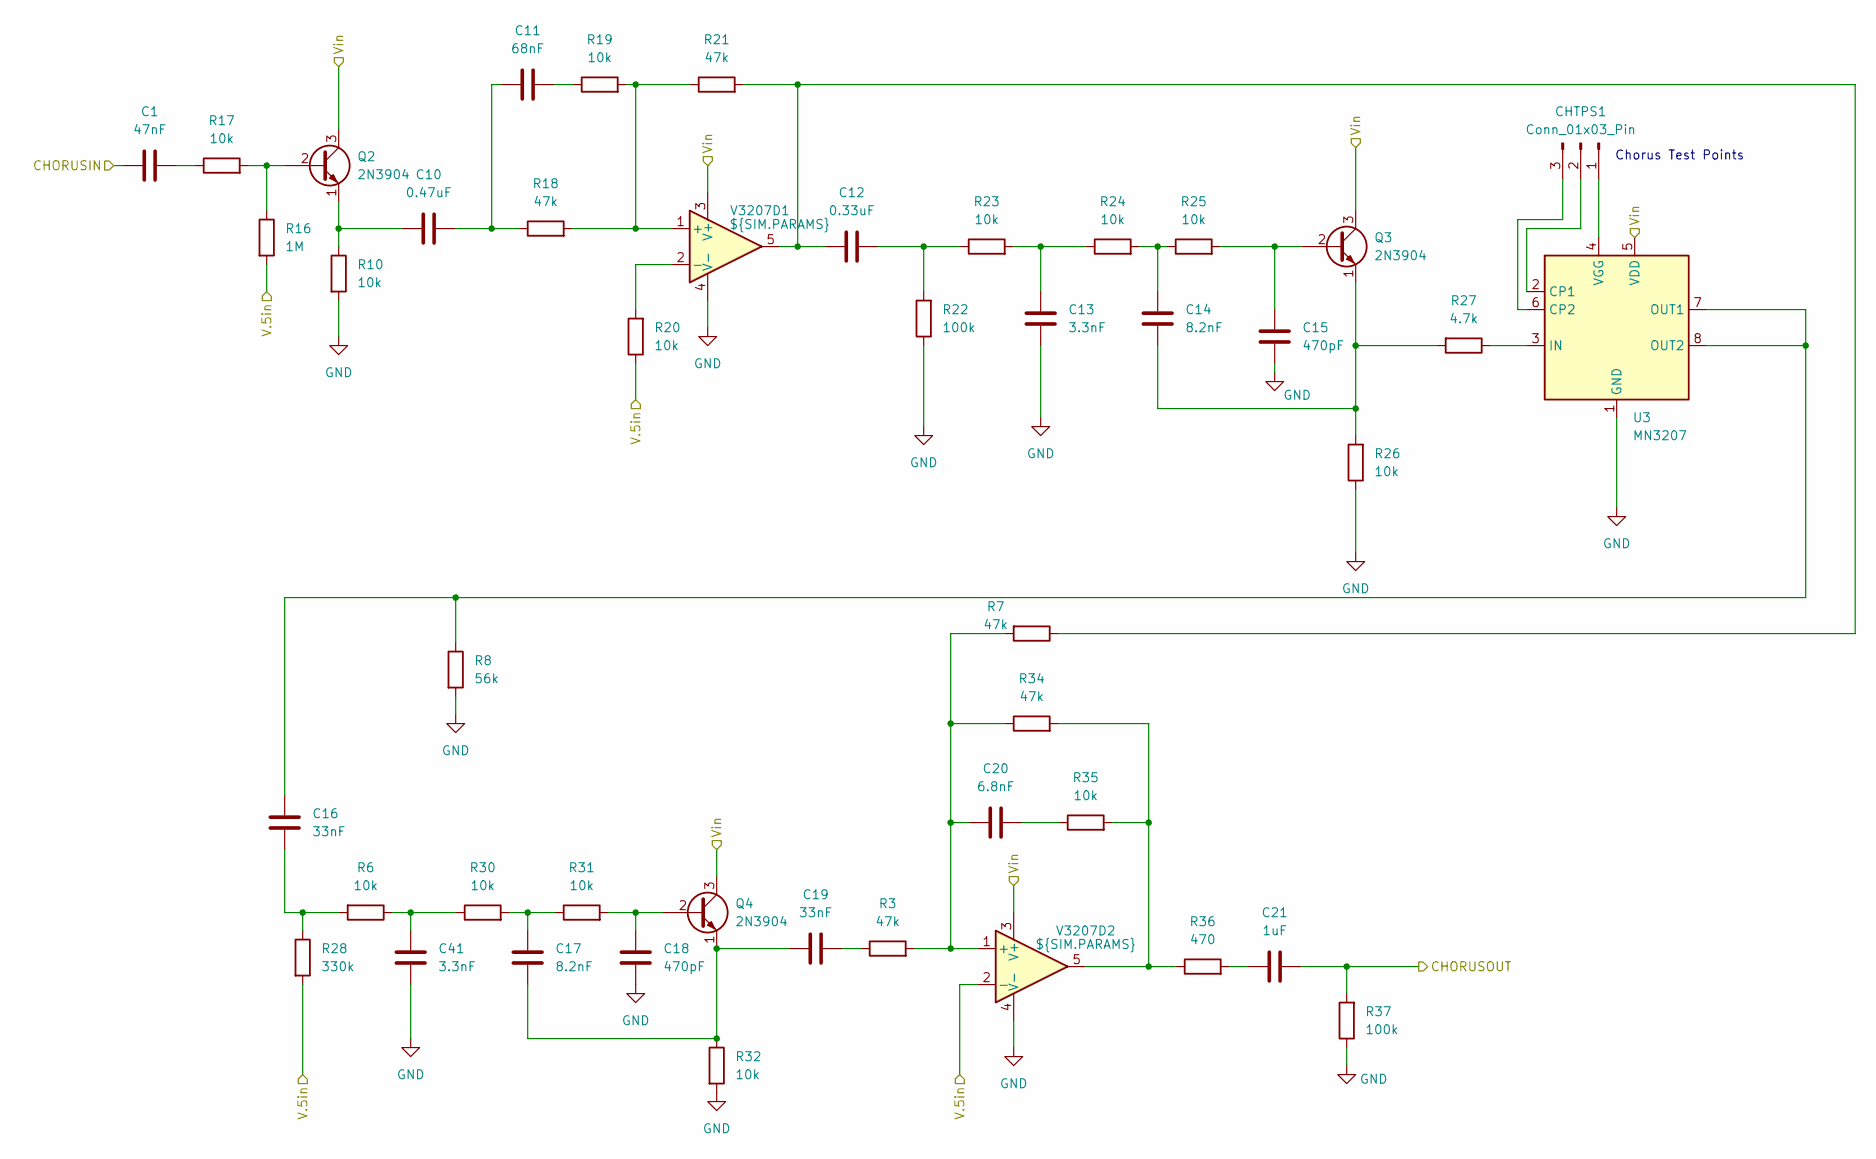
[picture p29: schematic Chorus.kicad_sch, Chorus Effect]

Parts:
C1: 47nF; C_0805_2012Metric_Pad1.18x1.45mm_HandSolder; Part_Number CL21B473KBCNNNC
C10: 0.47uF; C_0805_2012Metric_Pad1.18x1.45mm_HandSolder; Part_Number CL21B473KBCNNNC
C11: 68nF; C_0805_2012Metric_Pad1.18x1.45mm_HandSolder; Part_Number KGM21NR71H683KT
C12: 0.33uF; C_0805_2012Metric_Pad1.18x1.45mm_HandSolder; Part_Number CL21B334KBFNNNE
C13, C41: 3.3nF; C_0805_2012Metric_Pad1.18x1.45mm_HandSolder; Part_Number C0805C332K1RECAUTO
C14, C17: 8.2nF; C_0805_2012Metric_Pad1.18x1.45mm_HandSolder; Part_Number C0402C822K1RACAUTO
C15, C18: 470pF; C_0805_2012Metric_Pad1.18x1.45mm_HandSolder; Part_Number C0805C471K5RAC7800
C16, C19: 33nF; C_0805_2012Metric_Pad1.18x1.45mm_HandSolder; Part_Number C0805C333K1RECAUTO
C20: 6.8nF; C_0805_2012Metric_Pad1.18x1.45mm_HandSolder; Part_Number C0805C682J1GEC7210
C21: 1uF; C_0805_2012Metric_Pad1.18x1.45mm_HandSolder; Part_Number CL21B104KBCNNNC
CHTPS1: Conn_01x03_Pin; PinSocket_1x03_P2.54mm_Vertical
Q2, Q3, Q4: 2N3904; TO-92_Inline
R3, R7, R18, R21, R34: 47k; R_0805_2012Metric_Pad1.20x1.40mm_HandSolder; Part_Origin DK
R6, R10, R17, R19, R20, R23, R24, R25, R26, R30, R31, R32, R35: 10k; R_0805_2012Metric_Pad1.20x1.40mm_HandSolder; Part_Origin DK
R8: 56k; R_0805_2012Metric_Pad1.20x1.40mm_HandSolder; Part_Origin DK
R16: 1M; R_0805_2012Metric_Pad1.20x1.40mm_HandSolder; Part_Origin DK
R22, R37: 100k; R_0805_2012Metric_Pad1.20x1.40mm_HandSolder; Part_Origin DK
R27: 4.7k; R_0805_2012Metric_Pad1.20x1.40mm_HandSolder; Part_Origin DK
R28: 330k; R_0805_2012Metric_Pad1.20x1.40mm_HandSolder; Part_Origin DK
R36: 470; R_0805_2012Metric_Pad1.20x1.40mm_HandSolder; Part_Origin DK
U3: MN3207; CERDIP-8_W7.62mm_SideBrazed; Part_Origin SBP
V3207D1, V3207D2: ${SIM.PARAMS}; CERDIP-8_W7.62mm_SideBrazed; Part_Number IC-400-1033

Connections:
/Chorus Effect/CHORUSIN: C1.1; also elsewhere on the board
/Chorus Effect/CHORUSOUT: C21.2, R37.2; also elsewhere on the board
/Chorus Effect/V.5in: R16.2, R20.1, R28.2, V3207D2.2 (-); also elsewhere on the board
/Chorus Effect/Vin: Q2.3 (C), Q3.3 (C), Q4.3 (C), U3.5 (VDD), V3207D1.3 (V+), V3207D2.3 (V+); also elsewhere on the board
GND: C13.1, C15.1, C18.1, C41.2, R8.2, R10.2, R22.1, R26.1, R32.2, R37.1, U3.1 (GND), V3207D1.4 (V-), V3207D2.4 (V-); also elsewhere on the board
unnamed: C1.2, R17.1
unnamed: C10.2, C11.1, R18.1
unnamed: C11.2, R19.1
unnamed: C12.1, R7.1, R21.2, V3207D1.5
unnamed: C12.2, R22.2, R23.1
unnamed: C13.2, R23.2, R24.1
unnamed: C14.2, R24.2, R25.1
unnamed: C16.2, R6.2, R28.1
unnamed: C17.2, R30.2, R31.1
unnamed: C19.2, R3.1
unnamed: C20.2, R35.1
unnamed: C21.1, R36.2
unnamed: C41.1, R6.1, R30.1
unnamed: CHTPS1.1, U3.4 (VGG)
unnamed: CHTPS1.2, U3.2 (CP1)
unnamed: CHTPS1.3, U3.6 (CP2)
unnamed: Q2.2 (B), R16.1, R17.2
unnamed: C10.1, Q2.1 (E), R10.1
unnamed: C15.2, Q3.2 (B), R25.2
unnamed: C14.1, Q3.1 (E), R26.2, R27.2
unnamed: C18.2, Q4.2 (B), R31.2
unnamed: C17.1, C19.1, Q4.1 (E), R32.1
unnamed: R34.2, R35.2, R36.1, V3207D2.5
unnamed: R27.1, U3.3 (IN)
unnamed: C16.1, R8.1, U3.7 (OUT1), U3.8 (OUT2)
unnamed: R18.2, R19.2, R21.1, V3207D1.1 (+)
unnamed: R20.2, V3207D1.2 (-)
unnamed: C20.1, R3.2, R7.2, R34.1, V3207D2.1 (+)

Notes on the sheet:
Chorus Test Points

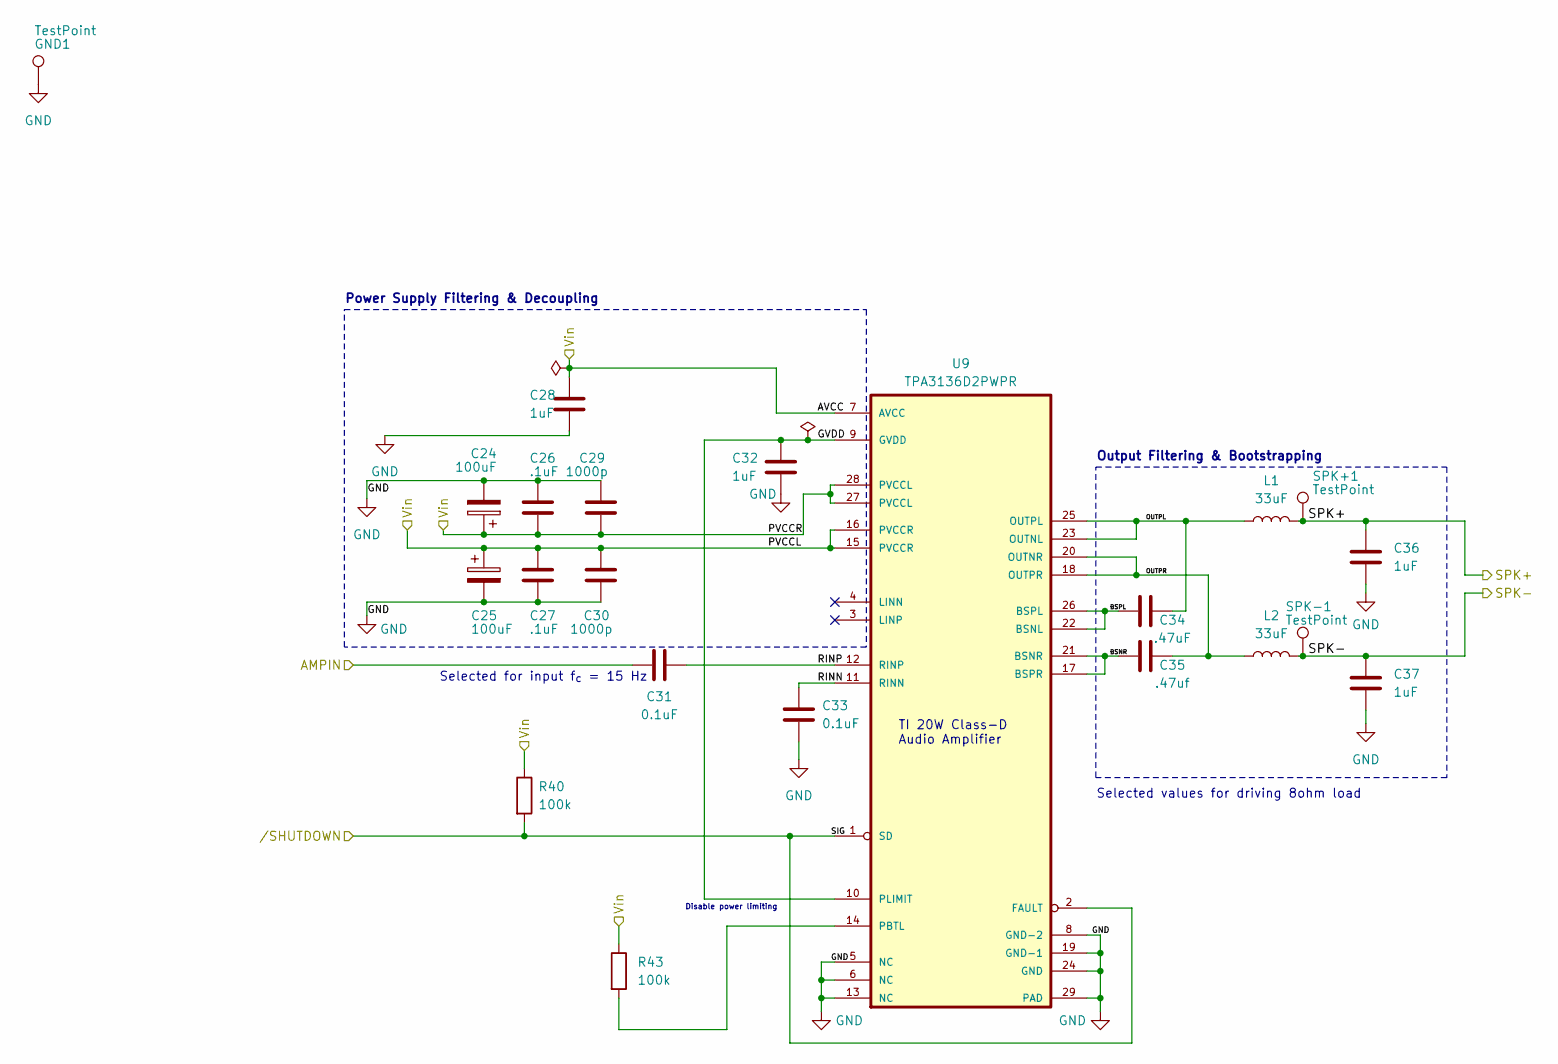
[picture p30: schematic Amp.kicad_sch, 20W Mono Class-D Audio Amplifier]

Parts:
C24, C25: 100uF; CP_Radial_D8.0mm_P3.50mm; Part_Origin DK
C26, C27: .1uF; C_0805_2012Metric_Pad1.18x1.45mm_HandSolder; Part_Origin DK
C28, C32, C36, C37: 1uF; C_0805_2012Metric_Pad1.18x1.45mm_HandSolder; Part_Origin DK
C29, C30: 1000p; C_0805_2012Metric_Pad1.18x1.45mm_HandSolder; Part_Origin DK
C31, C33: 0.1uF; C_0805_2012Metric_Pad1.18x1.45mm_HandSolder; Part_Origin DK
C34: .47uF; C_0805_2012Metric_Pad1.18x1.45mm_HandSolder; Part_Number 1276-1074-1-ND
C35: .47uf; C_0805_2012Metric_Pad1.18x1.45mm_HandSolder; Part_Number 1276-1074-1-ND
GND1: TestPoint; TestPoint_Loop_D3.80mm_Drill2.5mm; Part_Origin DK
L1, L2: 33uF; RL110-330K-RC
R40, R43: 100k; R_0805_2012Metric_Pad1.20x1.40mm_HandSolder; Part_Origin DK
SPK+1: TestPoint; TestPoint_Loop_D3.80mm_Drill2.5mm; Part_Origin DK
SPK-1: TestPoint; TestPoint_Loop_D3.80mm_Drill2.5mm; Part_Origin DK
U9: TPA3136D2PWPR; IC_TPS61196PWPRQ1; Part_Origin SBP

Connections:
/Class-D Amplification/BSNR: C35.1, U9.17 (BSPR), U9.21 (BSNR)
/Class-D Amplification/BSPL: C34.1, U9.22 (BSNL), U9.26 (BSPL)
/Class-D Amplification/GVDD: C32.2, U9.9 (GVDD), U9.10 (PLIMIT)
/Class-D Amplification/OUTPL: C34.2, L1.1, U9.23 (OUTNL), U9.25 (OUTPL)
/Class-D Amplification/OUTPR: C35.2, L2.1, U9.18 (OUTPR), U9.20 (OUTNR)
/Class-D Amplification/RINN: C33.1, U9.11 (RINN)
/Class-D Amplification/RINP: C31.1, U9.12 (RINP)
/Class-D Amplification/SIG: R40.2, U9.1 (SD), U9.2 (FAULT)
/Class-D Amplification/SPK+: C36.1, L1.2, SPK+1.1; also elsewhere on the board
/Class-D Amplification/SPK-: C37.1, L2.2, SPK-1.1; also elsewhere on the board
/LineOut: C31.2; also elsewhere on the board
GND: C24.2, C25.2, C26.1, C27.2, C28.2, C29.1, C30.2, C32.1, C33.2, C36.2, C37.2, GND1.1, U9.5 (NC), U9.6 (NC), U9.8 (GND-2), U9.13 (NC), U9.19 (GND-1), U9.24 (GND), U9.29 (PAD); also elsewhere on the board
unnamed: R43.2, U9.14 (PBTL)
Vin: C24.1, C25.1, C26.2, C27.1, C28.1, C29.2, C30.1, R40.1, R43.1, U9.7 (AVCC), U9.15 (PVCCR), U9.16 (PVCCR), U9.27 (PVCCL), U9.28 (PVCCL); also elsewhere on the board

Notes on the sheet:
TI 20W Class-D Audio Amplifier
Output Filtering & Bootstrapping
Selected for input f_{c} = 15 Hz
Disable power limiting
Selected values for driving 8ohm load
Power Supply Filtering & Decoupling

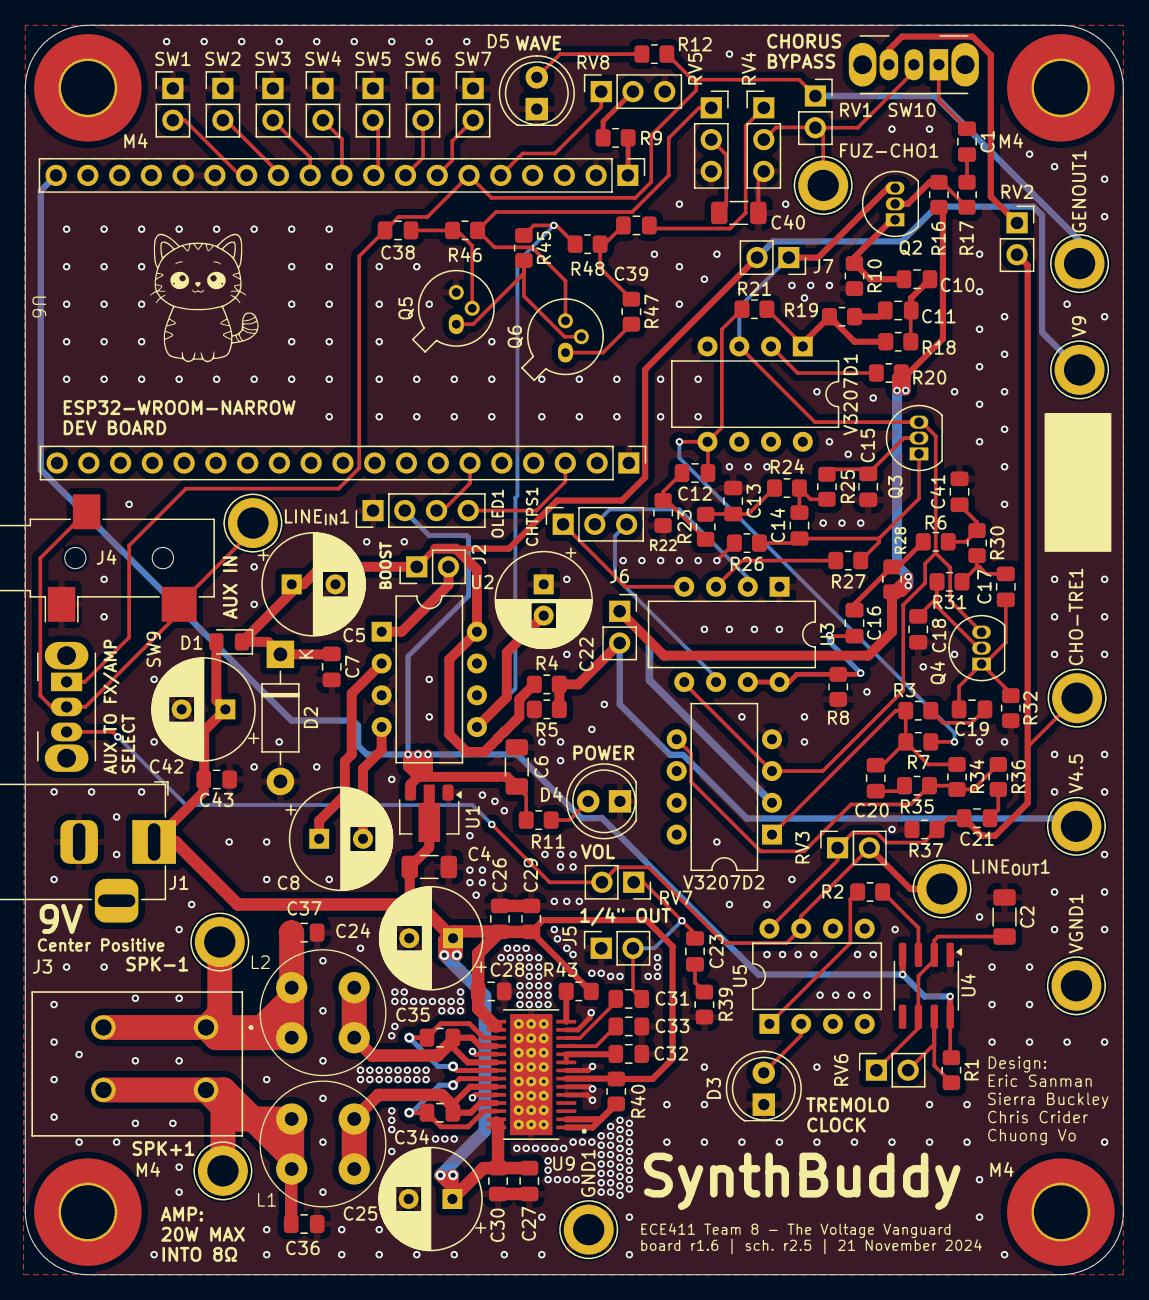
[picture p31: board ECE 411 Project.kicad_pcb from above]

Board: 2 copper layers, 87.8 x 99.9 mm, 142 parts (0 on the bottom side), 85 nets.

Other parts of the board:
M4, M4#2, M4#3, M4#4: MountingHole_4.3mm_M4_Pad_TopBottom

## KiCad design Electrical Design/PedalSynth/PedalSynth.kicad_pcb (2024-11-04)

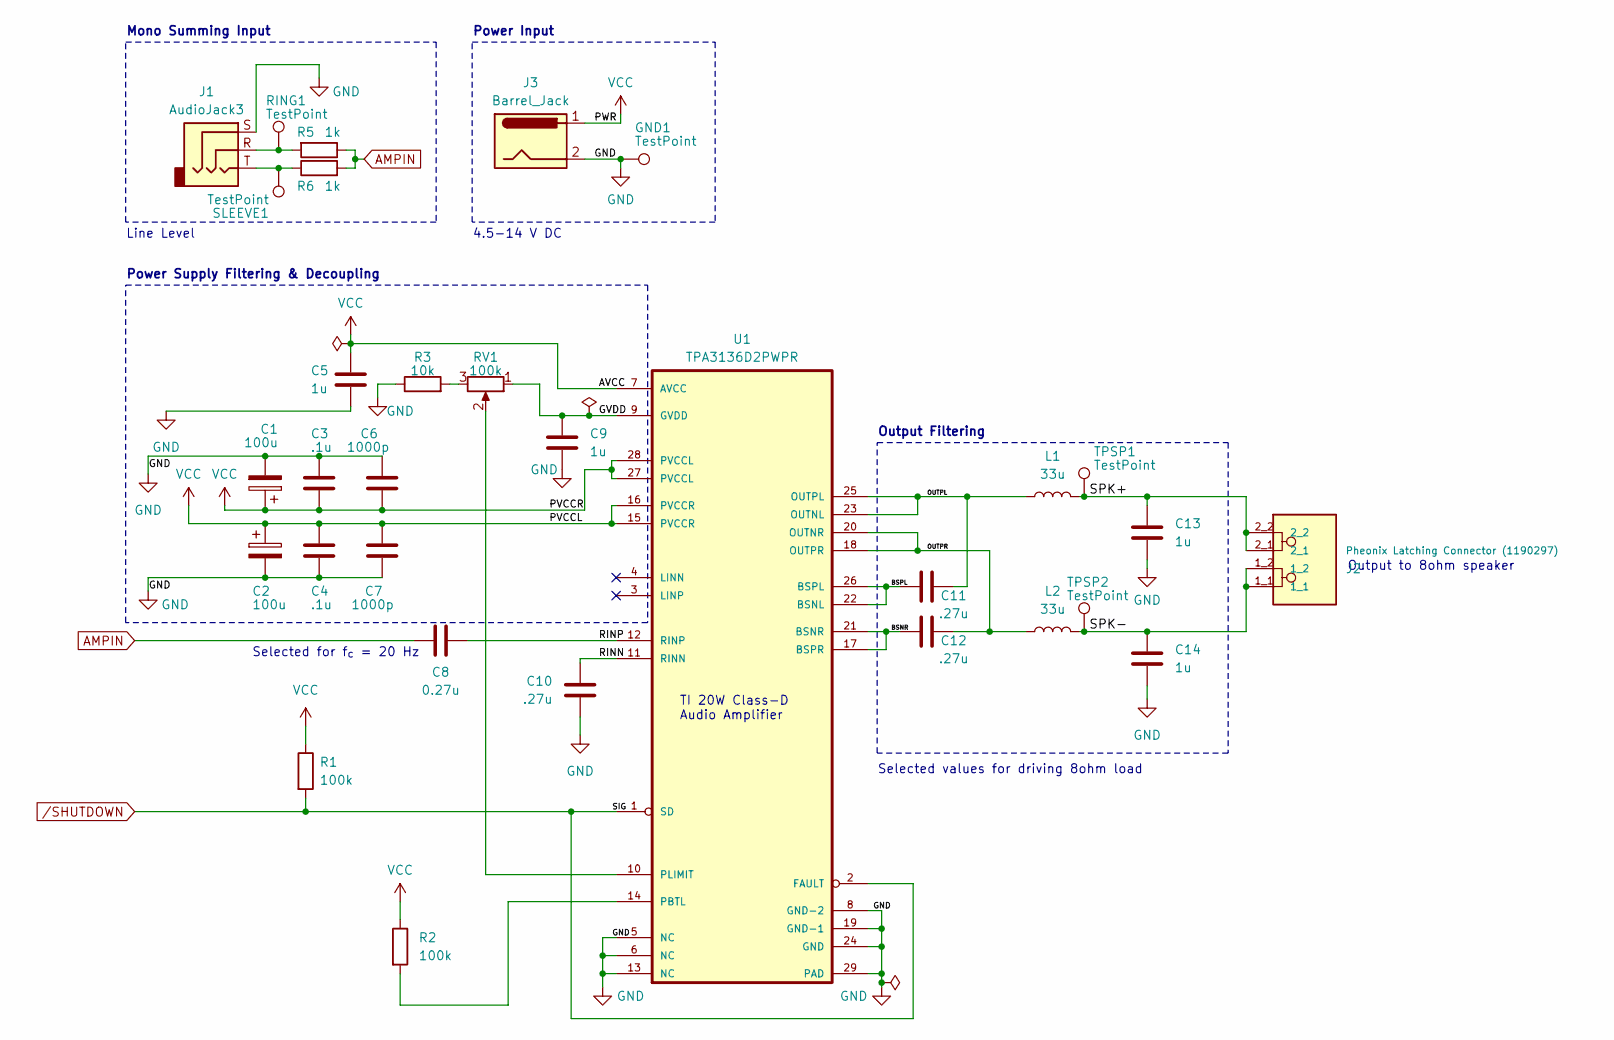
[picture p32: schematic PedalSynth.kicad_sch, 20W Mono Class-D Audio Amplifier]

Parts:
C1, C2: 100u; CP_Radial_D8.0mm_P3.50mm
C3, C4: .1u; C_0805_2012Metric_Pad1.18x1.45mm_HandSolder
C5, C9, C13, C14: 1u; C_0805_2012Metric_Pad1.18x1.45mm_HandSolder
C6, C7: 1000p; C_0402_1005Metric_Pad0.74x0.62mm_HandSolder
C8: 0.27u; C_0402_1005Metric_Pad0.74x0.62mm_HandSolder
C10, C11, C12: .27u; C_0402_1005Metric_Pad0.74x0.62mm_HandSolder
GND1: TestPoint; TestPoint_Bridge_Pitch2.0mm_Drill0.7mm
J1: AudioJack3; Jack_3.5mm_CUI_SJ-3523-SMT_Horizontal
J2: Pheonix Latching Connector (1190297); PHOENIX_1190297; PARTREV 03.11.2020
J3: Barrel_Jack; BarrelJack_Wuerth_6941xx301002
L1, L2: 33u; IND_VLS6045AF-330M
R1, R2: 100k; R_0402_1005Metric_Pad0.72x0.64mm_HandSolder
R3: 10k; R_0402_1005Metric_Pad0.72x0.64mm_HandSolder
R5, R6: 1k; R_0402_1005Metric_Pad0.72x0.64mm_HandSolder
RING1: TestPoint; TestPoint_Bridge_Pitch2.0mm_Drill0.7mm
RV1: 100k; Potentiometer_Bourns_3386P_Vertical
SLEEVE1: TestPoint; TestPoint_Bridge_Pitch2.0mm_Drill0.7mm
TPSP1, TPSP2: TestPoint; TestPoint_Bridge_Pitch2.0mm_Drill0.7mm
U1: TPA3136D2PWPR; IC_TPS61196PWPRQ1

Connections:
/BSNR: C12.1, U1.17 (BSPR), U1.21 (BSNR)
/BSPL: C11.1, U1.22 (BSNL), U1.26 (BSPL)
/GVDD: C9.2, RV1.1, U1.9 (GVDD)
/OUTPL: C11.2, L1.1, U1.23 (OUTNL), U1.25 (OUTPL)
/OUTPR: C12.2, L2.1, U1.18 (OUTPR), U1.20 (OUTNR)
/RINN: C10.1, U1.11 (RINN)
/RINP: C8.1, U1.12 (RINP)
/SPK+: C13.1, J2.2_1, J2.2_2, L1.2, TPSP1.1
/SPK-: C14.1, J2.1_1, J2.1_2, L2.2, TPSP2.1
AMPIN: C8.2, R5.1, R6.2
GND: C1.2, C2.2, C3.1, C4.2, C5.2, C6.1, C7.2, C9.1, C10.2, C13.2, C14.2, GND1.1, J1.S, J3.2, R3.1, U1.5 (NC), U1.6 (NC), U1.8 (GND-2), U1.13 (NC), U1.19 (GND-1), U1.24 (GND), U1.29 (PAD)
unnamed: J1.R, R5.2, RING1.1
unnamed: J1.T, R6.1, SLEEVE1.1
unnamed: R3.2, RV1.3
unnamed: R2.2, U1.14 (PBTL)
unnamed: RV1.2, U1.10 (PLIMIT)
VCC: C1.1, C2.1, C3.2, C4.1, C5.1, C6.2, C7.1, J3.1, R1.1, R2.1, U1.7 (AVCC), U1.15 (PVCCR), U1.16 (PVCCR), U1.27 (PVCCL), U1.28 (PVCCL)
/SHUTDOWN: R1.2, U1.1 (SD), U1.2 (FAULT)

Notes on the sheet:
Mono Summing Input
Selected values for driving 8ohm load
Line Level
Selected for f_{c} = 20 Hz
Output to 8ohm speaker
Power Supply Filtering & Decoupling
Power Input
TI 20W Class-D Audio Amplifier
Output Filtering
4.5-14 V DC

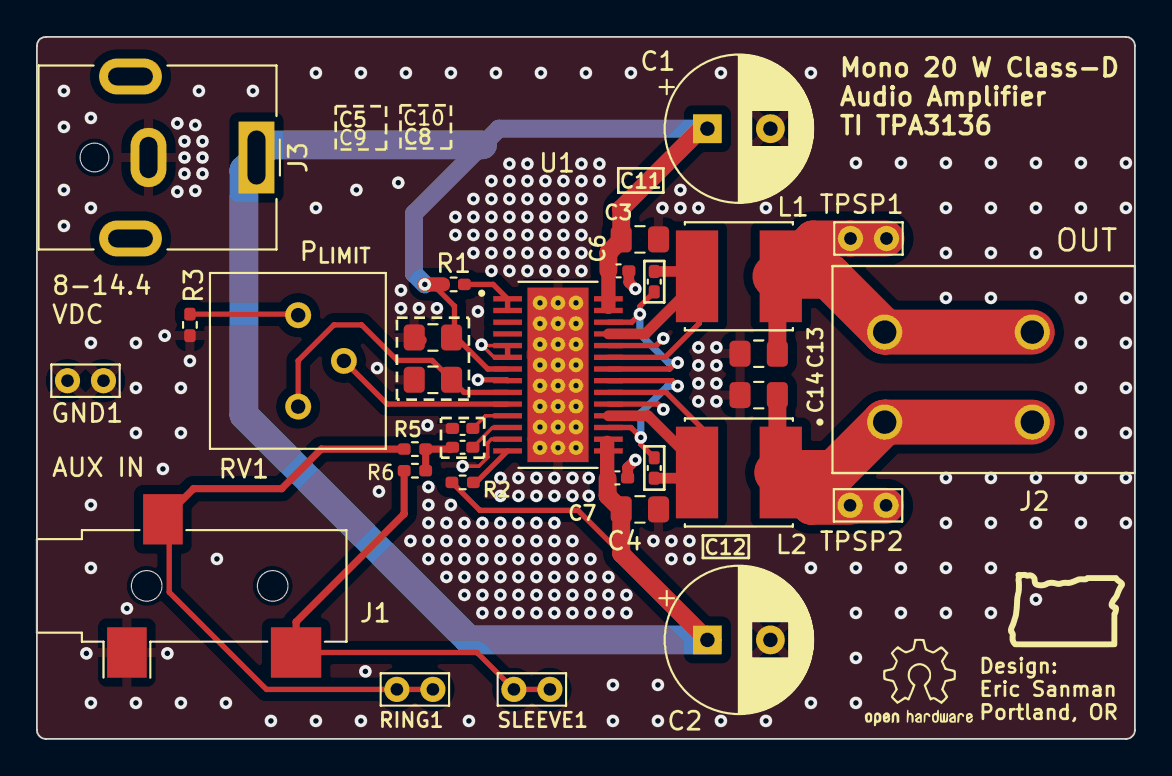
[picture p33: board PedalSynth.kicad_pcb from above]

Board: 2 copper layers, 61.0 x 39.0 mm, 31 parts (0 on the bottom side), 18 nets.

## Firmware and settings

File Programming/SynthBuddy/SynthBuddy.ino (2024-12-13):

#include <Arduino.h>
#include <SPI.h>
#include <Wire.h>
#include <Adafruit_GFX.h>
#include <Adafruit_SSD1306.h>

#define OLED_RESET 4
Adafruit_SSD1306 display(OLED_RESET);

#define PWM_PIN 23
#define PWM_RESOLUTION 8
#define PWM_FREQ 50000

const int buttonPins[] = {12, 14, 27, 26, 25, 33, 32};
const float frequencies[] = {130.8, 146.8, 164.8, 174.2, 196.0, 220.0, 246.94};
const int numButtons = sizeof(buttonPins) / sizeof(buttonPins[0]);

hw_timer_t *timer = NULL;
volatile bool waveActive = false;
volatile uint8_t sineIndex = 0;
volatile float currentFrequency = 0;
const int sineTableSize = 256;
uint8_t sineTable[sineTableSize];

void IRAM_ATTR onTimer() {
  if (waveActive) {
    uint8_t pwmValue = sineTable[sineIndex];
    ledcWrite(0, pwmValue);
    sineIndex = (sineIndex + 1) % sineTableSize;
  } else {
    ledcWrite(0, 0); // Turn off PWM when no button is pressed
  }
}

void setup() {
  // Initialize OLED display
  display.begin(SSD1306_SWITCHCAPVCC, 0x3C);
  display.clearDisplay();

  // Initialize sine wave lookup table
  for (int i = 0; i < sineTableSize; i++) {
    sineTable[i] = (sin(2 * PI * i / sineTableSize) + 1.0) * 127.5;
  }

  // Configure buttons as inputs with pull-up resistors
  for (int i = 0; i < numButtons; i++) {
    pinMode(buttonPins[i], INPUT_PULLUP);
  }

  // Configure PWM on the output pin
  ledcSetup(0, PWM_FREQ, PWM_RESOLUTION);
  ledcAttachPin(PWM_PIN, 0);

  // Initialize timer
  timer = timerBegin(0, 80, true); // 80 prescaler for 1 µs ticks
  timerAttachInterrupt(timer, &onTimer, true);
  timerAlarmWrite(timer, 100, true); // 100 µs (10 kHz timer frequency)
  timerAlarmEnable(timer);
}

void loop() {
  waveActive = false;
  for (int i = 0; i < numButtons; i++) {
    if (digitalRead(buttonPins[i]) == LOW) {
      waveActive = true;
      currentFrequency = frequencies[i];
      sineIndex = 0;

      // Adjust timer frequency for current sine wave
      timerAlarmWrite(timer, (1000000 / currentFrequency) / sineTableSize, true);

      // Update OLED display with current frequency
      display.clearDisplay();
      display.setTextSize(1);
      display.setTextColor(WHITE);
      display.setCursor(0, 0);
      display.println("SynthBuddy");

      display.setCursor(0, 16);
      display.setTextSize(1);
      display.println("Frequency:");
      display.print(currentFrequency);
      display.println(" Hz");

      display.display();
      break;
    }
  }
}

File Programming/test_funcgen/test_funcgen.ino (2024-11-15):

#include <driver/ledc.h>

// Define PWM properties
#define PWM_RESOLUTION 8     // Resolution in bits (0-255)
#define PWM_CHANNEL 0        // PWM channel number
#define PWM_PIN 25           // Pin for PWM output

// Button pins
#define SINE_BUTTON_PIN 2
#define SQUARE_BUTTON_PIN 4
#define TRIANGLE_BUTTON_PIN 16
#define FREQ_BUTTON_PINS {17, 18, 19, 21, 22} // Array of pins for frequency selection

// Variables for waveform generation
const int sineTableSize = 256;
uint8_t sineTable[sineTableSize];
uint8_t triangleTable[sineTableSize];
uint8_t squareTable[sineTableSize];

int currentFrequency = 0; // Index to store current frequency
int currentWaveform = 0;  // 0 = sine, 1 = square, 2 = triangle

// Frequency options in Hz
const int frequencies[] = {1000, 2000, 3000, 4000, 5000};

// Function to generate sine wave lookup table
void generateSineTable() {
  for (int i = 0; i < sineTableSize; i++) {
    sineTable[i] = (sin(2 * PI * i / sineTableSize) * 127) + 128; // Scaled to 0-255
  }
}

// Function to generate triangle wave lookup table
void generateTriangleTable() {
  for (int i = 0; i < sineTableSize; i++) {
    if (i < sineTableSize / 2) {
      triangleTable[i] = (i * 255) / (sineTableSize / 2);
    } else {
      triangleTable[i] = 255 - ((i - sineTableSize / 2) * 255) / (sineTableSize / 2);
    }
  }
}

// Function to generate square wave lookup table
void generateSquareTable() {
  for (int i = 0; i < sineTableSize; i++) {
    squareTable[i] = (i < sineTableSize / 2) ? 0 : 255;
  }
}

// Setup PWM and input buttons
void setup() {
  Serial.begin(115200);

  // Setup PWM on the specified pin
  ledcSetup(PWM_CHANNEL, frequencies[currentFrequency], PWM_RESOLUTION);
  ledcAttachPin(PWM_PIN, PWM_CHANNEL);

  // Generate wave tables
  generateSineTable();
  generateTriangleTable();
  generateSquareTable();

  // Setup button pins as input with internal pull-up resistors
  pinMode(SINE_BUTTON_PIN, INPUT_PULLUP);
  pinMode(SQUARE_BUTTON_PIN, INPUT_PULLUP);
  pinMode(TRIANGLE_BUTTON_PIN, INPUT_PULLUP);

  int freqButtons[] = FREQ_BUTTON_PINS;
  for (int i = 0; i < 5; i++) {
    pinMode(freqButtons[i], INPUT_PULLUP);
  }
}

void loop() {
  // Check waveform selection buttons
  if (digitalRead(SINE_BUTTON_PIN) == LOW) {
    currentWaveform = 0;
    Serial.println("Sine Wave Selected");
    delay(200); // Debounce delay
  } else if (digitalRead(SQUARE_BUTTON_PIN) == LOW) {
    currentWaveform = 1;
    Serial.println("Square Wave Selected");
    delay(200);
  } else if (digitalRead(TRIANGLE_BUTTON_PIN) == LOW) {
    currentWaveform = 2;
    Serial.println("Triangle Wave Selected");
    delay(200);
  }

  // Check frequency selection buttons
  int freqButtons[] = FREQ_BUTTON_PINS;
  for (int i = 0; i < 5; i++) {
    if (digitalRead(freqButtons[i]) == LOW) {
      currentFrequency = i;
      ledcSetup(PWM_CHANNEL, frequencies[currentFrequency], PWM_RESOLUTION);
      ledcAttachPin(PWM_PIN, PWM_CHANNEL);
      Serial.print("Frequency set to: ");
      Serial.println(frequencies[currentFrequency]);
      delay(200); // Debounce delay
    }
  }

  // Generate the selected waveform at the selected frequency
  for (int i = 0; i < sineTableSize; i++) {
    switch (currentWaveform) {
      case 0:
        ledcWrite(PWM_CHANNEL, sineTable[i]);
        break;
      case 1:
        ledcWrite(PWM_CHANNEL, squareTable[i]);
        break;
      case 2:
        ledcWrite(PWM_CHANNEL, triangleTable[i]);
        break;
    }
    delayMicroseconds(1000000 / (frequencies[currentFrequency] * sineTableSize)); // Adjust for waveform timing
  }
}

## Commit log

2024-10-18 add Class D amplifier
    [Class D Amplifier.kicad_pcb, Class D Amplifier.kicad_sch]
2024-10-18 generate amplifier schematic
    [Class D Amplifier.kicad_sch, TPA3136D2PWPR.step]
2024-10-18 class D schematic update
    [Class D Amplifier.kicad_sch]
2024-10-18 update nets
    [Class D Amplifier.kicad_sch]
2024-10-20 Create PCB files
    [Class D Amplifier.kicad_pcb, Class D Amplifier.kicad_sch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]
2024-10-20 pushing PCB changes
    [Class D Amplifier.kicad_pcb]
2024-10-20 Layout improvements for amp
    [Class D Amplifier.kicad_pcb, Class D Amplifier.kicad_sch]
2024-10-20 fix folder typo
    [Class D Amplifier.kicad_pcb, Class D Amplifier.kicad_sch, TPA3136D2PWPR.step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]
2024-10-21 board changes
    [Class D Amplifier.kicad_pcb]
2024-10-21 add PDS, modified amp footprint, organizational changes
    [Class D Amplifier.kicad_pcb, Class D Amplifier.kicad_sch]
2024-10-22 getting kicad organized
    renamed root schematic, creating sub schematic for amplifier
    [PedalSynth.kicad_pcb, PedalSynth.kicad_sch, TPA3136D2PWPR.step]
2024-10-23 add kicad corner
    [PedalSynth.kicad_sch]
2024-10-23 Update KiCad Corner.md
2024-10-23 update via stitching
    [PedalSynth.kicad_pcb]
2024-10-24 update to v8
    [PedalSynth.kicad_pcb, PedalSynth.kicad_sch]
2024-10-24 Module Schematics for Parts of overall Project
    [Distortion.kicad_sch, Filter.kicad_sch, Tremolo.kicad_sch]
2024-10-24 update amp schematic and pcb
    [PedalSynth.kicad_pcb, PedalSynth.kicad_sch, VLS6045AF-330M.step]
2024-10-25 r1.0 amp pcb
    [PedalSynth-B_Cu.gbr, PedalSynth-B_Mask.gbr, PedalSynth-B_Paste.gbr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]
2024-10-28 update kicad corner
2024-10-28 reference materials for chorus effect
2024-10-28 Chorus Schematic Upload
    [Chorus.kicad_sch]
2024-10-28 Noise Filter schematic with component Values
    [Filter.kicad_sch]
2024-10-28 Added in Specific Op amp model.
    [Chorus.kicad_sch]
2024-10-28 Fuzz Schematic Upload
    [Fuzz.kicad_sch]
2024-10-30 Entire Preliminary Schematic Project Folder
    [Amp.kicad_sch, Chorus.kicad_sch, Distortion.kicad_sch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]
2024-10-30 Minor changes to schematic wiring
    [ECE 411 Project.kicad_sch, ESP32 & OLED.kicad_sch]
2024-10-30 Final Touches to Preliminary Schematic
    Created Symbol for Small OLED screen and finalized input/output connections for each module
    [ECE 411 Project.kicad_sch, ESP32 & OLED.kicad_sch, Filter.kicad_sch]
2024-11-03 kicad business
    [Amp.kicad_sch, Chorus.kicad_sch, ECE 411 Project.kicad_sch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]
2024-11-04 amp changes
    [PedalSynth.kicad_sch]
2024-11-04 update stuff
    [PedalSynth.kicad_pcb]
2024-11-07 add psu and fix schematic
    [Chorus.kicad_sch, ECE 411 Project.kicad_sch, Fuzz.kicad_sch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]
2024-11-07 filter changes
    [Amp.kicad_sch, Chorus.kicad_sch, ECE 411 Project.kicad_sch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]
2024-11-07 schematic, start layout
    [Amp.kicad_sch, Chorus.kicad_sch, ECE 411 Project.kicad_pcb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]
2024-11-07 export pdfs
    [ECE 411 Project.kicad_pcb]
2024-11-08 update kicad
    [ECE 411 Project.kicad_pcb, ECE 411 Project.kicad_sch, Fuzz.kicad_sch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]
2024-11-12 Create ~ECE 411 Project.kicad_sch.lck
2024-11-13 update BOM
    [Amp.kicad_sch, Chorus.kicad_sch, ECE 411 Project.kicad_sch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]
2024-11-13 bom changes
    [Amp.kicad_sch, ECE 411 Project.kicad_sch, ESP32 & OLED.kicad_sch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]
2024-11-14 Created Bill of Materials for Project
    [Team 8 Bill Of Materials.xlsx]
2024-11-14 add switch to schematic
    [Amp.kicad_sch, ECE 411 Project.kicad_sch]
2024-11-14 PCB V2!!!
    [Amp.kicad_sch, Chorus.kicad_sch, ECE 411 Project.kicad_pcb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]
2024-11-14 DRAFT PACKAGE
    [Amp.kicad_sch, Chorus.kicad_sch, ECE 411 Project.kicad_pcb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]
2024-11-15 oled test & schematic update
    [ECE 411 Project.kicad_sch]
2024-11-15 schematic changes
    [ECE 411 Project.kicad_sch, ESP32 & OLED.kicad_sch]
2024-11-16 schematic update
    [Amp.kicad_sch, ECE 411 Project.kicad_pcb, ECE 411 Project.kicad_sch]
2024-11-18 pcb amp revision
    [Amp.kicad_sch, Chorus.kicad_sch, ECE 411 Project.kicad_pcb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]
2024-11-18 pcb redo b2.1
    [Chorus.kicad_sch, ECE 411 Project.kicad_pcb, ECE 411 Project.kicad_sch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]
2024-11-18 new space-optimized PCB layout
    [ECE 411 Project.kicad_pcb, ECE 411 Project.kicad_sch, ESP32 & OLED.kicad_sch]
2024-11-18 add testpoints
    [Amp.kicad_sch, ECE 411 Project.kicad_pcb, ECE 411 Project.kicad_sch]
2024-11-19 update diode footptint, rounding edge cuts, some stitching
    [ECE 411 Project.kicad_pcb, ECE 411 Project.kicad_sch, ESP32 & OLED.kicad_sch]
2024-11-19 pcb finalization
    [ECE 411 Project.kicad_pcb, ECE 411 Project.kicad_sch]
2024-11-19 pcb madness
    [ECE 411 Project.kicad_pcb, ECE 411 Project.kicad_sch, ESP32 & OLED.kicad_sch]
2024-11-20 adding chorus test poiunts, touch ups
    [Chorus.kicad_sch, ECE 411 Project.kicad_pcb, ECE 411 Project.kicad_sch]
2024-11-21 FINAL DESIGN PACKAGE
    [Chorus.kicad_sch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]
2024-11-21 remove build folder to appease andrew
    [ECE 411 Project-B_Cu.gbr, ECE 411 Project-B_Mask.gbr, ECE 411 Project-B_Paste.gbr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]
2024-11-22 minor formatting updates
    [Amp.kicad_sch, Chorus.kicad_sch, ECE 411 Project.kicad_pcb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]
2024-11-22 add label to U6
    [ESP32 & OLED.kicad_sch]
2024-12-12 Updated Gantt Chart to reflect current progress
2024-12-13 PWM Signal and OLED Code
